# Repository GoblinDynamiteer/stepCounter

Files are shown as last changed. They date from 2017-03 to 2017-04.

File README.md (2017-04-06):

<h1>stepCounter</h1>
<h2>Pocket Pedometer</h2>  

---

**Student project for course "Programming of embedded systems"**   
*Mjukvaruutvecklare inbyggda system*  
*Mölk Utbildning, Mjärdevi - Linköping*  

Members  
[Simon Karlsson](https://www.linkedin.com/in/simon-karlsson-54509aa9/)  
[Johan Kämpe](https://www.linkedin.com/in/johankampe/)  
[Dennis Bunne](https://www.linkedin.com/in/dennis-bunne-259a9783/)  

---

**Description:**  
Simple pedometer built with an Atmel Atmega328p MCU and 3-axis accelerometer.  
Steps are displayed on a small display.

---

*Current features:*
- Pocket wearable
- Battery powered
- Displays steps on display
- Modular - Support for three I2C devices

*Future goals / extras:*
- Smaller size
- Better step detection
- Shoe-wearable
- Bluetooth / phone-app
- Reset / on-off / screen-on switches
- Modularization (I2C devices)
- Screen sleep mode
- Long battery life
- 3D printed housing

---

Current Parts:
- Atmel Atmega328p
- Crystal oscillator 16MHz
- 2x Capacitors 22pF
- 28 pin MCU socket
- MPU-9250 Gyro / Accelerometer / Compass Unit
- Grove connectors for I2C-modules
- SSD1306 Display
- 2x Resistors 4.7kOhm for I2C Line Pull up
- LiPo 18650 Battery
- 18650 Battery holder
- Mouse housing for prototype

---

**Photos:**  
MPU-9250 Accelerometer data test with Arduino Uno  
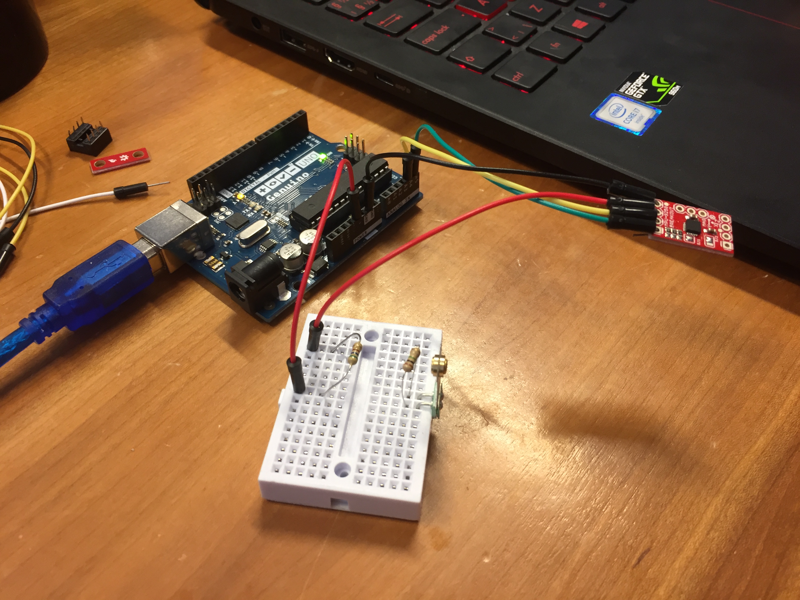
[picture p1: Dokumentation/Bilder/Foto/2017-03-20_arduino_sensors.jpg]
MPU-9250


Soldered board with connected I2C modules (Display and Accelerometer)
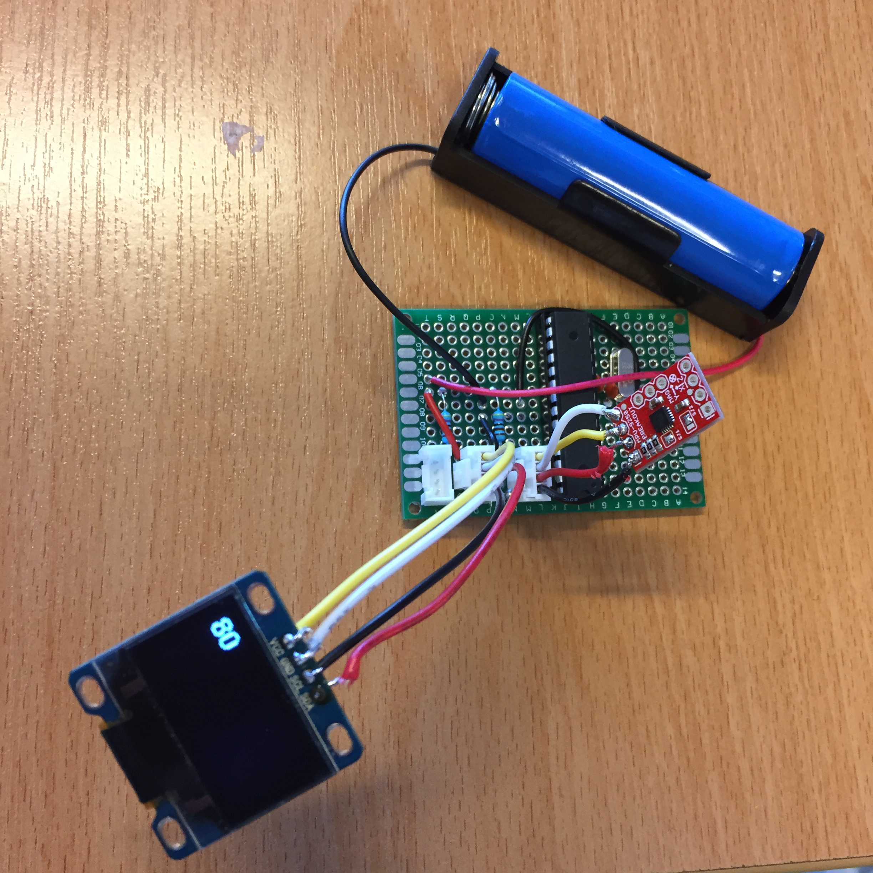
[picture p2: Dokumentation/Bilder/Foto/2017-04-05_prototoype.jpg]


Backside of board and disconnected I2C modules
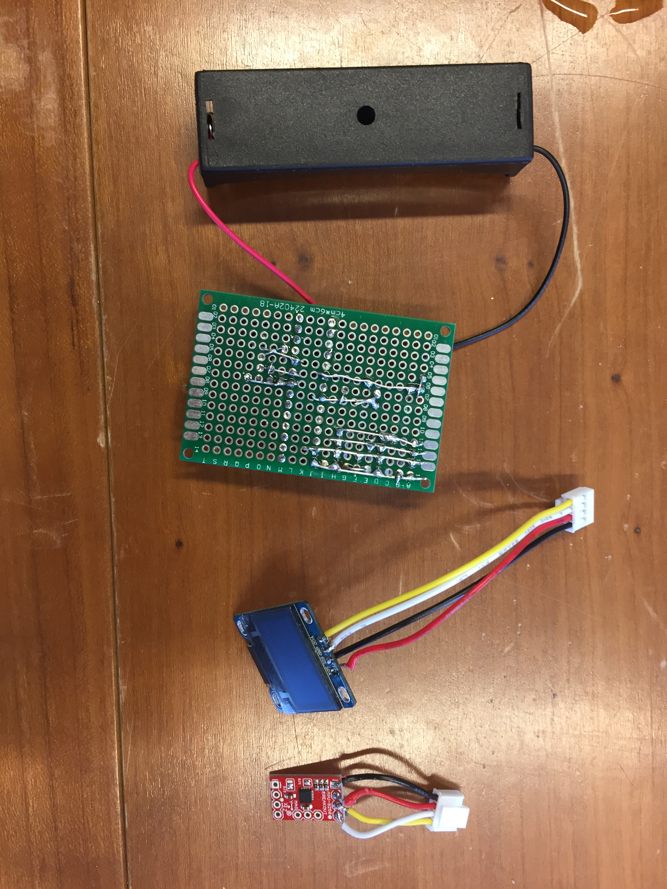
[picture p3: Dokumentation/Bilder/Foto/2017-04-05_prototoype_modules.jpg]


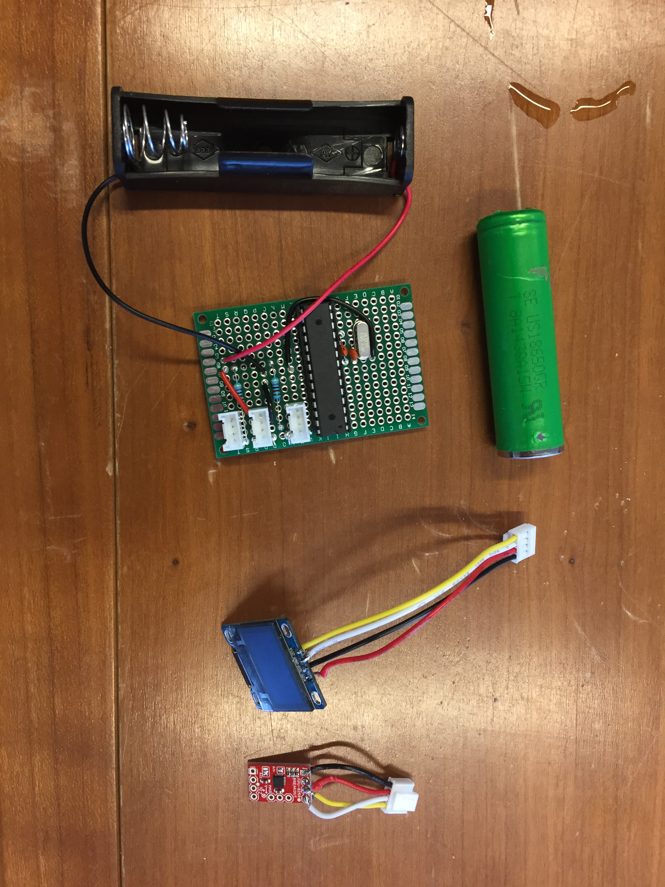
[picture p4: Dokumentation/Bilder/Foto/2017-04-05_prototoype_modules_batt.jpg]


Housing made of cannibalized mouse, tape, glue.
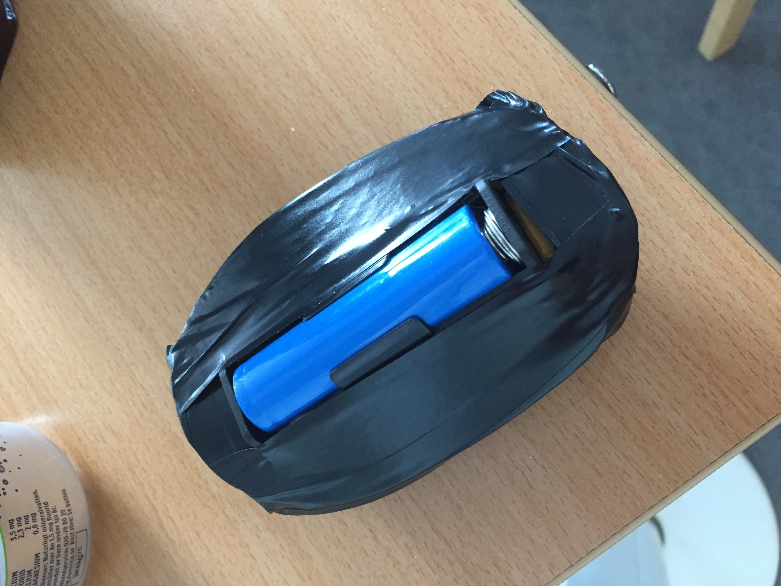
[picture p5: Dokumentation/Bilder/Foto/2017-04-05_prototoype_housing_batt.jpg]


Housing front
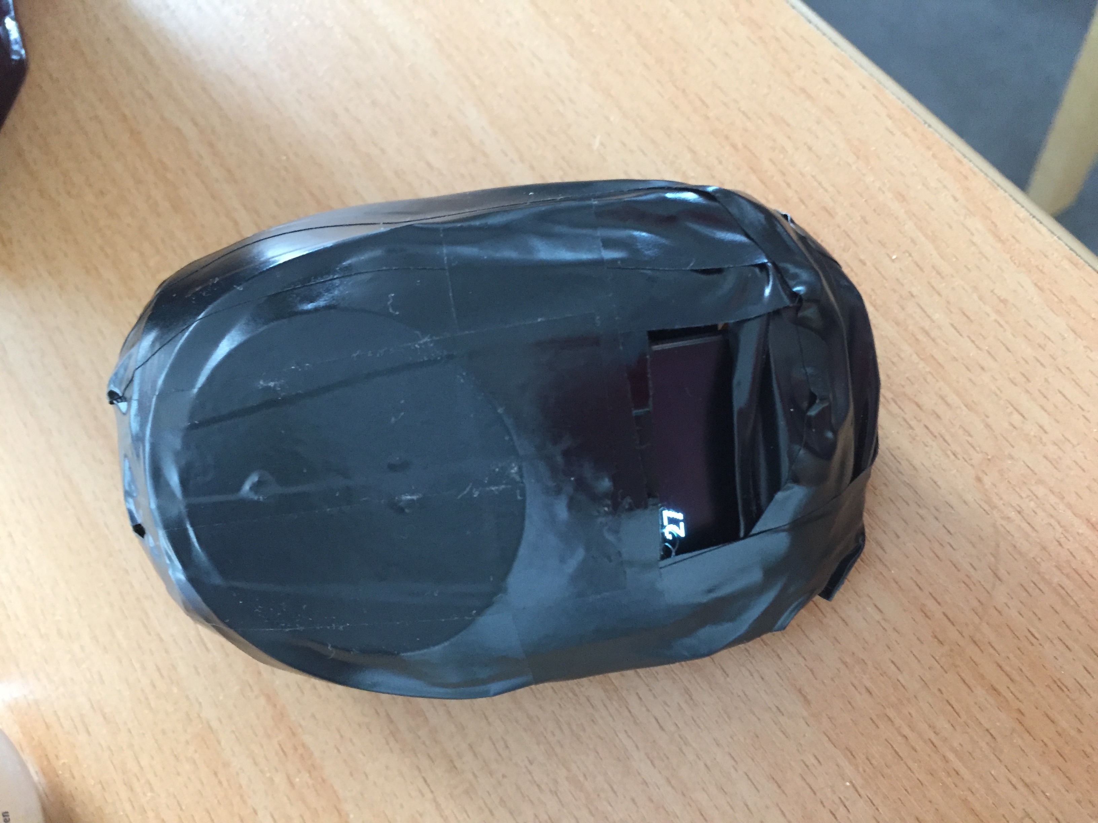
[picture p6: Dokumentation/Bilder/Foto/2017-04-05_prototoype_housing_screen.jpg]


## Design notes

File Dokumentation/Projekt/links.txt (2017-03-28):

http://www.embedds.com/programming-avr-i2c-interface/
https://github.com/g4lvanix/I2C-master-lib
http://www.nongnu.org/avr-libc/user-manual/group__twi__demo.html
http://playground.arduino.cc/Main/WireLibraryDetailedReference
https://learn.sparkfun.com/tutorials/micro-oled-breakout-hookup-guide
https://github.com/thaletterb/ssd1306_avr8

https://www.conrad.se/RC-Batteripack-%28LiPo%29-Hubsan-3.7-V-380-mAh-Flatstiftskontakt.htm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
https://www.conrad.se/RC-Batteripack-%28LiPo%29-ACME-3.7-V-600-mAh-Flatstiftskontakt.htm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
https://www.batteriexperten.com/sv/artiklar/cr2477-panasonic-1-pack.html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

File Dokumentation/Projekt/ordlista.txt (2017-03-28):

PWM: Port(ar) på Atmega328p etc. Pulse Width Modulation - Sätt att simulera analog signal med digital output
AREF: Analog Reference, port på Atmega328p etc
Pull Up-resistor: En högohmig resistor som kopplas mellan signalkabel och +V. Förhindrar störningar (etc?)
MPU-9250: Multichip Module (MCM) som har 3-axel gyro, 3-axel accelerometer, 3-axel magnetometer och DMP (Digital Motion Processor)
Accelerometer: En typ av mätgivare vilken ger ifrån sig en elektrisk signal som på något sätt är proportionell mot den hastighetsförändring (acceleration) givaren utsätts för. 
Magnetometer: Ett vetenskapligt mätinstrument som används för att mäta styrkan och/eller riktningen hos magnetfältet runt instrumentet. Kan användas för kompassfunktionalitet.
VDD: Benämning på anslutning för strömkälla på enheter (IC-kretsar etc), pluspol.

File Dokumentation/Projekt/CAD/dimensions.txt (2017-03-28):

Atmega328p: 		37.4 x 6.76 x 3.28 mm
Micro OLED:		Skärm: 18.5 x 18 mm
			Kort: 21 x 20 mm
MPU-9250:		MÄT!
ESP8266:		MÄT!
KopplingsPlatta:	TBD/CAD

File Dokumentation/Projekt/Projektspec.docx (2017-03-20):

# Stegräknare

Projektspecifikation

2017-03-20

Dennis Bunne
Johan Kämpe
Simon Karlsson

Mjukvaruutvecklare inbyggda system
Mölk Utbildning

# Projektmål

Målet är att bygga en portabel batteridriven stegräknare som kan användas vid löpning eller promenader etc. Initialt används en LCD-display för att visa antal steg. Stegen ska avläsas med hjälp av en accelerometer, eller alternativt med en vibrationssensor.

Stegräknaren kan senare utökas med hastighetsmätare, tidräkning, ESP-modul för att skicka data m.m, om funktionen med stegräkning fungerar korrekt.

# Prototyp

Ett första steg i projektet är att bygga en prototyp med hjälp av ett Arduino-kort och en accelerometer, alternativt en vibrationssensor.

Vanliga hopp kommer användas för att se att accelerometern/vibrationssensorn kan avläsa steg på ett korrekt sätt.

Data från accelerometern skrivs ut i Arduino IDEts Serial monitor.

Strömförsörjning sker via kabel.

# Moduler

Basenheten kommer bestå av en fristående MCU eller en Arduino Nano, samt strömförsörjning. Moduler kopplas in med kontakter.

En första modul är accelerometern eller vibrationssensorn.

Extra moduler: ESP, display.

# Avgränsning

Stegräknaren ska enbart behöva fungera i 20 minuter på batteriförsörjning.

# Förutsättningar

Projektet ska vara färdigställt senast 2017-05-05.

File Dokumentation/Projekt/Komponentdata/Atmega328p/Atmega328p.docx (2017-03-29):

UART är en förkortning för "Universal Asynchronous Receiver/Transmitter" och är en datorhårdvara som omvandlar parallell data till seriell data. En UART tar en byte data och överför dessa sekventiellt bit för bit till en annan UART i andra änden som sätter ihop dessa till en byte igen. Start- och stoppbitar används för att signalera när data skickas.

En synkron variant finns också, USART eller "Universal Synchronous/Asynchronous Receiver/Transmitter". Den använder inte start- och stoppbitar utan en delad klocksignal håller reda på när bitarna kommer. Synkron kommunikation är effektivare eftersom endast databitar(block) skickas mellan sändare och mottagare, men det kräver också att sändare och mottagare har tillgång till samma klocksignal.

USART har även en data/clock recovery som används för att sätta buad rate clock hastigheten(Baud rate (in bits per second, bps) och ta emot asynchronous bitar på RxDn pin. Om man får felmeddelanden på UARTen så brukar de vara pga att clock frekvensen inte är satt till rätt värde.

TWI - 2-wire Serial Interface. Features

• Simple, yet Powerful and Flexible Communication Interface, only two Bus Lines Needed

• Both Master and Slave Operation Supported

• Device can Operate as Transmitter or Receiver

• 7-bit Address Space Allows up to 128 Different Slave Addresses

• Multi-master Arbitration Support

• Up to 400kHz Data Transfer Speed

• Slew-rate Limited Output Drivers

• Noise Suppression Circuitry Rejects Spikes on Bus Lines

• Fully Programmable Slave Address with General Call Support

• Address Recognition Causes Wake-up When AVR is in Sleep Mode

• Compatible with Philips’ I2C protocol

Det ända som behövs för att koppla 128 olika enheter till TWI (SDA,SCL ) är en pull-up resistor på vardera kanal.

TWI består av 9bits samt en master och en slave. Där master utfärdar ett START/STOPP vilkor, vilket signalerar och ändrar nivån på SDA/SCL kanalerna.

Alla slavenheter som är inkopplade kommer kolla efter SDA kanalen i ACK cykeln(ACK är den 9e biten inte fatt fram så mycket info om det) om det finns datapaket att hämta.

Dessa slavar måste hämta datan från addresser och inte readbit. Använder man readbit skulle det medföra fel om olika slavar skickar data samtidigt.

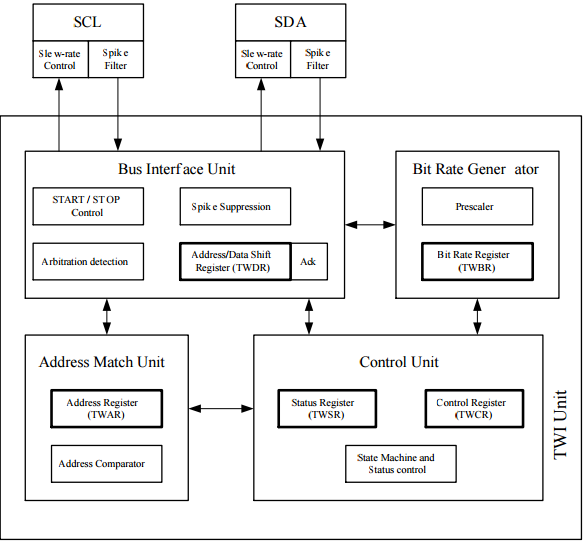
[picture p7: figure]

Bit Rate Generator Unit This unit controls the period of SCL when operating in a Master mode. The SCL period is controlled by settings in the TWI Bit Rate Register (TWBRn) and the Prescaler bits in the TWI Status Register

Bus Interface Unit This unit contains the Data and Address Shift Register (TWDRn), a START/STOP Controller

Address Match Unit The Address Match unit checks if received address bytes match the seven-bit address in the TWI Address Register (TWARn).

Control Unit The Control unit monitors the TWI bus and generates responses corresponding to settings in the TWI Control Register

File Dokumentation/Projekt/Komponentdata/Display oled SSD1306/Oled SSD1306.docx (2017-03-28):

# Oled SSD1306

- Upplösning: 128x64 dot matrix panel
- Spänning: 1.65V till 3.3V IC logic. 7V till 15V för panel driving

Oscillator finns inbyggt. (CLS-pin) Om CLS-pin = HIGH så är den interna oscillatorn vald.
Ändra frekvensen med kommandot D5h A [7:4].

SDAout = D2-pin, SDAin = D1-pin, SCL = D0-pin.

SDA och SCL måste va kopplade med varsin pullupresistor.

SSD1306 has to recognize the slave address before transmitting or receiving any information by the I 2 C-bus. The device will respond to the slave address following by the slave address bit (“SA0” bit) and the read/write select bit (“R/W#” bit) with the following byte format, b7 b6 b5 b4 b3 b2 b1 b0 0 1 1 1 1 0 SA0 R/W#

“SDAIN” and “SDAOUT” are tied together and serve as SDA. The “SDAIN” pin must be connected to act as SDA. The “SDAOUT” pin may be disconnected. When “SDAOUT” pin is disconnected, the acknowledgement signal will be ignored in the I2 C-bus.

Write mode for I2C

1) The master device initiates the data communication by a start condition. The definition of the start condition is shown in Figure 8-8. The start condition is established by pulling the SDA from HIGH to LOW while the SCL stays HIGH.
2) The slave address is following the start condition for recognition use. For the SSD1306, the slave address is either “b0111100” or “b0111101” by changing the SA0 to LOW or HIGH (D/C pin acts as SA0).

3) The write mode is established by setting the R/W# bit to logic “0”.
4) An acknowledgement signal will be generated after receiving one byte of data, including the slave address and the R/W# bit. Please refer to the Figure 8-9 for the graphical representation of the acknowledge signal. The acknowledge bit is defined as the SDA line is pulled down during the HIGH period of the acknowledgement related clock pulse.
5) After the transmission of the slave address, either the control byte or the data byte may be sent across the SDA. A control byte mainly consists of Co and D/C# bits following by six “0” ‘s.
a. If the Co bit is set as logic “0”, the transmission of the following information will

contain data bytes only.
b. The D/C# bit determines the next data byte is acted as a command or a data. If the

D/C# bit is set to logic “0”, it defines the following data byte as a command. If the

D/C# bit is set to logic “1”, it defines the following data byte as a data which will be

stored at the GDDRAM. The GDDRAM column address pointer will be increased by

one automatically after each data write.
6) Acknowledge bit will be generated after receiving each control byte or data byte.
7) The write mode will be finished when a stop condition is applied. The stop condition is also defined in Figure 8-8. The stop condition is established by pulling the “SDA in” from LOW to HIGH while the “SCL” stays HIGH.

The GDDRAM is a bit mapped static RAM holding the bit pattern to be displayed. The size of the RAM is 128 x 64 bits and the RAM is divided into eight pages, from PAGE0 to PAGE7, which are used for monochrome 128x64 dot matrix display, as shown in Figure 8-13.

Sida 25 finns en bild över displayens struktur.

# Display av och på

1. Power ON VDD
2. After VDD become stable, set RES# pin LOW (logic low) for at least 3us (t1) (4) and then HIGH (logic high).

3. After set RES# pin LOW (logic low), wait for at least 3us (t2). Then Power ON VCC. (1)

4. After VCC become stable, send command AFh for display ON. SEG/COM will be ON after 100ms (tAF).

# Kommandon

HEX: 81 A[7:0] För contrast kontroll.
HEX: AE För att sätt igång displayen.
HEX: AF För att stänga av displayen.
HEX: 40~7F Start position ersätt 40 med ett tal mellan 0-63.
HEX D3 A[5:0] Display offset

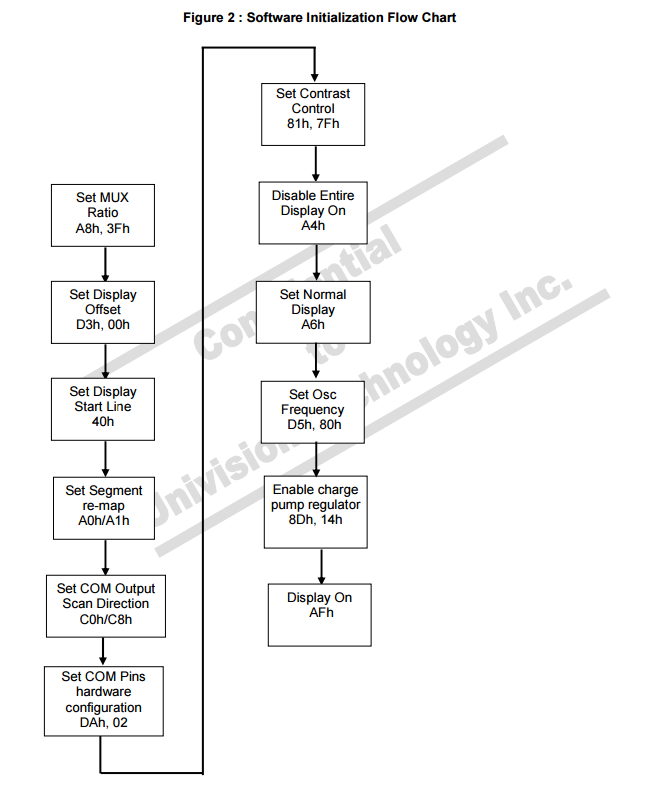
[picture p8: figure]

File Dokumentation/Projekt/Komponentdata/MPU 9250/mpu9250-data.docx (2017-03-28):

# MPU 9250

Information från datablad:
stepCounter\Dokumentation\Komponenter\MPU 9250\MPU-9250-Datasheet.pdf
stepCounter\Dokumentation\Komponenter\MPU 9250\MPU-9250-Register-Map.pdf
stepCounter\Dokumentation\Komponenter\MPU 9250\SparkFun_MPU-9250_Breakout.pdf

# Allmänt

Komponenter innehåller

- 3-axligt (X- Y och Z-riktning) gyroskop
- 3-axlig accelerometer
- 3-axlig magnetometer

# Drivning

Drivs på 2,4V – 3,6V.
OBS - max drivspänning är 4 V, för att undvika att komponenten tar skada.

Strömförbrukning:

Komponent | Normal | Sleep/Low Power
Gyroskop | 3,2 mA | 8 µA
Accelerometer | 450 µA | 8 µA
Alla funktioner påslagna | 3,5 mA

I databladet används en (keramisk X7R) kondensator på 0,1 µF på inspänningen VDD, för en typisk uppkoppling.

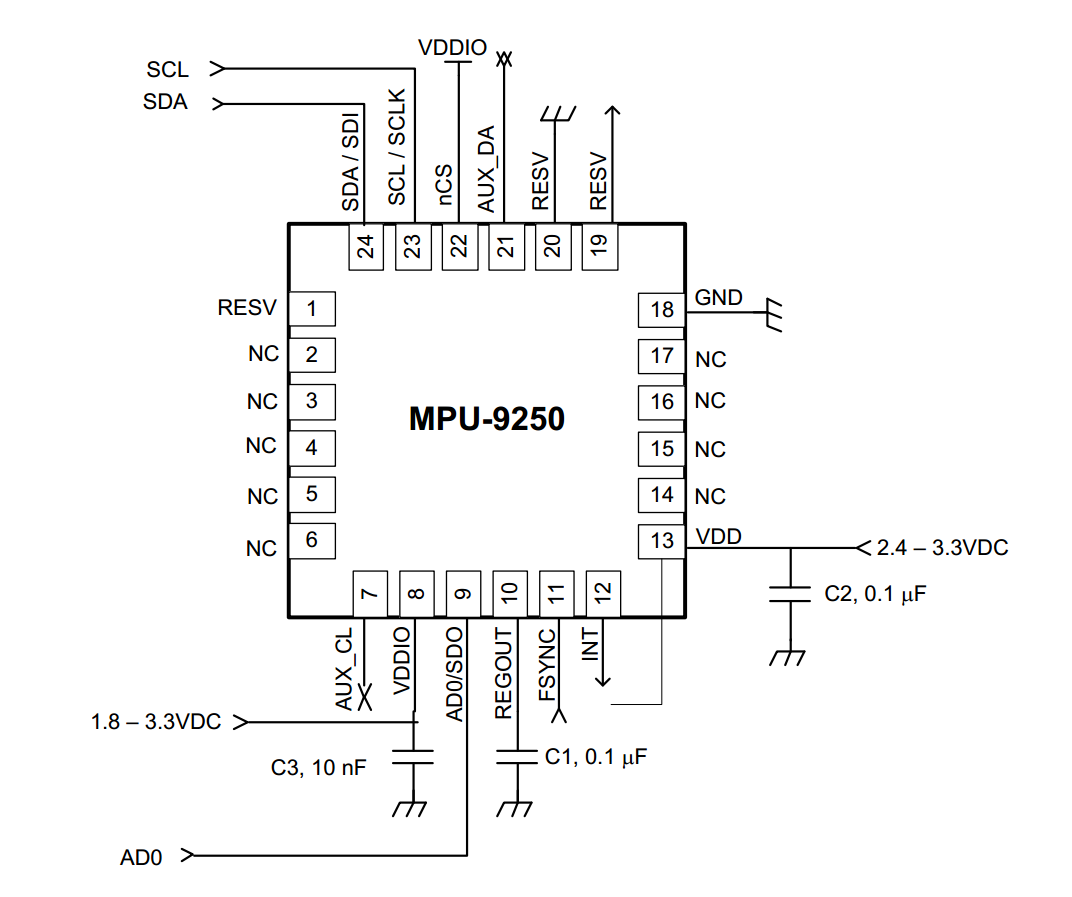
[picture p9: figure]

Bypass capacitor: https://www.solo-labs.com/bypass-capacitors-why-and-how-to-use-them/

# Kommunikation

I2C på 400 kHz (standard-mode) eller 100 kHz (standard mode)
SPI på 1 MHz.

Externa I2C-enheter kan anslutas, och drivas med spänning från VDDIO på 1,71 V till VDD V

I2C-adress: b110100X

Pin AD0 kan/ska sättas till VDD eller GND för att sätta 1/0 för LSB (X) till enhetens I2C-slavadress. Detta innebär att två MPU 9250-enheter kan användas på samma I2C-kanal.
Enl. Sparkfun är denna 0 som standard för deras breakout-board.

# Accelerometer

Startup-tid: 20 ms från sleep mode, 30 ms från påslagning av MPU 9250.

Om enheten placeras på en plan yta ges värden: X, Y: 0 g, Z: +1 g.

# Anslutningar

AUX_CL (7): Anslutning av externa I2C enheter.
AUX_DA (21): Anslutning av externa I2C enheter.
FSYNC (11): Ska kopplas till GND om ej används, enl. datablad
AD0: Sätt till VDD/GND för att styra LSB på I2C-adress. Default 0

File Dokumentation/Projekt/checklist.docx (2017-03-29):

# Projekt Pedometer

Dennis Bunne
Johan Kämpe
Simon Karlsson

# Checklista

VAD | VEM | SLUTDATUM | KLAR
Ta reda på och dokumentera data för: MPU 6050 / MPU 9250 | JOHAN | 2017-03-27 | JA
Ta reda på och dokumentera data för: MCU Atmega328p | SIMON | 2017-03-27 | JA
Ta reda på och dokumentera data för: OLED Display | DENNIS | 2017-03-27 | JA
Undersök och dokumentera koden för kodbibliotek avr_lib_mpu6050 – funktionsbibliotek för MPU 6050 | SIMON JOHAN DENNIS | 2017-03-23 | JA
Dokumentera dimensioner/storlek för samtlig hårdvara | JOHAN | 2017-03-27
Beräkna och dokumentera strömförbrukning för hårdvara | SIMON JOHAN DENNIS | 2017-03-28 | JA
Skapa CAD-modell för prototyp-hölje | JOHAN | 2017-04-03
Bygg hölje utifrån CAD-modell (3D-skrivare?) | SIMON JOHAN DENNIS
Ta reda på lämplig batterityp – Dokumentera beräkning | SIMON | 2017-03-28
Lödning av kontakter – för modularisering | SIMON JOHAN DENNIS | TBD
Montera komponenter på kretskort | SIMON JOHAN DENNIS | TBD
Kom på sätt att visa antal steg med lysdioder – för testning. Dokumentera! | JOHAN | 2017-03-28
Kodning: Bygg funktioner för att hämta data för acceleration för X/Y/Z från MPU | SIMON JOHAN DENNIS | 2017-03-29 | JA
Kodning: Färdigställ kod till leverans 1 | SIMON JOHAN DENNIS | 2017-04-03
Hitta kodbibliotek för OLED-display. | DENNIS | 2017-03-28 | JA
Skapa kretsschema för uppkopplad MPU till Atmega328p och OLED-display. | DENNIS | 2017-03-31
Städa upp i Git-repository. Sortera/namngivning | JOHAN | 2017-03-27 | JA

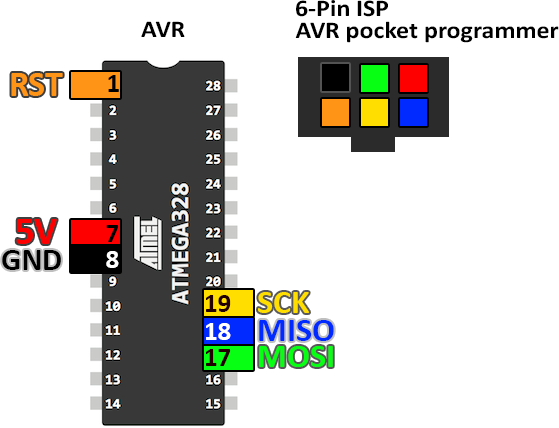
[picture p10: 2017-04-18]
Dokumentation/Projekt/Report/images/pocket_avr_programmer.png

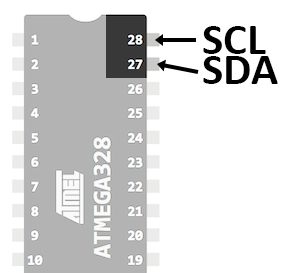
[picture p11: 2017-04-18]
Dokumentation/Projekt/Report/images/atmega_twi_pins.png

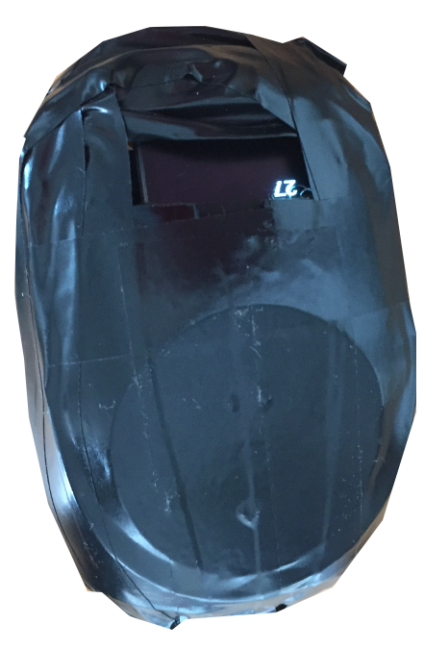
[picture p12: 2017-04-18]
Dokumentation/Projekt/Report/images/proto2_hus2.png

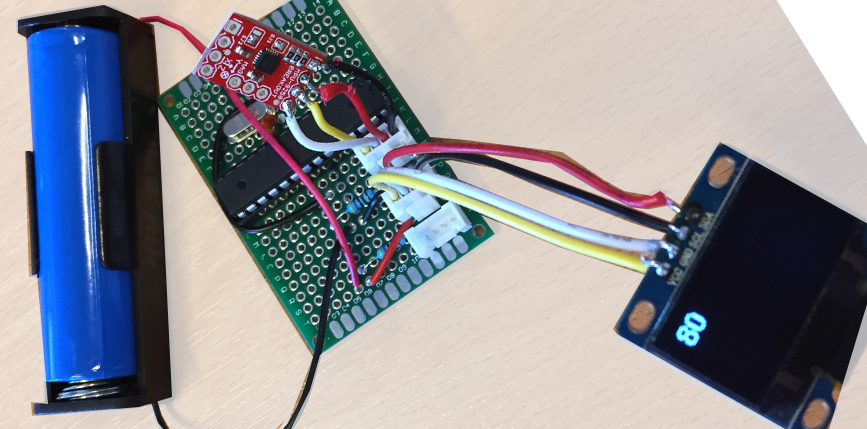
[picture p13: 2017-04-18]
Dokumentation/Projekt/Report/images/proto2_inkopplad.png

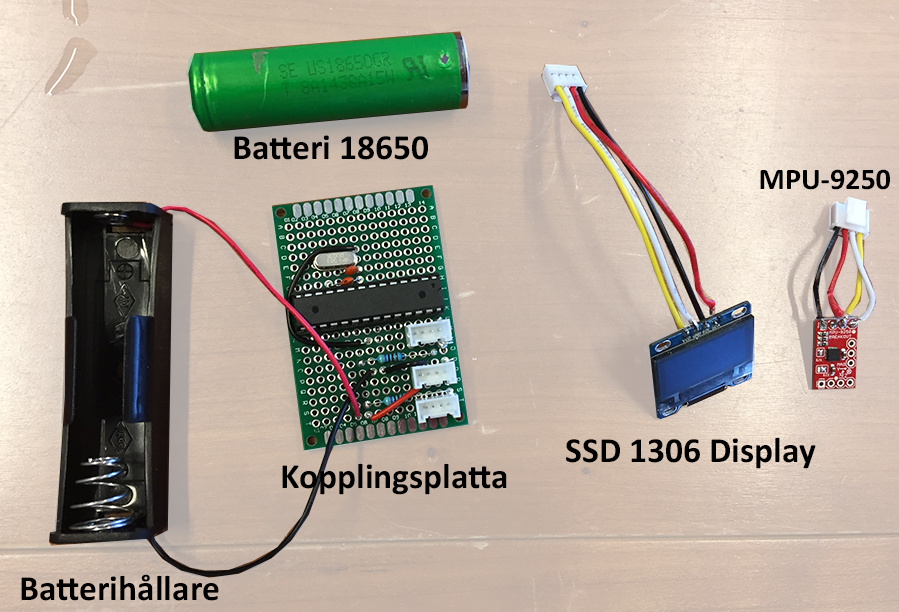
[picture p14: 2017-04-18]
Dokumentation/Projekt/Report/images/proto2_urkopplad.png

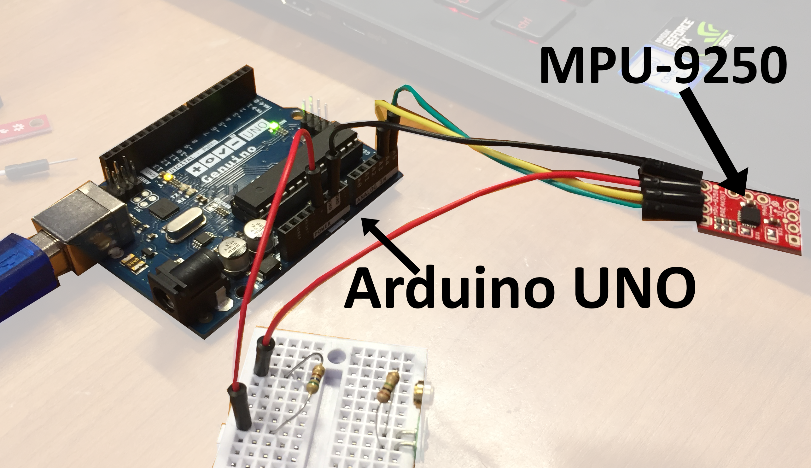
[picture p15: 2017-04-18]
Dokumentation/Projekt/Report/images/proto1.png

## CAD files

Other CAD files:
CAD/Inventor Project/assembly/atmega.iam
CAD/Inventor Project/assembly/socket.iam
CAD/Inventor Project/parts/atmega_mold.ipt
CAD/Inventor Project/parts/atmega_pin-end.ipt
CAD/Inventor Project/parts/atmega_pin-end_MIR.ipt
CAD/Inventor Project/parts/atmega_pin.ipt
CAD/Inventor Project/parts/socket.ipt
CAD/Inventor Project/parts/socket_pin.ipt
CAD/Inventor Project/stepCounterHousing.iam

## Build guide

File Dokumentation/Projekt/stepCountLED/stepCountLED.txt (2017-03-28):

Visa antal steg med LED:

Alternativ / Förslag:

***** 8 st LED *****************************
Binärt med 8 st LED: MAX 1111 1111 = 255 st.

***** 4 st RGB LED *************************
RGB-LED:
AV 00
R  01
G  10
B  11

Behövs 4st för 8 bitar för binär representation.
ingen direkt fördel över 8 st LED, dock behövs ej resistorer.

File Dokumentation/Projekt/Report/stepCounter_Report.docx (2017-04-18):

# Stegräknare

Projekt: Pedometer med AVR

Kurs
Programmering av inbyggda system

2017-04-19

SNYGG BILD?!

Dennis Bunne LinkedIn (https://www.linkedin.com/in/dennis-bunne-259a9783/) | Johan Kämpe LinkedIn (https://www.linkedin.com/in/johankampe/) | Simon Karlsson LinkedIn (https://www.linkedin.com/in/simon-karlsson-54509aa9/)

Mjukvaruutvecklare Inbyggda System
MÖLK Utbildning AB (http://dev.molk.com/)

# Sammanfattning

Skriv när klar

# 1 Inledning

## 1.1 Syfte

Syftet med projektet är att tillverka en bärbar, batteridriven stegräknare. Stegräknaren ska ha modulära enheter, det vill säga att dessa går att ta bort eller byta ut. En modulär enhet kan vara en display, blåtandsmodul eller accelerometer.

En display används för att visa antal tagna steg. Stegen ska avläsas med hjälp av en accelerometer, eller alternativt med en vibrationssensor.

## 1.2 Noteringar och information

Projektet utfördes på under perioden mars till april, 2017.

I rapporten hänvisas själva stegräknaren ofta till som projektet eller produkten.

I rapporten hänvisas MPU-9250-enheten, som används för att mäta acceleration, ofta som MPU-enheten, eller MPU-n.

## 1.3 Bakgrund

### 1.3.1 Definitioner av begrepp och förkortningar

Term | Förklaring
Acceleration | Förändring av hastighet per tidsenhet. Kan vara positiv (hastighetsökning) eller negativ (minskad hastighet).
Arduino UNO | Utvecklingskort.
Atmega328p | En mikrokontroller (MCU) med 28 anslutningar, från tillverkaren Atmel
AVR | Familj av Mikrokontrollers som tillverkas av företaget Atmel.
Bibliotek | En samling av kod-funktioner och/eller definitioner.
Breadboard | Kopplingsplatta, används för att ansluta enheter till varandra.
C | Det programmeringsspråk som används i projektet.
DIL | Dual in-line. Standard för mikrochip med två rader av ben.
Git | Ett versionshanteringssystem
GitHub | Molnlagring för Git-projekt
I²C | Ett sätt att koppla samman enheter, via två ledare: SCL och SDA.
IDE | Integrated Development Environment. Ett datorprogram eller en programsvit som vanligtvis innehåller en texteditor, kompilator och debugger. För att underlätta vid programmering.
ISP | In-system programming, programmering av redan installerade eller inbyggda system.
LED | Light Emitting Diode, lysdiod.
Lib | Se Bibliotek.
Library | Se Bibliotek.
MCU | Microcontroller Unit, se Mikrokontroller.
Mikrokontroller | En liten enchippsdator med CPU, arbetsminne och programminne.
Mikroprocessor | SKRIV
MPU | Microprocessor Unit, Se mikroprocessor
MPU-6050 | Mikroprocessor med sensor för gyro och acceleration i tre riktningar vardera.
MPU-9250 | Mikroprocessor med sensor för gyro, acceleration och kompass i tre riktningar vardera.
Pull up-reistor | Används i logiska kretsar för att se till att en ingång håller sig hög när den inte har någon anslutning.
Reistans | Värdet på ett motstånd / resistor. Anges i Ohm (Ω).
Resistor | Motstånd i elektriska kretsar.
SCL | Se I²C.
SDA | Se I²C.
Serial Monitor | Funktion i Arduinos IDE, för att kommunicera med inkopplad Arduino-enhet. Används ofta för debugging.
Standardbibliotek | Kodbibliotek som alltid är tillgängliga för ett specifikt programspråk. Exempelvis stdio.h för programspråket C.
Stegräknare | En enhet som mäter hur många steg en människa tar
TWI | Se I²C.
Utvecklingsmiljö | Se IDE.
Interrupt | SKRIV

SORTERA+FYLLPÅ

### 1.3.2 Stegräknare

En stegräknare är en vanligtvis portabel enhet. Som mäter hur många steg en människa tar. Den kan användas vid exempelvis löpning, promenad, eller för att se hur många steg en person tar under en dag.

Stegräknare kan också kallas pedometer.

### 1.3.3 I²C

I²C, Inter-Integrated Circuit, är ett sätt att koppla enheter till moderkort, inbyggda system, mobiltelefoner eller andra enheter.

Kommunikation sker via två ledare, SDA (Serial Data Line, datasignal) och SCL (Serial Clock, klocksignal). Flera I²C-enheter kan anslutas till samma SDA- och SCL-ledare.

På en mikrokontroller av typen Atmega328p, är anslutningar 27 och 28, SDA och SCL, respektive.


Figur 1 I²C-ansluting på Atmega328

I²C kallas även TWI, Two Wire Interface, eller IIC.

### 1.3.4 Pull up-resistorer

Pull up-resistorer används i logiska kretsar för att se till att en ingång håller sig hög när den inte har någon anslutning.

Utan pull up kan ingången anta vilket läge som helst, hög eller låg. I projektet används pull up-resistorer för I²C-anslutningarna.

Resistorer som används ska vara av hög resistans.

### 1.3.5 MPU-9250

Enheten som används i projektet för att mäta acceleration kallas MPU-9250 IMU Breakout och är tillverkad av Sparkfun. På enheten finns en MPU-9250.

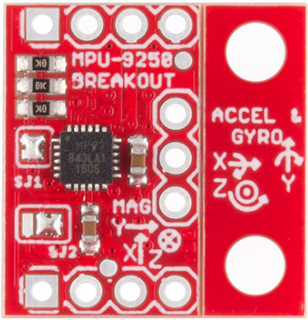
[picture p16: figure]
SparkFun IMU Breakout - MPU-9250
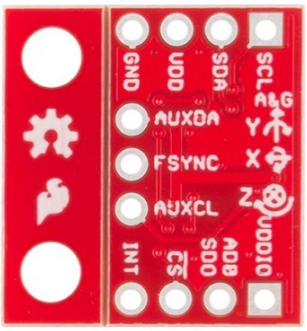
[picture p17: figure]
SparkFun IMU Breakout - MPU-9250

Figur 2 MPU-9250, framsida | Figur 3 MPU-9250, baksida med anslutningsbeteckningar

De anslutningar som används i projektet är VDD och GND för drivning, samt SDA och SCL för I²C-kommunikation.

Länk till tillverkarens produktsida finns i kapitel 1.4.4

### 1.3.6 X-Y-Z-riktning

X, Y och Z används inom projektet för att beskriva riktningar i en tredimensionell miljö. MPU-9250-enheten har sensorer för acceleration i dessa tre riktningar.

När enheten förs åt ett visst håll mäts rörelsens acceleration i denna riktning.

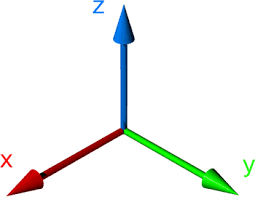
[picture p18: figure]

Figur 4 Riktningar i X- Y och Z-led

## 1.4 Länkar

### 1.4.1 GitHub

Länkar till projektets GitHub-sida

GitHub-sida för projektet
https://github.com/GoblinDynamiteer/stepCounter

GitHub-sida, huvudkod
https://github.com/GoblinDynamiteer/stepCounter/blob/master/Kod/Huvudkod/stepCounter/mpu_conntest/main.c

GitHub-sida, kod för prototyp 1
https://github.com/GoblinDynamiteer/stepCounter/blob/master/Kod/Testkod/Arduino/stepCounterPrototype/stepCounterPrototype.ino

### 1.4.2 Använda funktionsbibliotek

Länkar till bibliotek som har använts i projektets kod

MPU 6050 library
http://davidegironi.blogspot.se/2013/02/avr-atmega-mpu6050-gyroscope-and.html#.WOtTeojyhPY

U8glib
https://github.com/olikraus/u8glib

I2C master library
http://homepage.hispeed.ch/peterfleury/avr-software.html#libs

### 1.4.3 Datablad

Lista!!

### 1.4.4 Andra länkar

MPU-6050 Accelerometer + Gyro
Kodexempel
http://playground.arduino.cc/Main/MPU-6050

SparkFun IMU Breakout - MPU-9250
Produktbeskrivning
https://www.sparkfun.com/products/13762

(https://www.youtube.com/watch?v=5uytAdWNXpI)

# 1 Genomförande och resultat

## 1.1 Använd programvara

Programnamn | Beskrivning
Atmel Studio 7.0 | IDE för att skriva kod och kompilera till Atmel MCU.
Atom | Texteditor, för att skriva och analysera kod.
Git | Versionshanteringsverktyg
GitKraken | Grafiskt gränssnitt (GUI) för Git
Fritzing | Program för att skapa kretsscheman
Microsoft Word | Dokumentering och rapportskrivning
Google Docs | rapportskrivning
AVRDUDE, AVR Downloader/UploaDEr | Program för att ladda upp kompilerad kod till MCU.
AVRDUDESS | Grafiskt gränssnitt (GUI) för AVRDUDE
Autodesk Fusion 360 | CAD-program för att konstruera ett hölje till stegräknaren.

## 1.2 Använd hårdvara

Komponent | Beskrivning
Atmel ATMega328-PU DIP-28N 8-bit MCU | Mikrokontroller.
SparkFun MPU-9250 | Enhet som mäter acceleration i X, Y och Z-riktning. Innehåller även gyroskop, temperatur och kompass-funktionalitet.
Micro OLED Display SSD1306 128x64 | Display med upplösning 128x64 pixlar.
AVR pocket programmer | Enhet för att programmera Atmega-MCU via en dators USB-port.
DIL-hållare 28-pin 0.3" | Sockel för Atmega-MCU
Resistor 4,7kΩ, 2 st. | Pull up-resistorer för I²C-kanaler.
Kristalloscillator 16 MHz | Kopplas till MCU för att öka klockfrekvensen från 1 MHz till 16 MHz
Kondensator 22pF, 2 st. | Används för inkoppling av kristalloscillator.
Litiumbatteri 18650 | Strömförsörjning.
Hållare för litiumbatteri 18650
Grovekontakter med 4-stift | För modularisering av I²C-komponenter.
Kopplingsplatta 60x40 mm | För sammanlödning av komponenter.
Arduino UNO | Prototyping

## 1.3 Avgränsningar

SKRIV/EL EV. TA BORT!!!!!

## 1.4 Metod

### 1.4.1 Skrivning av källkod, kompilering och uppladdning till mikrokontroller

Programmets källkod skrevs i utvecklingsmiljön Atmel Studio, som ett GCC C Executable Project-projekt. Källkoden är skriven i programspråket C.

All egenskriven kod finns i projektets källkodsfil main.c.

Vid kompilering av koden skapas en fil med filändelsen hex i Atmel Studio-projektets Debug-underkatalog. Denna fil laddas upp till mikrokontrollern med datorprogrammet AVRDUDE och programmeringsenheten AVR pocket programmer.

Programmering utförs via ISP, följande anslutningar på mikrokontrollerns används.


Figur 5 Inkoppling av programmeraren till mikrokontrollern

Programmeringsenheten kan även användas som strömkälla.

### 1.4.2 Studie av datablad

Tidigt i projektet samlades datablad in för införskaffad hårdvara. Databladen studerades och relevant information noterades för att kunna användas vid framtagning av prototyp.

I synnerlighet studerades datablad för:

- MPU-9250
- Atmega328p
- OLED Display

### 1.4.3 Studie av funktionsbibliotek

Tidigt i projektet letades diverse färdiga kodbibliotek upp, för projektets hårdvara. Koden i dessa bibliotek studerades, eller användes för att undersöka funktionen hos olika komponenter.

Exempel på bibliotek som studerades eller användes i projektets utveckling:

Bibliotek | Beskrivning och syfte
Wire.h | I²C-bibliotek för Arduino-enheter. För att funktionstesta I²C-enheter med Arduino UNO. Användes även i koden för prototyp 1.
twitest.c | I²C-test/demo för AVR-enheter.
mpu6050.h | MPU-6050 (Accelerometer, mm.) för AVR-enheter.
i2cmaster.h | I²C-bibliotek för AVR-enheter.
ssd1306.c | Kod som använt sig av i2cmaster.h för att skriva ut text till display.

Koden studerades med bland annat texteditorn Atom och i utvecklingsmiljön Atmel Studio.

I Atmel Studio finns möjligheten att automatiskt gå till den fil där ett makro, en funktion eller en variabel är definierad. I bilden nedan utförs detta på funktionen fabs();

Figur 6 Gå till en implementation av ett makro, variabel eller funktion.

## 1.5 Prototyp 1

Projektets första prototyp, kallad prototyp 1, byggdes för att säkerställa att en stegräknare kunde konstrueras med en MPU-9250. MPU-enheten kopplades direkt till en Arduino UNO-enhet via en breadboard.

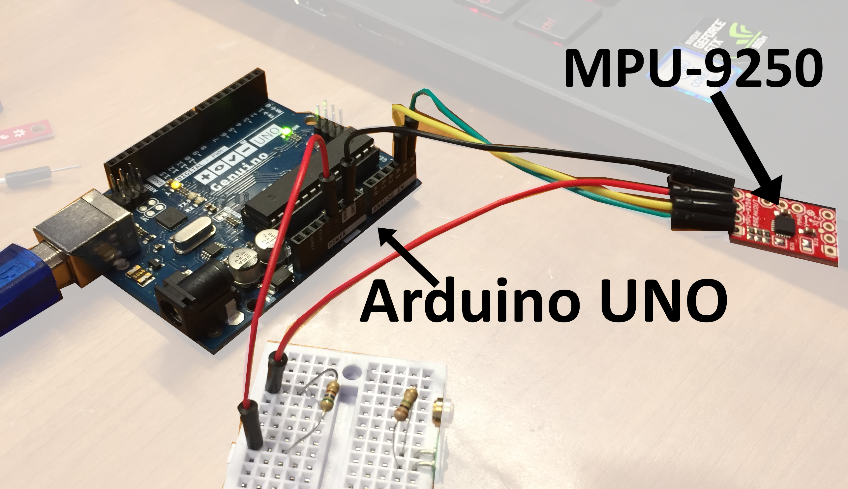
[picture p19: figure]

Figur 7 Uppkoppling av MPU-9250 till Arduino UNO

Koden för prototyp 1 baserades på kod skapad av JohnChi [^1], som skriver ut värden från MPU-6050-enheter till Arduino-utvecklingsmiljöns Serial Monitor. Koden skrevs om så att endast värden för acceleration hämtades, dessa användes för stegräkning.

Funktionsbiblioteket wire.h används för att ansluta MPU-n via I²C till Arduino-enheten. Portarna A4 och A5 används för SDA och SCL, respektive. En resistor med resistansvärdet 560 Ohm används för att ta ner spänningsmatningen till MPU-n från 5V till ca 3V. Enligt tillverkarens hemsida[^2] ska enheten drivas med 2.4 – 3.6 V.

En bärbar dator användes för strömförsörjning och för att avläsa Serial Monitor. Avläsning av steg gjordes genom att placera prototypen i en byxficka och promenera runt.

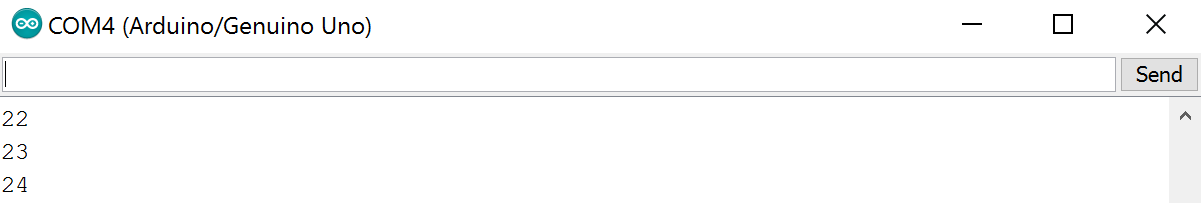
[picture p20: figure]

Figur 8 Utskrift av stegräkning till Serial Monitor

En vibrationssensor testades också för att avläsa steg. Även om den kunde användas för avläsning, valdes den att inte användas, då MPU-enheten ansågs vara mer pålitlig.

Prototyp 1 färdigställdes 2017-03-21

Kopplingsschema för prototyp 1 kan ses i rapportens bilagor.

## 1.6 Prototyp 2

Vid byggnation av prototyp 2 användes en Atmega328p MCU.

En breadboard användes för samtliga inkopplingar innan sammanlödning av enheter påbörjades.

Initialt anslöts MPU-9250-enheten till mikrokontrollerns I²C-anslutningar, med pull up-resistorer på båda kanaler. För att kunna indikera att MPU-n fungerade korrekt användes en blå LED. Lysdioden sattes att lysa när accelerationsdata från MPU-n översteg ett visst värde.

När displayen anslöts och kunde användas för att visa diverse data från MCU-n, blev lysdioden överflödig och användes inte längre.

En kristalloscillator på 16 MHz kopplades MCU-enhetens anslutningar 9 och 10. Dessa anslutningar används för inkoppling av externa kristalloscillatorer. Kristalloscillatorn användes för att öka klockfrekvensen på MCU-n. Enheten upplevdes också som stabilare.

När uppkopplingen på breadboard ansågs vara fungerande löddes MCU-n fast via en sockel på en kopplingsplatta. Tre stycken kontakter löddes till MCU-ns I²C-kanaler. Dessa kontakter går att använda för att koppla in olika enheter med I²C-stöd.

På displayen och MPU-enheten löddes kontakter fast, för anslutning till kontakterna på kopplingsplattan.

På kopplingsplattan löddes även övriga komponenter dit: kristalloscillator, resistorer och kondensatorer.


Figur 9 Lödda och urkopplade modulära komponenter

Ett en kasserad optisk mus användes som hölje för prototyp 2. Eltejp och smältlim användes för sammanfogning.

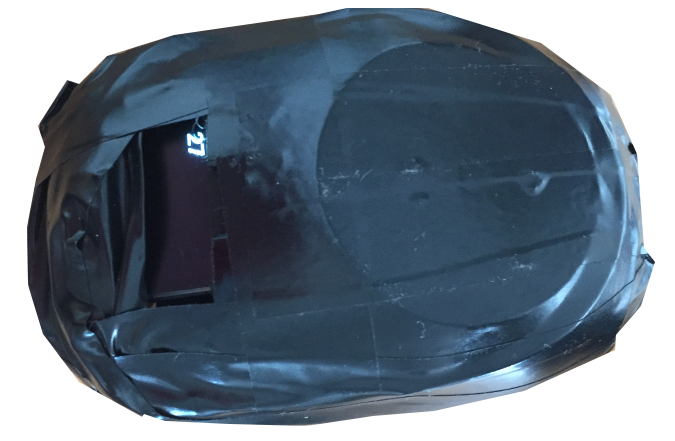
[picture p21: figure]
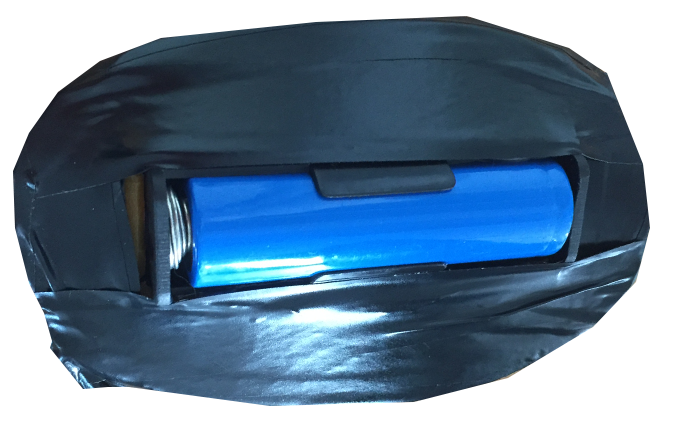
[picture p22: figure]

Figur 10 Prototyp 2 med hölje, framsida med display | Figur 11 Prototyp 2 med hölje, baksida med batteri

Efter sammanställning av prototyp 2, plockades delarna ut ur höljet, och en ytterligare anslutning löddes på kopplingsplattan, för programmering av mikroprocessorn via AVR pocket programmer.

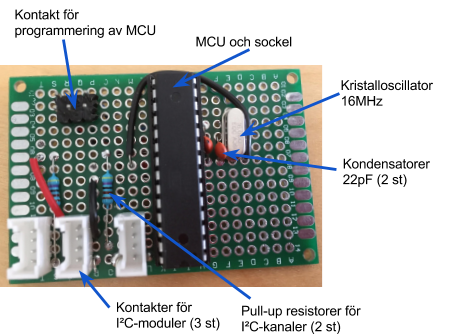
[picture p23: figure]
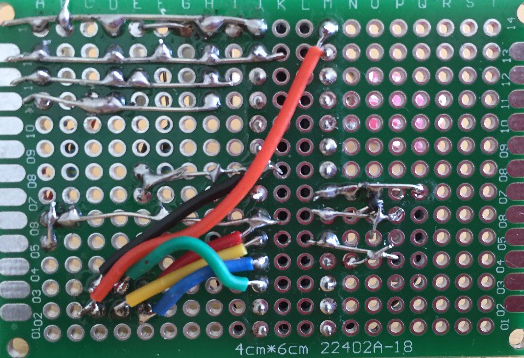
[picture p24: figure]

Figur 12 Placering av fastlödda komponenter på kopplingsplatta | Figur 13 Komponenter lödda på kopplingsplatta, baksida

Prototyp 2 används som bas för den färdigställda produkten.

Kopplingsschema för prototyp 2 kan ses i rapportens bilagor.

## 1.7 Slutgiltig produkt

Text

## 1.8 Stegräknarens funktion

Vid stegräknarens start kalibreras den genom att hämta 20 stycken värden för acceleration från MPU-9250-enheten. Stegräknaren bör ligga stilla under kalibreringen. Medelvärdet av de 20 värdena sätts till att vara stegräknarens värde för när den är passiv. Detta värde benämns som idle-värde.

Meddelandet "Calibrating.." visas på stegräknarens display under kalibreringen. När kalibreringen är färdig visas meddelandet "Idle.." på displayen, och stegräknaren kan börja användas.

Under användning hämtas accelerationsdata kontinuerligt från MPU-9250-enheten. Skillnaden mellan detta värde och idle-värdet beräknas som ett absolutvärde. Om skillnaden mellan dessa två värden överskrider ett visst satt tröskelvärde, så anses det att ett steg har tagits.

Vid varje taget steg uppdateras stegräknarens display med det totala antalet tagna steg.

Stegräknarens display sätts automatiskt i sömnläge om inget steg har tagits på ca 30 sekunder. Displayen vaknar automatiskt när ett steg tas.

## 1.9 Projektets kod

Utförligare kommentering av koden finns i källkodsfilen main.c.[^3]

### 1.9.1 Egeninkluderade standardbibliotek

Bibliotek | Beskrivning
<avr/io.h> | Diverse I/O definitioner för mikrokontrollern.
<util/delay.h> | För funktionen _delay_ms() som pauserar programmet i angiver antal millisekunder.
<avr/interrupt.h> | Används för funktionen sei(), som aktiverar interrupt på mikrokontrollern. Behövs för kommunikation med MPU-9250.
<math.h> | Diverse matematikfunktioner och macron. Används för funktionen fabs(), som ger absolutvärdet av ett tal.
<stdio.h> | För funktionen sprintf(), som skriver en formaterad textsträng till en char-array. Används för att skriva ut stegräkning till display.

### 1.9.2 Inkluderade icke-standardbibliotek

Flera av dessa bibliotek har egna inkluderingar av olika standardbibliotek.

Bibliotek | Beskrivning
"i2chw/i2cmaster.h" I2C master library using hardware TWI interface Skapat av Peter Fleury | I²C-funktionalitet för AVR-enheter. För kommunikation mellan mikrokontroller och enheter anslutna till dess I²C-portar SDA/SCL.
"mpu6050/mpu6050.h" MPU6050 lib 0x02 Skapat av Davide Gironi | För accelerometer-enheten, via I²C. Viss egen kod har skrivits genom att bryta ut kod från detta bibliotek.
"u8g/u8g.h" Universal 8bit Graphics Library Skapat av olikraus | Funktionsbibliotek till AVR för diverse displayer.

### 1.9.3 Macron definierade i main.c

Macron som är definierade i main.c

Namn | Värde | Beskrivning
X | 0x3B | Address för accelerometerdata i X-riktning i MPU-9250
Y | 0x3D | Address för accelerometerdata i Y-riktning i MPU-9250
Z | 0x3F | Address för accelerometerdata i Z-riktning i MPU-9250
STEP_ACC_TRIGGER | 2.3 | Tröskelvärde för acceleration, att bestämma om ett steg har tagits.
SET_IDLE_LOOP | 20 | Antal värden som ska hämtas från accelerometern för att bestämma “idle”-värde. Det värde som accelerometern ger när den anses ligga stilla.
DISPLAY_LINE_HEIGHT | 16 | Pixelhöjd för en rad på displayen. Används vid utskrift av text.
DISPLAY_MIDDLE | (DISPLAY_LINE_HEIGHT * 2 + 2) | Ungefärligt pixelvärde för utskrift på displayens mitt.
DISPLAY_SLEEP_DELAY | 3000 | När värdet i variabeln displaySleepTimer når detta värdet sätts displayen i sömnläge.

Macrot F_CPU behövs vara angivet för standardbiblioteket delay.h, detta sätts i kodprojektets egenskaper till F_CPU=16000000, i programmet Atmel Studio.

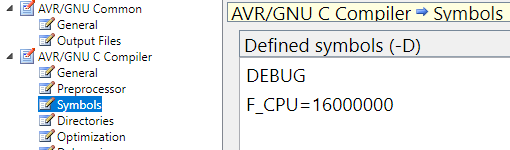
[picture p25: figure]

Figur 14 Kodprojektets egenskaper – Defined symbols

### 1.9.4 Macron från andra bibliotek

Macron som används i main.c, vilka är definierade i andra bibliotek.

Namn | Värde | Från bibliotek | Beskrivning
MPU6050_ADDR | (0x68 <<1) | mpu6050.h | I²C-address för MPU-9250
MPU6050_AGAIN | 16384.0 | mpu6050.h | Värde för att omvandla ”rå” accelerationsdata från MPU-9250 till g-krafter.
I2C_WRITE | 0 | i2cmaster.h | Datariktning för I²C - för att skriva till en enhet.
I2C_READ | 1 | i2cmaster.h | Datariktning för I²C - för att läsa från en enhet

### 1.9.5 Variabler

Variabler i källkoden, sätts i main.c

Namn | Beskrivning
uint16_t steps | Håller stegräkning.
double accIdle | Värde som sätts vid programmets uppstart, håller det värde som accelerometern ger när den ligger helt stilla.
double accCombined | Sammansatt accelerationsvärde från X- Y- och Z-riktning.
double accX, accY, accZ | Värden för acceleration i X- Y- och Z-riktning.
int displaySleeping | Håller displayens sömnläge, sätts till 1 om displayen är i sömnläge, annars 0.
int displaySleepTimer | Används som timer för displayens sömnläge. Ökar med 1 för varje varv i programmets huvudloop.
u8g_t u8g | Struct för biblioteket Universal 8bit Graphics Library, för display.

### 1.9.6 Funktioner

Egenskrivna funktioner i källkoden

Namn | Beskrivning
double getAcc(int addr); | Hämtar accelerationsdata från MPU och ger värdet i retur. Som argument tar funktionen adressen till det register som ska läsas. Dessa adresser är definierade som macron X, Y och Z.
void drawSteps(uint16_t steps); | Skriver ut aktuellt antal steg till displayens mitt, som "Steps: x"
void drawString(char * string, int line); | Skriver ut en text till displayen. Texten ges som argument till funktionen, i form av en pekare till en char-sträng. Line är den rad på displayen där texten ska visas.
void setAccIdle(); | Sätter ett värde till den globala variabeln accIdle. Funktionen körs endast en gång vid varje uppstart av programmet.
double getAccXYZ(void); | Använder sig av funktionen getAcc() för att hämta accelerationsdata från X-, Y- och Z-riktningen. Det adderade värdet ges i retur.
void toggleDisplaySleep(void); | Sätter displayen i sömnläge, eller väcker displayen.
u8g_t u8g | Struct för biblioteket Universal 8bit Graphics Library, för display.

### 1.9.7 Main-funktionen

I detta kapitel beskrivs grundläggande vad som händer i programmets kod

Interrupt-funktionen aktiveras för MCU-enheten, detta behövs för att MPU-enheten ska fungera korrekt. Sedan initieras MPU-9250-enheten, med funktion från mpu6050.h

Displayen initieras och teckensnitt bestäms, funktioner från u8g.h

Texten ”STEPCOUNTER” visas på displayens mitt i en sekund.

Idle-värde för accelerometern sätts.

Programmets huvud-loop startar.

Ett kombinerat accelerationsvärde för X- Y- och Z-riktningar hämtas

Om skillnaden mellan det hämtade värdet och idle-värdet överskrider tröskelvärdet för att trigga ett steg, skriv ut antalet steg till displayen. Om displayen är i sömnläge, väck den.

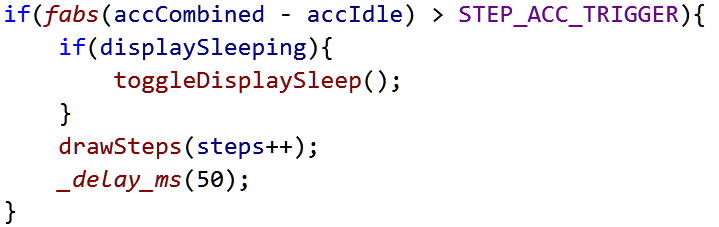
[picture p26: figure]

Sätt display i sömnläge om timer har nått värde

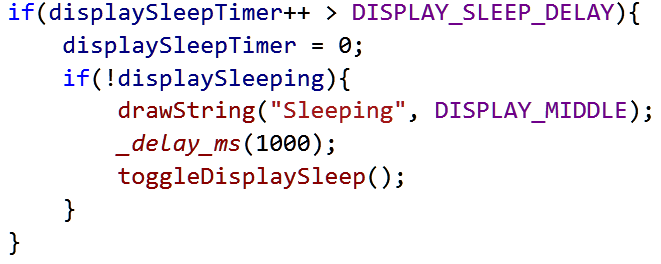
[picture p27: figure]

Slut på huvud-loop.

# 2 Diskussion och slutsats

I denna del utförs diskussioner och tankegångar angående projektets genomförande och resultat

CAD / 3D-utskrift av hölje
Initialt planerades att konstruera ett eget hölje med hjälp av en 3D-skrivare. Vilket hade gett en anpassad form för stegräknaren. På grund av tidsbrist valdes en redan befintlig produkt att användas som hölje.

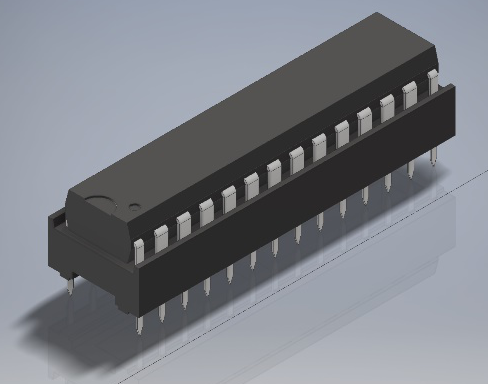
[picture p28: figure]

Figur 15 Rendering av CAD-modell för MCU och sockel

Byte av batterityp
Batteriet av typ 18650 tar upp en mycket stor del av stegräknarens volym. Ett eventuellt byte till ett volymmässigt mindre batteri, exempelvis av typen CR2032, skulle reducera båda volym och vikt. Det är dock oklart om detta batteri kan användas för drivning av produkten.

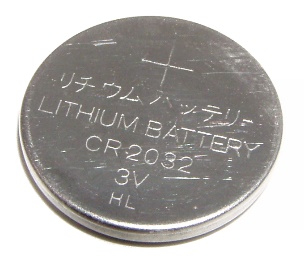
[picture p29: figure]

Figur 16 Batteri av typen CR2032

Fler I²C-moduler
Stegräknaren har stöd för inkoppling av en tredje enhet. I projektets gång gjordes tester med WiFi-moduler av typen ESP8266, för att kunna kommunicera med stegräknaren trådlöst. Dock lyckades testerna och WiFi-stöd valdes att läggas ned.

En annan möjlig enhet skulle kunna vara en blåtand-modul.

Användning av färdigskrivna kodbibliotek
Flertalet redan färdiga bibliotek användes för att kommunicera med enheter som är kopplade till MCU-n. En framtida övning skulle kunna vara att försöka skriva egna funktioner för I²C-kommunikation.

Bättre detektion av steg
Stegräknaren anses i nuläget ej vara speciellt ackurat. Vid promenad detekteras oftast enbart steg på det ben där stegräknaren är placerad i byxfickan. Vid löpning, då större kraft utsöndras vid fotnedslag, detekteras båda benens steg.

Koden skulle kunna förbättras för att göra stegräknaren bättre.

Hastighet- och distans-mätning
Om stegräknaren hade tillgång till steglängden på den person som använder enheten, skull sträcka kunna mätas.

Även hastighet skulle kunna mätas, om stegräknaren hade tillgång till tid, t.ex. med en RTC-modul.

# 3 Bilagor

## 3.1 Kopplingsschema för prototyp 1

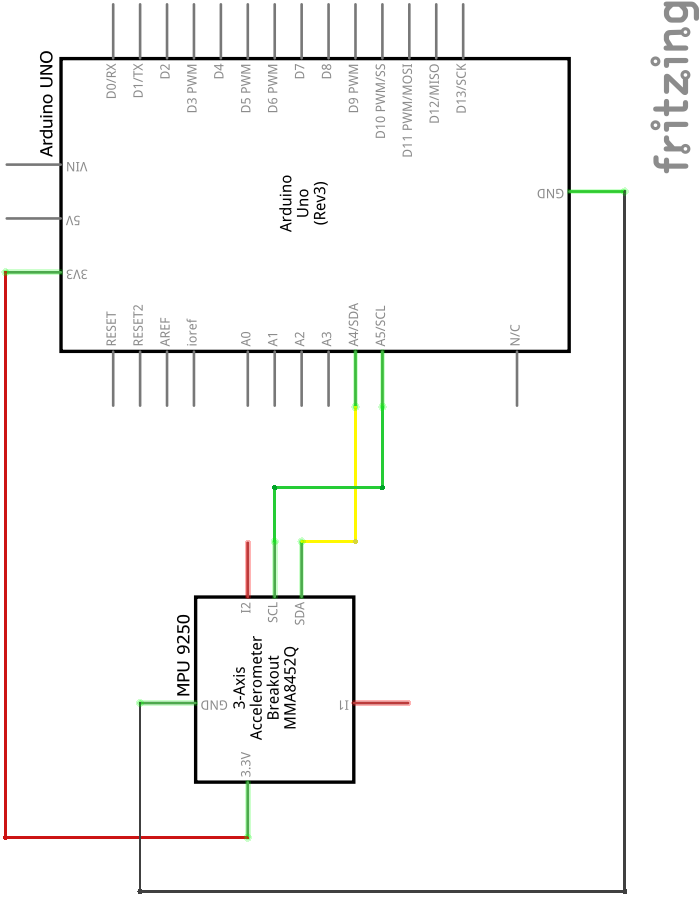
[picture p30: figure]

## 3.2 Kopplingsschema för prototyp 2

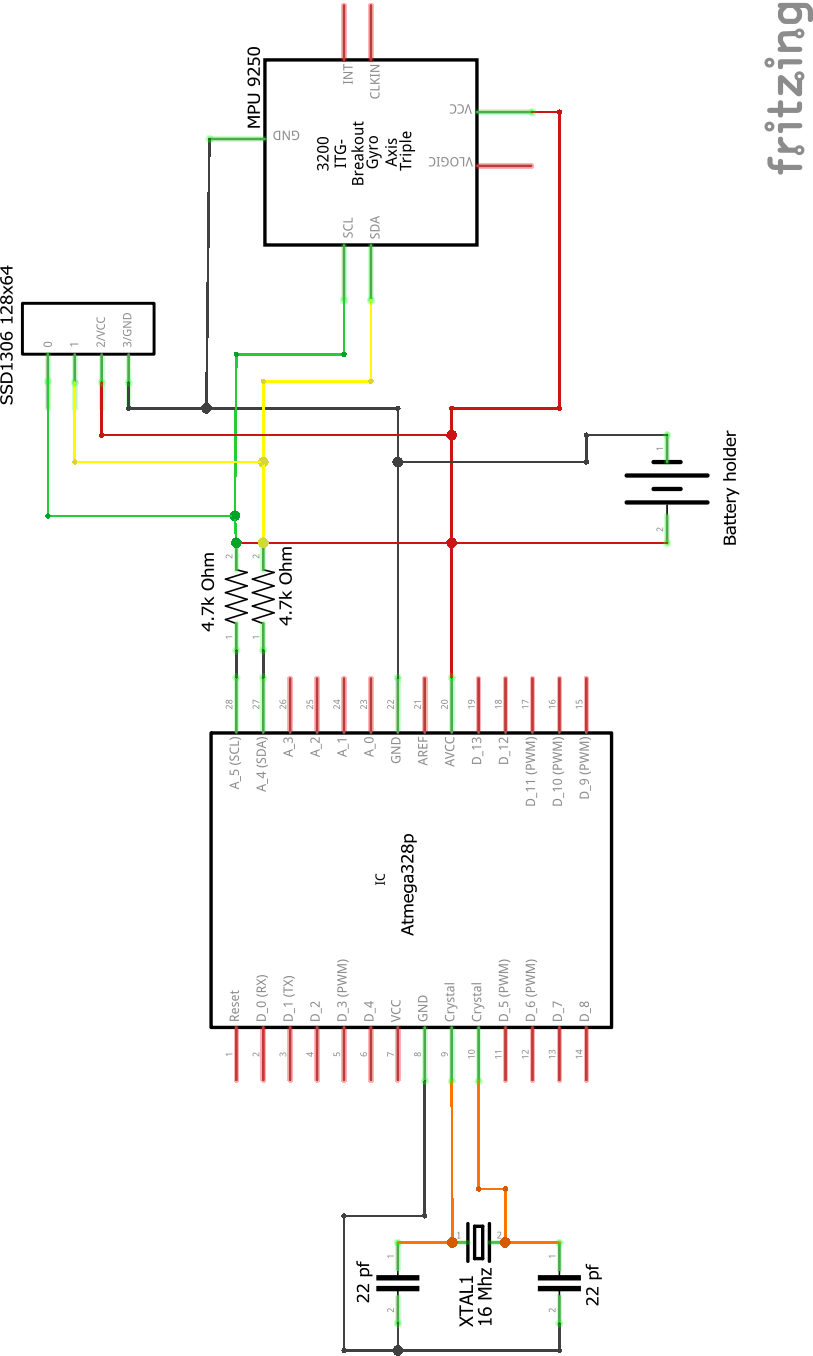
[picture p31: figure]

[^1] Se länk i kapitel 1.4.4
[^2] Se länk i kapitel 1.4.4
[^3] För länk, se kapitel 1.4.1

StegräknareProgrammering av inbyggda system 2017-04-19

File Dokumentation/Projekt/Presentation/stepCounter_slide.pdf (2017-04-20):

# Stegräknare

## Dennis - Simon - Johan

## Komponentlista

Atmel ATMega328p

SparkFun MPU-9250 (accelerometer)

OLED Display SSD1306 128x64

AVR pocket programmer

DIL-hållare 28-pin

Resistor 4,7kΩ, 2 st

Kristalloscillator 16 MHz

Kondensator 22pF, 2 st

Litiumbatteri 18650

Batterihållare för litiumbatteri 18650

Grovekontakter 4-stift

## Prototyp #1 - Arduino & MPU-9250

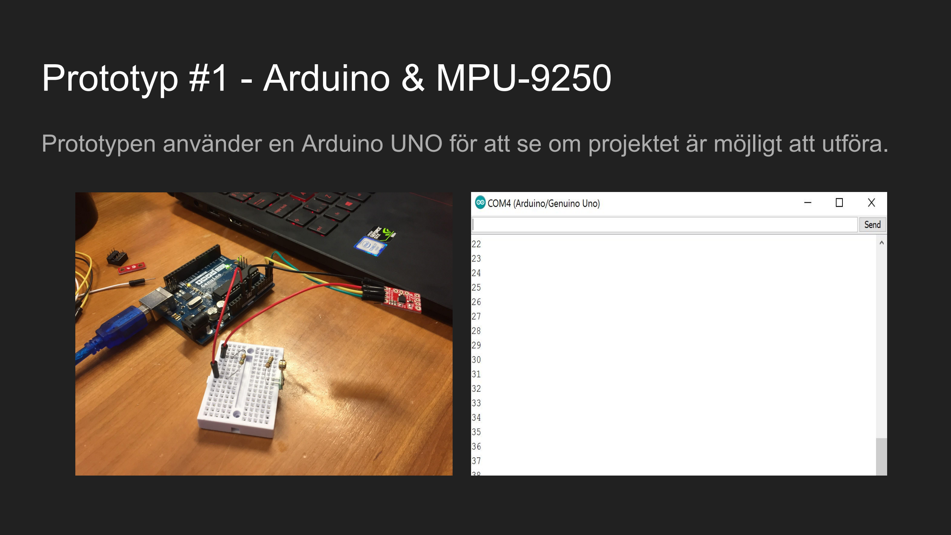
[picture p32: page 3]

Prototypen använder en Arduino UNO för att se om projektet är möjligt att utföra.

## Prototyp #2 - AVR / Display / MPU-9250

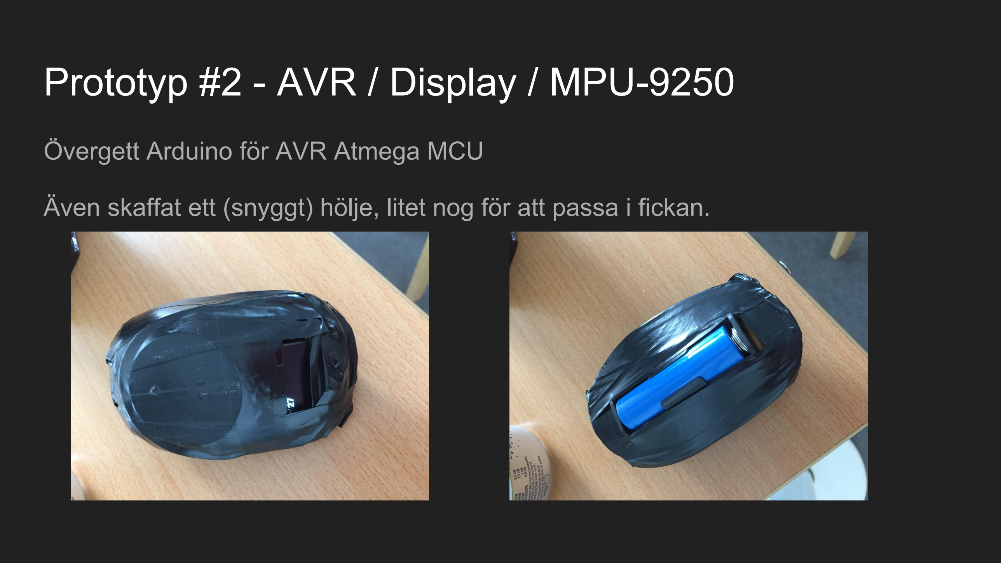
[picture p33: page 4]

Övergett Arduino för AVR Atmega MCU

Även skaffat ett (snyggt) hölje, litet nog för att passa i fickan.

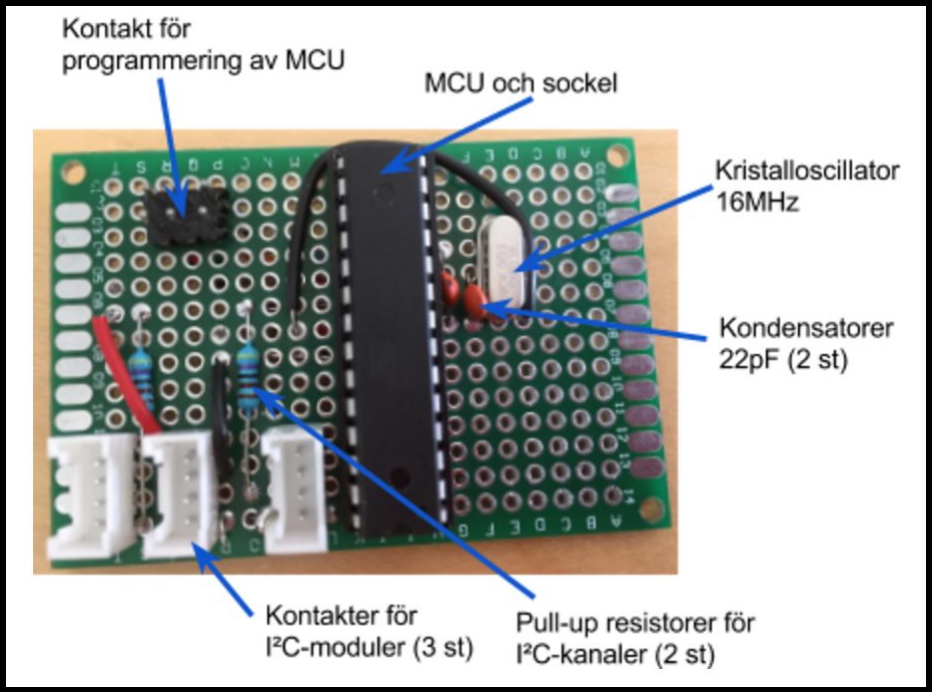
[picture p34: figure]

## Bygge Prototyp 2

## Moduler - 3x I²C

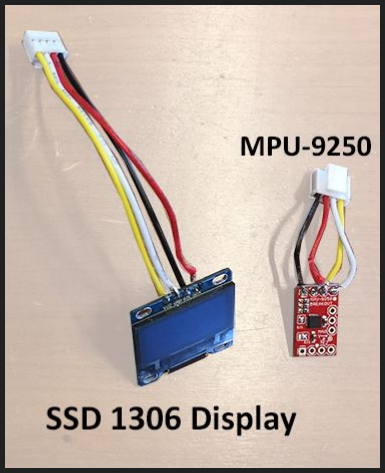
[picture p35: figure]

1: SparkFun MPU-9250, Accelerometer, viktigaste modulen.

2: OLED Display 128x64, Indikator och visning av antal tagna steg

3: Ledig

I²C: Sätt att koppla enheter till varandra via två ledare.

## Slutprodukt

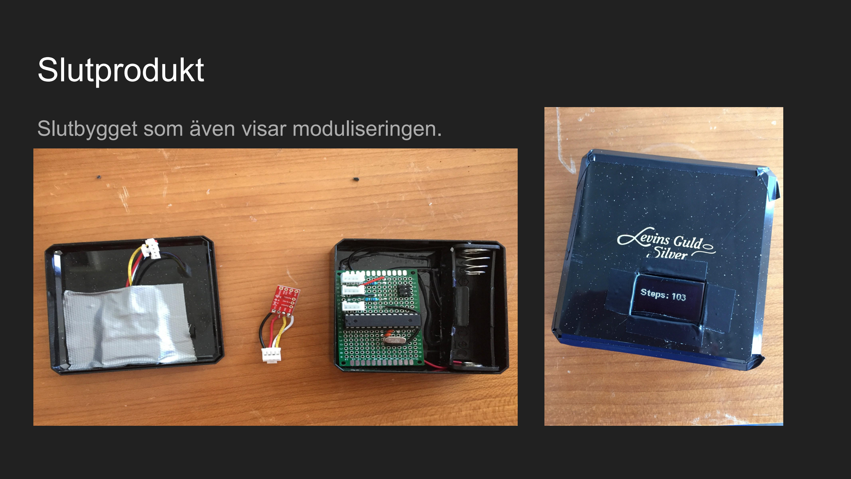
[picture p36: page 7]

Slutbygget som även visar moduliseringen.

## Kodsnuttar

Hämta accel-data från MPU-9250. | Main-loopen för stegräknaren.

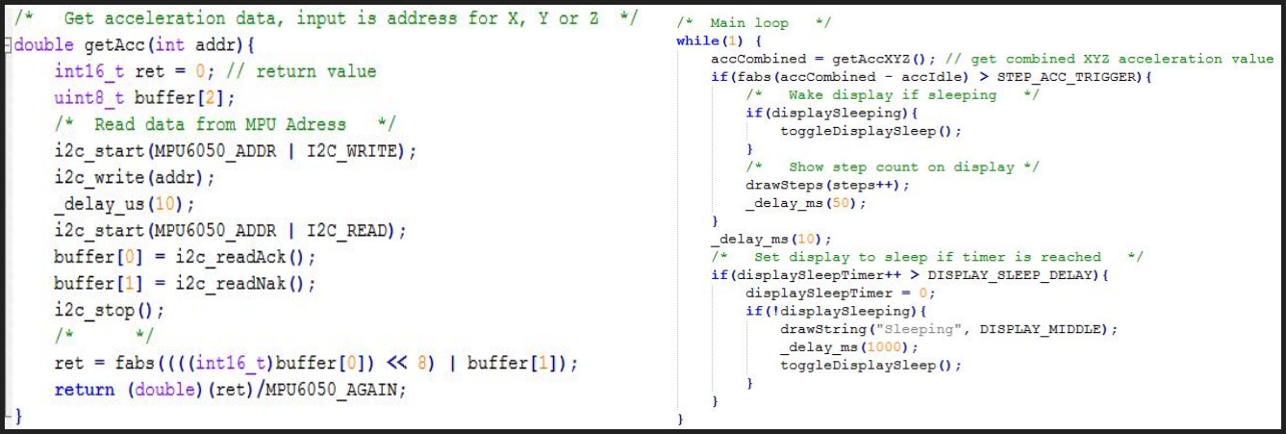
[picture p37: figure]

## Vad har vi lärt oss?

- Fått en större inblick i hur AVR-programmering fungerar.
- Koppling av externa enheter till AVR.
- Git/Github/GitKraken.
- Jobba under tidspress, samt planering och utförande av projekt.

## Problem och svårigheter

- Steget från Arduino till AVR
- Debugging utan display / serial monitor
- Få fungerande display
- Hitta fungerande kodbibliotek
- ESP (WiFi) - skrotades
- I

2C
- Byggnation av hölje för produkten
- Minimering av storlek

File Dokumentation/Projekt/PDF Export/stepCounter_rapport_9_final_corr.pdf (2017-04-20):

# Stegräknare

## Projekt: Pedometer med AVR

Kurs

## Programmering av inbyggda system

2017-04-19

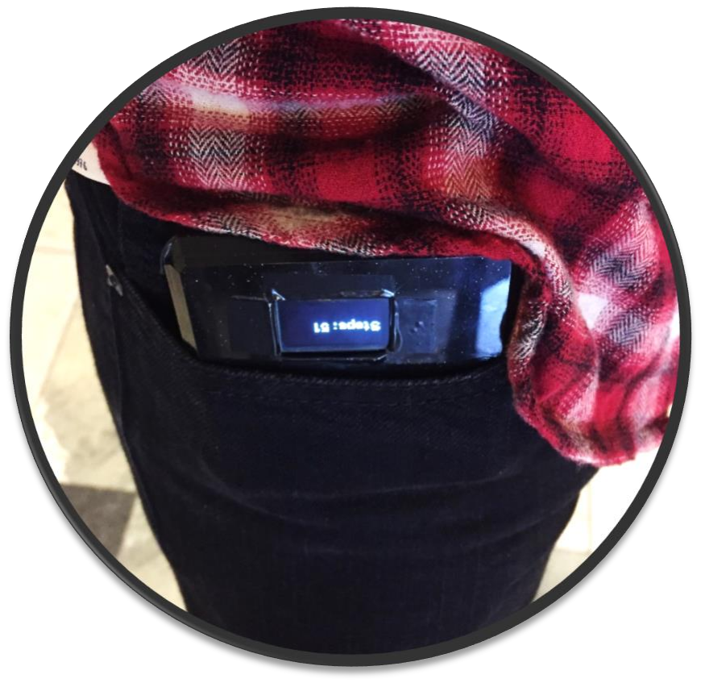
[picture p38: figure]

# Dennis Bunne

## LinkedIn (https://www.linkedin.com/in/dennis-bunne-259a9783/)

# Johan Kämpe

## LinkedIn (https://www.linkedin.com/in/johankampe/)

# Simon Karlsson

## LinkedIn (https://www.linkedin.com/in/simon-karlsson-54509aa9/)

## Mjukvaruutvecklare Inbyggda System

MÖLK Utbildning AB (http://dev.molk.com/)

Stegräknare | Programmering av inbyggda system | 2017-04-19

## Innehållsförteckning

## Figurförteckning

## 1 Inledning

### 1.1 Syfte

Syftet med projektet är att tillverka en bärbar, batteridriven stegräknare. Stegräknaren ska ha modulära enheter, det vill säga att de går att ta bort eller byta ut. En modulär enhet kan vara en display, blåtandsmodul eller accelerometer.

En display används för att visa antal tagna steg. Stegen ska avläsas med hjälp av en accelerometer, eller alternativt med en vibrationssensor.

### 1.2 Noteringar och information

Projektet utfördes på under perioden mars till april, 2017.

I rapporten hänvisas själva stegräknaren ofta till som projektet eller produkten.

I rapporten hänvisas MPU-9250-enheten, som används för att mäta acceleration, ofta som MPU-enheten, eller MPU-n.

### 1.3 Bakgrund

1.3.1 Definitioner av begrepp och förkortningar
Term | Förklaring
Acceleration | Förändring av hastighet per tidsenhet. Kan vara positiv (hastighetsökning) eller negativ (minskad hastighet).
Arduino UNO | Utvecklingskort.
Atmega328p | En mikrokontroller (MCU) med 28 anslutningar, från tillverkaren Atmel
AVR | Familj av mikrokontrollers som tillverkas av företaget Atmel.
Bibliotek | En samling av kod-funktioner och/eller definitioner.
Breadboard | Kopplingsplatta, används för att ansluta enheter till varandra.
C Det programmeringsspråk som används i projektet.
DIL | Dual in-line. Standard för mikrochip med två rader av ben.
Git | Ett versionshanteringssystem.
GitHub | Molnlagring för Git-projekt.
I²C | Ett sätt att koppla samman enheter, via två ledare: SCL och SDA.
IDE | Integrated Development Environment. Ett datorprogram eller en programsvit som vanligtvis innehåller en texteditor, kompilator och debugger. För att underlätta vid programmering.
Interrupt | En del i en mikroprocessors funktionalitet. Ett sätt att få processorn att avbryta sitt nuvarande arbeta och övergå till en annan uppgift.
ISP | In-system programming, programmering av redan installerade eller inbyggda system.
LED | Light Emitting Diode, lysdiod.
Lib | Se Bibliotek.
Library | Se Bibliotek.
Macro | En definierad konstant i programkod.
MCU | Microcontroller Unit, se Mikrokontroller.
Mikrokontroller | En liten enchippsdator med CPU, arbetsminne och programminne.
Mikroprocessor | Processor i ett chip
MPU | Microprocessor Unit, Se mikroprocessor
MPU-6050 | Mikroprocessor med sensor för gyro och acceleration i tre riktningar vardera.
MPU-9250 | Mikroprocessor med sensor för gyro, acceleration och kompass i tre riktningar vardera.
Pull up-resistor | Används i logiska kretsar för att se till att en ingång håller sig hög när den inte har någon anslutning.
Resistans | Värdet på ett motstånd / resistor. Anges i Ohm (Ω).
Resistor | Motstånd i elektriska kretsar.
SCL | Serial Clock Line, se I²C.
SDA | Serial Data Line, se I²C.
Serial Monitor | Funktion i Arduinos IDE, för att kommunicera med inkopplad Arduino-enhet. Används ofta för debugging.
Standardbibliotek | Kodbibliotek som alltid är tillgängliga för ett specifikt programspråk. Exempelvis stdio.h för programspråket C.
Stegräknare | En enhet som mäter hur många steg en människa tar
TWI | Two Wire Interface, se I²C.
Utvecklingsmiljö | Se IDE.

1.3.2 Stegräknare
En stegräknare är en vanligtvis portabel enhet. Som mäter hur många steg en människa tar. Den kan användas vid exempelvis löpning, promenad, eller för att se hur många steg en person tar under en dag.

En stegräknare kan också kallas pedometer.

1.3.3 I²C
I²C, Inter-Integrated Circuit, är ett sätt att koppla enheter till moderkort, inbyggda system, mobiltelefoner eller andra enheter.

Kommunikation sker via två ledare, SDA (Serial Data Line, datasignal) och SCL (Serial Clock, klocksignal). Flera I²C-enheter kan anslutas till samma SDA- och SCL-ledare.

På en mikrokontroller av typen Atmega328p, är anslutningar 27 och 28, SDA och SCL, respektive.

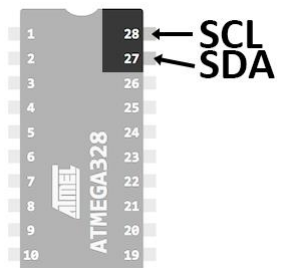
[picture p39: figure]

Figur 1 I

2C-ansluting på Atmega328

I²C kallas även TWI, Two Wire Interface, eller IIC.

1.3.4 Pull up-resistorer
Pull up-resistorer används i logiska kretsar för att se till att en ingång håller sig hög när den inte har någon anslutning.

Utan pull up kan ingången anta vilket läge som helst, hög eller låg. I projektet används pull up-resistorer för I²C-anslutningarna.

Resistorer som används ska vara av hög resistans.

1.3.5 MPU-9250
Enheten som används i projektet för att mäta acceleration kallas MPU-9250 IMU Breakout och är tillverkad av Sparkfun. På enheten finns en MPU-9250.

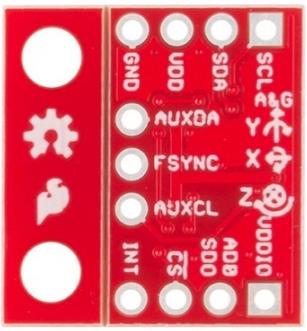
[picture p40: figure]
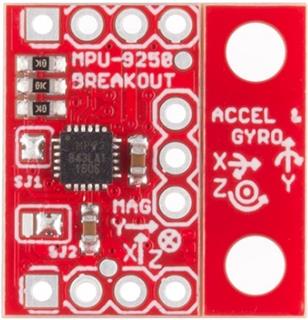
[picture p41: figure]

Figur 2 MPU-9250, framsida | Figur 3 MPU-9250, baksida med anslutningsbeteckningar

De anslutningar som används i projektet är VDD och GND för drivning, samt SDA och SCL för I²Ckommunikation.

Länk till tillverkarens produktsida finns i kapitel 1.4.4

1.3.6 X-Y-Z-riktning
X, Y och Z används inom projektet för att beskriva riktningar i en tredimensionell miljö. MPU-9250-enheten har sensorer för acceleration i dessa tre riktningar.

När enheten förs åt ett visst håll mäts rörelsens acceleration i denna riktning.

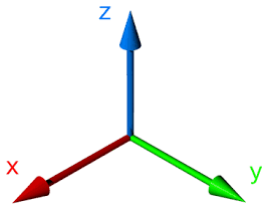
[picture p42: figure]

Figur 4 Riktningar i X- Y och Z-led

### 1.4 Länkar

1.4.1 GitHub
Länkar till projektets GitHub-sida

GitHub-sida för projektet
https://github.com/GoblinDynamiteer/stepCounter

GitHub-sida, huvudkod
https://github.com/GoblinDynamiteer/stepCounter/blob/master/Kod/Huvudkod/stepCounter/mpu_conntest/main.c (https://github.com/GoblinDynamiteer/stepCounter/blob/master/Kod/Huvudkod/stepCounter/mpu_conntest/main.c)

GitHub-sida, kod för prototyp 1 https://github.com/GoblinDynamiteer/stepCounter/blob/master/Kod/Testkod/Arduino/stepCounterPrototype/stepCounterPrototype.ino (https://github.com/GoblinDynamiteer/stepCounter/blob/master/Kod/Testkod/Arduino/stepCounterPrototype/stepCounterPrototype.ino)

1.4.2 Använda funktionsbibliotek
Länkar till bibliotek som har använts i projektets kod

MPU 6050 library
http://davidegironi.blogspot.se/2013/02/avr-atmega-mpu6050-gyroscope-and.html#.WOtTeojyhPY

U8glib
https://github.com/olikraus/u8glib

I2C master library
http://homepage.hispeed.ch/peterfleury/avr-software.html#libs

1.4.3 Datablad
Atmega328p
https://github.com/GoblinDynamiteer/stepCounter/blob/master/Dokumentation/Komponenter/Atmega%20328p/ATmega328P_datasheet_Complete.pdf (https://github.com/GoblinDynamiteer/stepCounter/blob/master/Dokumentation/Komponenter/Atmega%20328p/ATmega328P_datasheet_Complete.pdf)

MPU-9250
https://github.com/GoblinDynamiteer/stepCounter/blob/master/Dokumentation/Komponenter/MPU%209250/MPU-9250-Datasheet.pdf (https://github.com/GoblinDynamiteer/stepCounter/blob/master/Dokumentation/Komponenter/MPU%209250/MPU-9250-Datasheet.pdf)

SSD1306 Display
https://github.com/GoblinDynamiteer/stepCounter/blob/master/Dokumentation/Komponenter/Micro%20OLED%20Breakout%20Display%20SSD1306/SSD1306_datasheet.pdf (https://github.com/GoblinDynamiteer/stepCounter/blob/master/Dokumentation/Komponenter/Micro%20OLED%20Breakout%20Display%20SSD1306/SSD1306_datasheet.pdf)

1.4.4 Andra länkar
MPU-6050 Accelerometer + Gyro Kodexempel
http://playground.arduino.cc/Main/MPU-6050

SparkFun IMU Breakout - MPU-9250 Produktbeskrivning
https://www.sparkfun.com/products/13762

## 2 Genomförande och resultat

### 2.1 Använd programvara

Programnamn | Beskrivning
Atmel Studio 7.0 | IDE för att skriva kod och kompilera till Atmel MCU.
Atom | Texteditor, för att skriva och analysera kod.
Git | Versionshanteringsverktyg.
GitKraken | Grafiskt gränssnitt (GUI) för Git.
Fritzing | Program för att skapa kretsscheman.
Microsoft Word | Dokumentering och rapportskrivning.
Google Docs | Rapportskrivning.
AVRDUDE, AVR Downloader/UploaDEr | Program för att ladda upp kompilerad kod till MCU.
AVRDUDESS | Grafiskt gränssnitt (GUI) för AVRDUDE.
Autodesk Fusion 360 | CAD-program för att konstruera ett hölje till stegräknaren.

### 2.2 Använd hårdvara

Komponent | Beskrivning
Atmel ATMega328-PU DIP-28N 8-bit MCU | Mikrokontroller.
SparkFun MPU-9250 | Enhet som mäter acceleration i X, Y och Z-riktning. Innehåller även gyroskop, temperatur och kompass-funktionalitet.
Micro OLED Display SSD1306 128x64 | Display med upplösning 128x64 pixlar.
AVR pocket programmer | Enhet för att programmera Atmega-MCU-n via en dators USB-port.
DIL-hållare 28-pin 0.3" | Sockel för Atmega-MCU.
Resistor 4,7kΩ, 2 st. | Pull up-resistorer för I²C-kanaler.
Kristalloscillator 16 MHz | Kopplas till MCU för att öka klockfrekvensen från 1 MHz till 16 MHz.
Kondensator 22pF, 2 st. | Används för inkoppling av kristalloscillator.
Litiumbatteri 18650 | Strömförsörjning.
Hållare för litiumbatteri 18650
Grovekontakter med 4-stift | För modularisering av I²C-komponenter.
Kopplingsplatta 60x40 mm | För sammanlödning av komponenter.
Arduino UNO | För prototyping.

### 2.3 Metod

2.3.1 Skrivning av källkod, kompilering och uppladdning till mikrokontroller
Programmets källkod skrevs i utvecklingsmiljön Atmel Studio, som ett GCC C Executable Projectprojekt. Källkoden är skriven i programspråket C.

All egenskriven kod finns i projektets källkodsfil main.c.

Vid kompilering av koden skapas en fil med filändelsen hex i Atmel Studio-projektets Debugunderkatalog. Denna fil laddas upp till mikrokontrollern med datorprogrammet AVRDUDE och programmeringsenheten AVR pocket programmer.

Programmering utförs via ISP, följande anslutningar på mikrokontrollerns används.

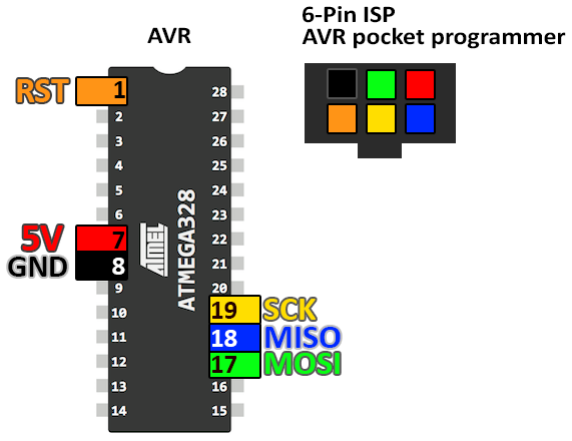
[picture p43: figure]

Figur 5 Inkoppling av programmeraren till mikrokontrollern

Programmeringsenheten kan även användas som strömkälla.

2.3.2 Studie av datablad
Tidigt i projektet samlades datablad in för införskaffad hårdvara. Databladen studerades och relevant information noterades för att kunna användas vid framtagning av prototyp.

I synnerlighet studerades datablad för:

- MPU-9250
- Atmega328p
- OLED Display

2.3.3 Studie av funktionsbibliotek
Tidigt i projektet hämtades färdiga kodbibliotek från Internet, för projektets hårdvara. Koden i dessa bibliotek studerades, eller användes för att undersöka funktionen hos olika komponenter.

Exempel på bibliotek som studerades eller användes i projektets utveckling:

Bibliotek | Beskrivning och syfte
Wire.h | I 2C-bibliotek för Arduino-enheter. För att funktionstesta I²C-enheter med Arduino UNO. Användes även i koden för prototyp 1.
twitest.c | I 2C-test/demo för AVR-enheter.
mpu6050.h | MPU-6050 (Accelerometer, mm.) för AVR-enheter.
i2cmaster.h | I 2C-bibliotek för AVR-enheter.
ssd1306.c | Kod som använt sig av i2cmaster.h för att skriva ut text till display.

Koden studerades med bland annat texteditorn Atom och i utvecklingsmiljön Atmel Studio.

I Atmel Studio finns möjligheten att automatiskt gå till den fil där ett makro, en funktion eller en variabel är definierad. I bilden nedan utförs detta på funktionen fabs();

Figur 6 Gå till en implementation av ett makro, variabel eller funktion.

### 2.4 Prototyp 1

Projektets första prototyp, kallad prototyp 1, byggdes för att säkerställa att en stegräknare kunde konstrueras med en MPU-9250 som accelerometer. MPU-enheten kopplades direkt till en Arduino UNO-enhet via en breadboard.

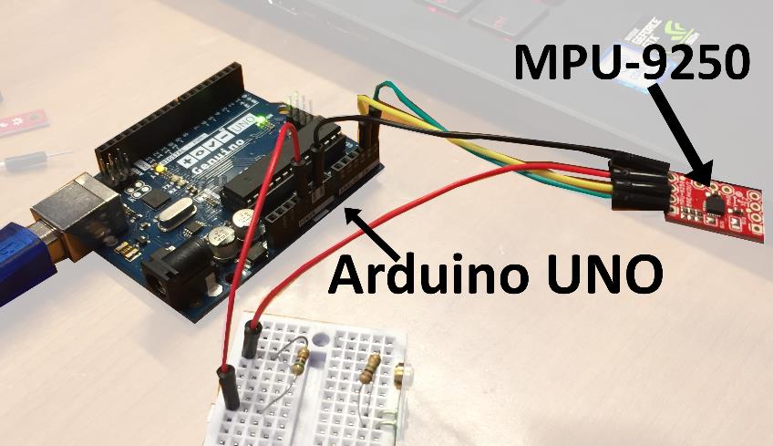
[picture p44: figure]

Figur 7 Uppkoppling av MPU-9250 till Arduino UNO

Koden för prototyp 1 baserades på kod skapad av JohnChi ¹
, som skriver ut värden från MPU-6050-enheter till Arduino-utvecklingsmiljöns Serial Monitor. Koden skrevs om så att endast värden för acceleration hämtades, dessa användes för stegräkning.

Funktionsbiblioteket wire.h används för att ansluta MPU-n via I²C till Arduino-enheten. Portarna A4 och A5 används för SDA och SCL, respektive. En resistor med värdet 560 Ohm användes för att ta ner spänningsmatningen till MPU-n från 5V till ca 3V.
Enligt tillverkarens hemsida²
ska enheten drivas med 2.4V – 3.6V.

En bärbar dator användes för strömförsörjning och för att avläsa Serial Monitor. Avläsning av steg gjordes genom att placera prototypen i en byxficka och promenera runt.


Figur 8 Utskrift av stegräkning till Serial Monitor

En vibrationssensor testades också för att avläsa steg. Även om den kunde användas för avläsning, valdes den att inte användas, då MPU-enheten ansågs vara mer pålitlig.

Prototyp 1 färdigställdes 2017-03-21

Kopplingsschema för prototyp 1 kan ses i rapportens bilagor.

1
Se länk i kapitel 1.4.4
2
Se länk i kapitel 1.4.4

### 2.5 Prototyp 2

Vid byggnation av prototyp 2 användes en Atmega328p MCU.

En breadboard användes för samtliga inkopplingar innan sammanlödning av enheter påbörjades.

Initialt anslöts MPU-9250-enheten till mikrokontrollerns I

2C-anslutningar, med pull up-resistorer på båda kanaler. För att kunna indikera att MPU-n fungerade korrekt användes en blå LED. Lysdioden sattes att lysa när accelerationsdata från MPU-n översteg ett visst värde.

När displayen anslöts och kunde användas för att visa diverse data från MCU-n, blev lysdioden överflödig och användes inte längre.

En kristalloscillator på 16 MHz kopplades MCU-enhetens anslutningar 9 och 10. Dessa anslutningar används för inkoppling av externa kristalloscillatorer. Kristalloscillatorn användes för att öka klockfrekvensen på MCU-n. Enheten upplevdes också som stabilare.

När uppkopplingen på breadboard ansågs vara fungerande, löddes MCU-n fast via en sockel på en kopplingsplatta. Tre stycken kontakter löddes till MCU-ns I²C-kanaler. Dessa kontakter går att använda för att koppla in olika enheter med I²C-stöd.

På displayen och MPU-enheten löddes kontakter fast, för anslutning till kontakterna på kopplingsplattan.

På kopplingsplattan löddes även övriga komponenter fast: kristalloscillator, resistorer och kondensatorer.

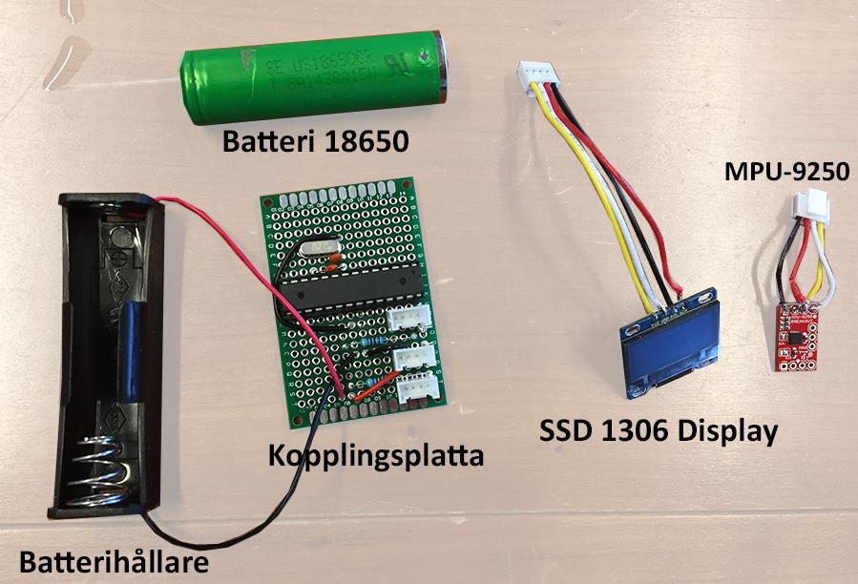
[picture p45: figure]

Figur 9 Lödda och urkopplade modulära komponenter

En kasserad optisk mus användes som hölje för prototyp 2. Eltejp och smältlim användes för sammanfogning.

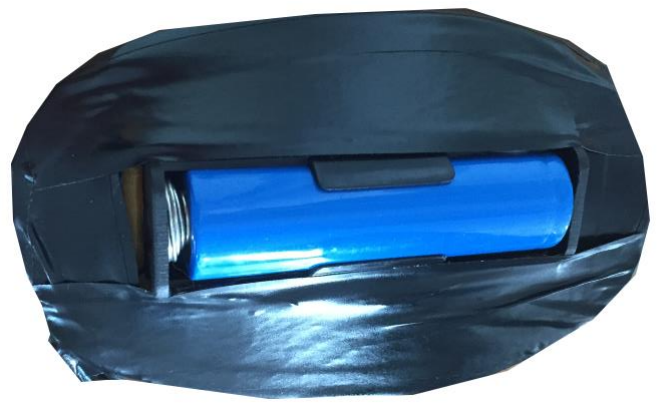
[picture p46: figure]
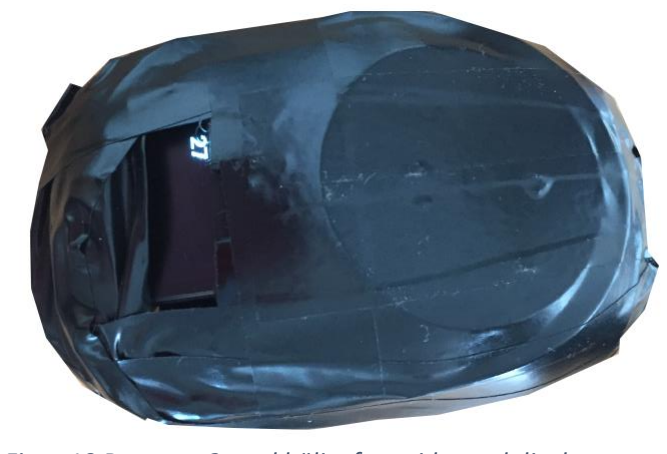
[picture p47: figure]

Figur 10 Prototyp 2 med hölje, framsida med display | Figur 11 Prototyp 2 med hölje, baksida med batteri

Efter sammanställning av prototyp 2, plockades delarna ut ur höljet, och en ytterligare anslutning löddes på kopplingsplattan, för programmering av mikroprocessorn via AVR pocket programmer.

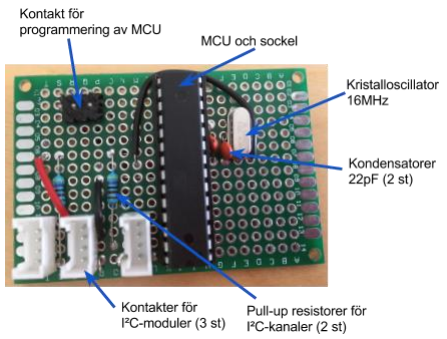
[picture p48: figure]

Figur 12 Placering av fastlödda komponenter på kopplingsplatta

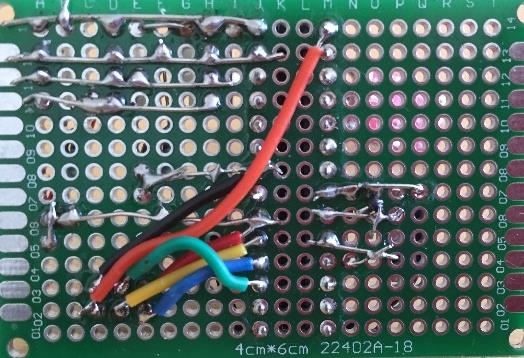
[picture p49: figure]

Figur 13 Komponenter lödda på kopplingsplatta, baksida

Prototyp 2 används som bas för den färdigställda produkten.

Kopplingsschema för prototyp 2 kan ses i rapportens bilagor.

### 2.6 Slutgiltig produkt

Elektronikmässigt är den färdiga produkten lik prototyp 2.

Skillnader är att koden har uppdaterats och utvecklats, och att dess hölje har bytts ut.

Höljet till den slutgiltiga produkten är byggt av en förvaringsbox för smycken. Ett uttag har gjorts i boxens lock, för inplacering av displayen. Displayen är fäst med tejp i locket, och övriga komponenter är fastsatta med smältlim i boxen.

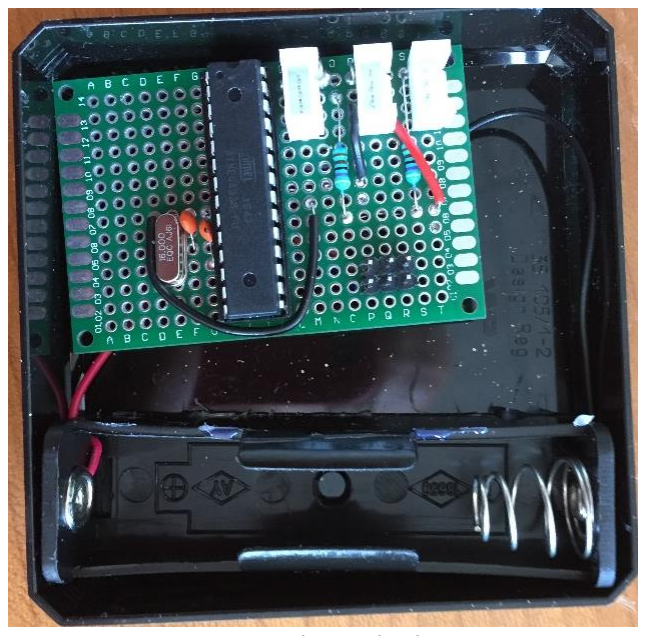
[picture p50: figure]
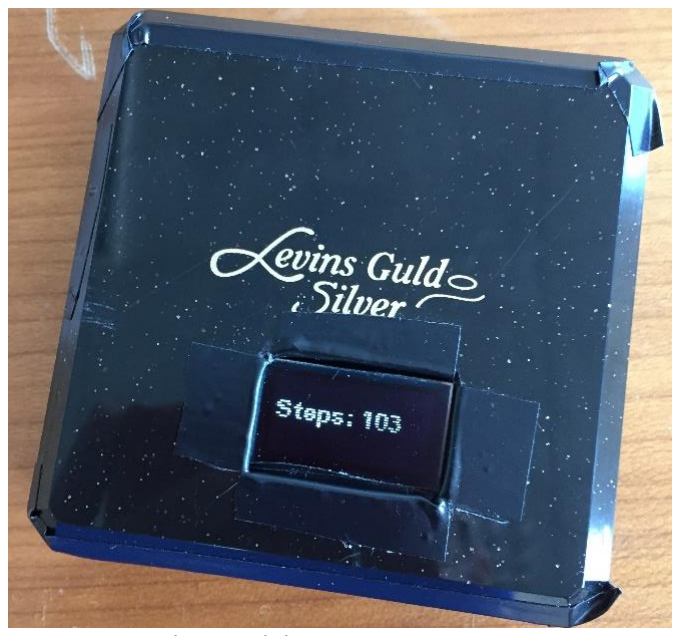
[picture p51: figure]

Figur 14 Komponenter inplacerade i box | Figur 15 Komplett produkt

Produkten färdigställdes 2017-04-19

### 2.7 Stegräknarens funktion

Vid stegräknarens start kalibreras den genom att hämta 20 stycken värden för acceleration från MPU-9250-enheten. Stegräknaren bör ligga stilla under kalibreringen. Medelvärdet av de 20 värdena sätts till att vara stegräknarens värde för när den är passiv. Detta värde benämns som idle-värde.

Meddelandet "Calibrating.." visas på stegräknarens display under kalibreringen. När kalibreringen är färdig visas meddelandet "Idle.." på displayen, och stegräknaren kan börja användas.

Under användning hämtas accelerationsdata kontinuerligt från MPU-9250-enheten. Skillnaden mellan detta värde och idle-värdet beräknas som ett absolutvärde. Om skillnaden mellan dessa två värden överskrider ett visst satt tröskelvärde, så anses det att ett steg har tagits.

Vid varje taget steg uppdateras stegräknarens display med det totala antalet tagna steg.

Stegräknarens display sätts automatiskt i sömnläge om inget steg har tagits på ca 30 sekunder. Displayen vaknar automatiskt när ett steg tas.

### 2.8 Projektets kod

Utförligare kommentering av koden finns i källkodsfilen main.c.

3

2.8.1 Egeninkluderade standardbibliotek
Bibliotek | Beskrivning
<avr/io.h> | Diverse I/O definitioner för mikrokontrollern.
<util/delay.h> | För funktionen _delay_ms() som pauserar programmet i angivet antal millisekunder.
<avr/interrupt.h> | Används för funktionen sei(), som aktiverar interrupt på mikrokontrollern. Behövs för kommunikation med MPU-9250.
<math.h> | Diverse matematikfunktioner och macron. Används för funktionen fabs(), som ger absolutvärdet av ett tal.
<stdio.h> | För funktionen sprintf(), som skriver en formaterad textsträng till en char-array. Används för att skriva ut stegräkning till display.

2.8.2 Inkluderade icke-standardbibliotek
Flera av dessa bibliotek har egna inkluderingar av olika standardbibliotek.
Bibliotek | Beskrivning
"i2chw/i2cmaster.h" I2C master library using hardware TWI interface Skapat av Peter Fleury | I 2C-funktionalitet för AVR-enheter. För kommunikation mellan mikrokontroller och enheter anslutna till dess I 2C-portar SDA/SCL.
"mpu6050/mpu6050.h" MPU6050 lib 0x02 Skapat av Davide Gironi | 2C. Viss egen För accelerometer-enheten, via I kod har skrivits genom att bryta ut kod från detta bibliotek.
"u8g/u8g.h" Universal 8bit Graphics Library Skapat av olikraus | Funktionsbibliotek till AVR för diverse displayer.

3
För länk, se kapitel 1.4.1

2.8.3 Macron definierade i main.c
Macron som är definierade i main.c
Namn | Värde | Beskrivning
X | 0x3B | Address för accelerometerdata i X-riktning i MPU-9250
Y | 0x3D | Address för accelerometerdata i Y-riktning i MPU-9250
Z | 0x3F | Address för accelerometerdata i Z-riktning i MPU-9250
STEP_ACC_TRIGGER | 2.3 | Tröskelvärde för acceleration, att bestämma om ett steg har tagits.
SET_IDLE_LOOP | 20 | Antal värden som ska hämtas från accelerometern för att bestämma “idle”-värde. Det värde som accelerometern ger när den anses ligga stilla.
DISPLAY_LINE_HEIGHT | 16 | Pixelhöjd för en rad på displayen. Används vid utskrift av text.
DISPLAY_MIDDLE | (DISPLAY_LINE_HEIGHT * 2 + 2) | Ungefärligt pixelvärde för utskrift på displayens mitt.
DISPLAY_SLEEP_DELAY | 3000 | När värdet i variabeln displaySleepTimer når detta värde sätts displayen i sömnläge.

Macrot F_CPU behövs vara angivet för standardbiblioteket delay.h, detta sätts i kodprojektets egenskaper till F_CPU=16000000, i programmet Atmel Studio.

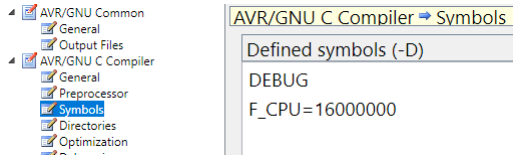
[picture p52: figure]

Figur 16 Kodprojektets egenskaper – Defined symbols

2.8.4 Macron från andra bibliotek
Macron som används i main.c, vilka är definierade i andra bibliotek.
Namn | Värde | Från bibliotek | Beskrivning
MPU6050_ADDR | (0x68 <<1) | mpu6050.h | I²C-address för MPU-9250
MPU6050_AGAIN | 16384.0 | mpu6050.h | Värde för att omvandla ”rå” accelerationsdata från MPU-9250 till g-krafter.
I2C_WRITE | 0 | i2cmaster.h | Datariktning för I²C - för att skriva till en enhet.
I2C_READ | 1 | i2cmaster.h | Datariktning för I²C - för att läsa från en enhet

2.8.5 Variabler
Variabler i källkoden, sätts i main.c
Namn | Beskrivning
uint16_t steps | Håller stegräkning.
double accIdle | Värde som sätts vid programmets uppstart, håller det värde som accelerometern ger när den ligger stilla.
double accCombined | Sammansatt accelerationsvärde från X- Y- och Z-riktning.
double accX, accY, accZ | Värden för acceleration i X- Y- och Z-riktning.
int displaySleeping | Håller displayens sömnläge, sätts till 1 om displayen är i sömnläge, annars 0.
int displaySleepTimer | Används som timer för displayens sömnläge. Ökar med 1 för varje varv i programmets huvudloop.
u8g_t u8g | Struct för biblioteket Universal 8bit Graphics Library, för display.

2.8.6 Funktioner
Egenskrivna funktioner i källkoden
Namn | Beskrivning
double getAcc(int addr); | Hämtar accelerationsdata från MPU och ger värdet i retur. Som argument tar funktionen adressen till det register som ska läsas. Dessa adresser är definierade som macron X, Y och Z.
void drawSteps(uint16_t steps); | Skriver ut aktuellt antal steg till displayens mitt, som "Steps: x"
void drawString(char * string, int line); | Skriver ut en text till displayen. Texten ges som argument till funktionen, i form av en pekare till en char-sträng. Line är den rad på displayen där texten ska visas.
void setAccIdle(); | Sätter ett värde till den globala variabeln accIdle. Funktionen körs endast en gång vid varje uppstart av programmet.
double getAccXYZ(void); | Använder sig av funktionen getAcc() för att hämta accelerationsdata från X-, Y- och Z-riktningen. Det adderade värdet ges i retur.
void toggleDisplaySleep(void); | Sätter displayen i sömnläge, eller väcker displayen.
u8g_t u8g | Struct för biblioteket Universal 8bit Graphics Library, för display.

2.8.7 Main-funktionen
I detta kapitel beskrivs grundläggande vad som händer i programmets kod

Interrupt-funktionen aktiveras för MCU-enheten, detta behövs för att MPU-enheten ska fungera korrekt. Sedan initieras MPU-9250-enheten, med funktion från mpu6050.h

Displayen initieras och teckensnitt bestäms, funktioner från u8g.h

Texten ”STEPCOUNTER” visas på displayens mitt i en sekund.

Idle-värde för accelerometern sätts.

Programmets huvud-loop startar.

Ett kombinerat accelerationsvärde för X- Y- och Z-riktningar hämtas

Om skillnaden mellan det hämtade värdet och idle-värdet överskrider tröskelvärdet för att trigga ett steg, skriv ut antalet steg till displayen. Om displayen är i sömnläge, väck den.

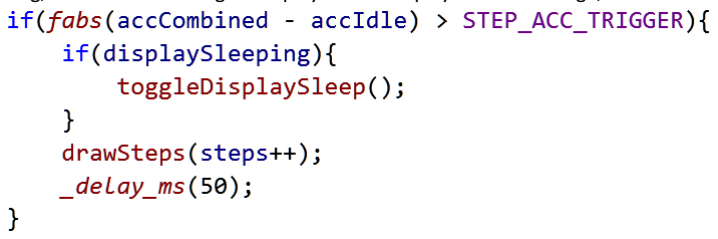
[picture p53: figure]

Sätt display i sömnläge om timer har nått värde

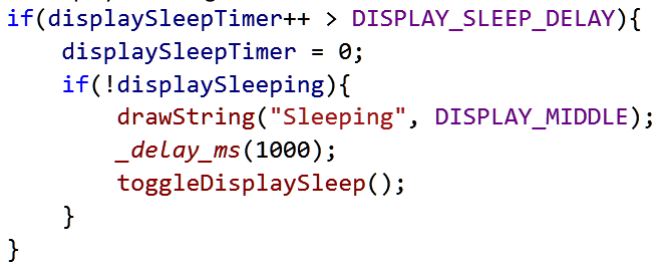
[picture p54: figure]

Slut på huvud-loop.

## 3 Diskussion och slutsats

I denna del utförs diskussioner och tankegångar angående projektets genomförande och resultat

CAD / 3D-utskrift av hölje
Initialt planerades att konstruera ett eget hölje med hjälp av en 3D-skrivare. Vilket hade gett en anpassad form för stegräknaren. På grund av tidsbrist valdes en redan befintlig produkt att användas som hölje.

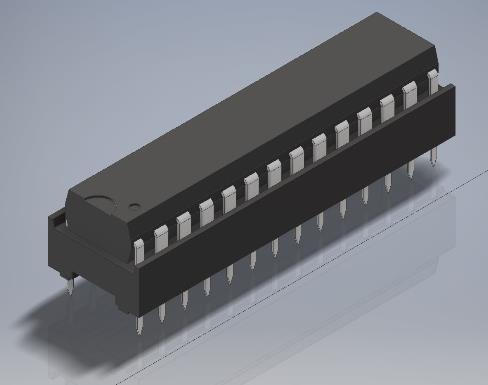
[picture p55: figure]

Figur 17 Rendering av CAD-modell för MCU och sockel

Byte av batterityp
Batteriet av typ 18650 tar upp en mycket stor del av stegräknarens volym. Ett eventuellt byte till ett volymmässigt mindre batteri, exempelvis av typen CR2032, skulle reducera båda volym och vikt. Det är dock oklart om detta batteri kan användas för drivning av produkten.


Figur 18 Batteri av typen CR2032

Fler I²C-moduler
Stegräknaren har stöd för inkoppling av en tredje enhet. I projektets gång gjordes tester med WiFimoduler av typen ESP8266, för att kunna kommunicera med stegräknaren trådlöst. Dock lyckades inte testerna och WiFi-stöd valdes att läggas ned.

En annan möjlig enhet skulle kunna vara en Blåtand-modul.

Användning av färdigskrivna kodbibliotek
Flertalet redan färdiga bibliotek användes för att kommunicera med enheter som är kopplade till MCU-n. En framtida övning skulle kunna vara att försöka skriva egna funktioner för I²Ckommunikation.

Bättre detektion av steg
Stegräknaren anses i nuläget ej vara speciellt ackurat. Vid promenad detekteras oftast enbart steg på det ben där stegräknaren är placerad i byxfickan. Vid löpning, då större kraft utsöndras vid fotnedslag, detekteras båda benens steg.

Koden skulle kunna förbättras för att göra stegräknaren bättre.

Hastighet- och distans-mätning
Om stegräknaren hade tillgång till steglängden hos den person som använder enheten, skull sträcka kunna mätas.

Även hastighet skulle kunna mätas, om stegräknaren hade tillgång till tid, t.ex. med en RTC-modul.

Avstängning
Stegräknaren är inte utrustad med någon strömbrytare, detta innebär att det enda sättet att stänga av eller nollställa enheten är att ta ur batteriet. Detta är ingen bra lösning.

På grund av tidsbrist och risk för att förstöra höljets lock vid uttag för strömbrytare valdes detta att inte implementeras.

## 4 Bilagor

### 4.1 Kopplingsschema för prototyp 1


### 4.2 Kopplingsschema för prototyp 2


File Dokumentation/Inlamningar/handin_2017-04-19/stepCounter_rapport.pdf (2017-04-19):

# Stegräknare

## Projekt: Pedometer med AVR

Kurs

## Programmering av inbyggda system

2017-04-19


# Dennis Bunne

## LinkedIn (https://www.linkedin.com/in/dennis-bunne-259a9783/)

# Johan Kämpe

## LinkedIn (https://www.linkedin.com/in/johankampe/)

# Simon Karlsson

## LinkedIn (https://www.linkedin.com/in/simon-karlsson-54509aa9/)

## Mjukvaruutvecklare Inbyggda System

MÖLK Utbildning AB (http://dev.molk.com/)

Stegräknare | Programmering av inbyggda system | 2017-04-19

## Innehållsförteckning

## Figurförteckning

## 1 Inledning

### 1.1 Syfte

Syftet med projektet är att tillverka en bärbar, batteridriven stegräknare. Stegräknaren ska ha modulära enheter, det vill säga att de går att ta bort eller byta ut. En modulär enhet kan vara en display, blåtandsmodul eller accelerometer.

En display används för att visa antal tagna steg. Stegen ska avläsas med hjälp av en accelerometer, eller alternativt med en vibrationssensor.

### 1.2 Noteringar och information

Projektet utfördes på under perioden mars till april, 2017.

I rapporten hänvisas själva stegräknaren ofta till som projektet eller produkten.

I rapporten hänvisas MPU-9250-enheten, som används för att mäta acceleration, ofta som MPU-enheten, eller MPU-n.

### 1.3 Bakgrund

1.3.1 Definitioner av begrepp och förkortningar
Term | Förklaring
Acceleration | Förändring av hastighet per tidsenhet. Kan vara positiv (hastighetsökning) eller negativ (minskad hastighet).
Arduino UNO | Utvecklingskort.
Atmega328p | En mikrokontroller (MCU) med 28 anslutningar, från tillverkaren Atmel
AVR | Familj av Mikrokontrollers som tillverkas av företaget Atmel.
Bibliotek | En samling av kod-funktioner och/eller definitioner.
Breadboard | Kopplingsplatta, används för att ansluta enheter till varandra.
C Det programmeringsspråk som används i projektet.
DIL | Dual in-line. Standard för mikrochip med två rader av ben.
Git | Ett versionshanteringssystem
GitHub | Molnlagring för Git-projekt
I²C | Ett sätt att koppla samman enheter, via två ledare: SCL och SDA.
IDE | Integrated Development Environment. Ett datorprogram eller en programsvit som vanligtvis innehåller en texteditor, kompilator och debugger. För att underlätta vid programmering.
Interrupt | En del i en mikroprocessors funktionalitet. Ett sätt att få processorn att avbryta sitt nuvarande arbeta och övergå till en annan uppgift.
ISP | In-system programming, programmering av redan installerade eller inbyggda system.
LED | Light Emitting Diode, lysdiod.
Lib | Se Bibliotek.
Library | Se Bibliotek.
Macro | En definierad konstant i programkod.
MCU | Microcontroller Unit, se Mikrokontroller.
Mikrokontroller | En liten enchippsdator med CPU, arbetsminne och programminne.
Mikroprocessor | Processor i ett chip
MPU | Microprocessor Unit, Se mikroprocessor
MPU-6050 | Mikroprocessor med sensor för gyro och acceleration i tre riktningar vardera.
MPU-9250 | Mikroprocessor med sensor för gyro, acceleration och kompass i tre riktningar vardera.
Pull up-reistor | Används i logiska kretsar för att se till att en ingång håller sig hög när den inte har någon anslutning.
Reistans | Värdet på ett motstånd / resistor. Anges i Ohm (Ω).
Resistor | Motstånd i elektriska kretsar.
SCL | Serial Clock Line, se I²C.
SDA | Serial Data Line, se I²C.
Serial Monitor | Funktion i Arduinos IDE, för att kommunicera med inkopplad Arduino-enhet. Används ofta för debugging.
Standardbibliotek | Kodbibliotek som alltid är tillgängliga för ett specifikt programspråk. Exempelvis stdio.h för programspråket C.
Stegräknare | En enhet som mäter hur många steg en människa tar
TWI | Two Wire Interface, se I²C.
Utvecklingsmiljö | Se IDE.

1.3.2 Stegräknare
En stegräknare är en vanligtvis portabel enhet. Som mäter hur många steg en människa tar. Den kan användas vid exempelvis löpning, promenad, eller för att se hur många steg en person tar under en dag.

En stegräknare kan också kallas pedometer.

1.3.3 I²C
I²C, Inter-Integrated Circuit, är ett sätt att koppla enheter till moderkort, inbyggda system, mobiltelefoner eller andra enheter.

Kommunikation sker via två ledare, SDA (Serial Data Line, datasignal) och SCL (Serial Clock, klocksignal). Flera I²C-enheter kan anslutas till samma SDA- och SCL-ledare.

På en mikrokontroller av typen Atmega328p, är anslutningar 27 och 28, SDA och SCL, respektive.


Figur 1 I

2C-ansluting på Atmega328

I²C kallas även TWI, Two Wire Interface, eller IIC.

1.3.4 Pull up-resistorer
Pull up-resistorer används i logiska kretsar för att se till att en ingång håller sig hög när den inte har någon anslutning.

Utan pull up kan ingången anta vilket läge som helst, hög eller låg. I projektet används pull up-resistorer för I²C-anslutningarna.

Resistorer som används ska vara av hög resistans.

1.3.5 MPU-9250
Enheten som används i projektet för att mäta acceleration kallas MPU-9250 IMU Breakout och är tillverkad av Sparkfun. På enheten finns en MPU-9250.


Figur 2 MPU-9250, framsida | Figur 3 MPU-9250, baksida med anslutningsbeteckningar

De anslutningar som används i projektet är VDD och GND för drivning, samt SDA och SCL för I²Ckommunikation.

Länk till tillverkarens produktsida finns i kapitel 1.4.4

1.3.6 X-Y-Z-riktning
X, Y och Z används inom projektet för att beskriva riktningar i en tredimensionell miljö. MPU-9250-enheten har sensorer för acceleration i dessa tre riktningar.

När enheten förs åt ett visst håll mäts rörelsens acceleration i denna riktning.


Figur 4 Riktningar i X- Y och Z-led

### 1.4 Länkar

1.4.1 GitHub
Länkar till projektets GitHub-sida

GitHub-sida för projektet
https://github.com/GoblinDynamiteer/stepCounter

GitHub-sida, huvudkod
https://github.com/GoblinDynamiteer/stepCounter/blob/master/Kod/Huvudkod/stepCounter/mpu_conntest/main.c (https://github.com/GoblinDynamiteer/stepCounter/blob/master/Kod/Huvudkod/stepCounter/mpu_conntest/main.c)

GitHub-sida, kod för prototyp 1 https://github.com/GoblinDynamiteer/stepCounter/blob/master/Kod/Testkod/Arduino/stepCounterPrototype/stepCounterPrototype.ino (https://github.com/GoblinDynamiteer/stepCounter/blob/master/Kod/Testkod/Arduino/stepCounterPrototype/stepCounterPrototype.ino)

1.4.2 Använda funktionsbibliotek
Länkar till bibliotek som har använts i projektets kod

MPU 6050 library
http://davidegironi.blogspot.se/2013/02/avr-atmega-mpu6050-gyroscope-and.html#.WOtTeojyhPY

U8glib
https://github.com/olikraus/u8glib

I2C master library
http://homepage.hispeed.ch/peterfleury/avr-software.html#libs

1.4.3 Datablad
Atmega328p
https://github.com/GoblinDynamiteer/stepCounter/blob/master/Dokumentation/Komponenter/Atmega%20328p/ATmega328P_datasheet_Complete.pdf (https://github.com/GoblinDynamiteer/stepCounter/blob/master/Dokumentation/Komponenter/Atmega%20328p/ATmega328P_datasheet_Complete.pdf)

MPU-9250
https://github.com/GoblinDynamiteer/stepCounter/blob/master/Dokumentation/Komponenter/MPU%209250/MPU-9250-Datasheet.pdf (https://github.com/GoblinDynamiteer/stepCounter/blob/master/Dokumentation/Komponenter/MPU%209250/MPU-9250-Datasheet.pdf)

SSD1306 Display
https://github.com/GoblinDynamiteer/stepCounter/blob/master/Dokumentation/Komponenter/Micro%20OLED%20Breakout%20Display%20SSD1306/SSD1306_datasheet.pdf (https://github.com/GoblinDynamiteer/stepCounter/blob/master/Dokumentation/Komponenter/Micro%20OLED%20Breakout%20Display%20SSD1306/SSD1306_datasheet.pdf)

1.4.4 Andra länkar
MPU-6050 Accelerometer + Gyro Kodexempel
http://playground.arduino.cc/Main/MPU-6050

SparkFun IMU Breakout - MPU-9250 Produktbeskrivning
https://www.sparkfun.com/products/13762

## 2 Genomförande och resultat

### 2.1 Använd programvara

Programnamn | Beskrivning
Atmel Studio 7.0 | IDE för att skriva kod och kompilera till Atmel MCU.
Atom | Texteditor, för att skriva och analysera kod.
Git | Versionshanteringsverktyg.
GitKraken | Grafiskt gränssnitt (GUI) för Git.
Fritzing | Program för att skapa kretsscheman.
Microsoft Word | Dokumentering och rapportskrivning.
Google Docs | Rapportskrivning.
AVRDUDE, AVR Downloader/UploaDEr | Program för att ladda upp kompilerad kod till MCU.
AVRDUDESS | Grafiskt gränssnitt (GUI) för AVRDUDE.
Autodesk Fusion 360 | CAD-program för att konstruera ett hölje till stegräknaren.

### 2.2 Använd hårdvara

Komponent | Beskrivning
Atmel ATMega328-PU DIP-28N 8-bit MCU | Mikrokontroller.
SparkFun MPU-9250 | Enhet som mäter acceleration i X, Y och Z-riktning. Innehåller även gyroskop, temperatur och kompass-funktionalitet.
Micro OLED Display SSD1306 128x64 | Display med upplösning 128x64 pixlar.
AVR pocket programmer | Enhet för att programmera Atmega-MCU via en dators USB-port.
DIL-hållare 28-pin 0.3" | Sockel för Atmega-MCU.
Resistor 4,7kΩ, 2 st. | Pull up-resistorer för I²C-kanaler.
Kristalloscillator 16 MHz | Kopplas till MCU för att öka klockfrekvensen från 1 MHz till 16 MHz.
Kondensator 22pF, 2 st. | Används för inkoppling av kristalloscillator.
Litiumbatteri 18650 | Strömförsörjning.
Hållare för litiumbatteri 18650
Grovekontakter med 4-stift | För modularisering av I²C-komponenter.
Kopplingsplatta 60x40 mm | För sammanlödning av komponenter.
Arduino UNO | För prototyping.

### 2.3 Metod

2.3.1 Skrivning av källkod, kompilering och uppladdning till mikrokontroller
Programmets källkod skrevs i utvecklingsmiljön Atmel Studio, som ett GCC C Executable Projectprojekt. Källkoden är skriven i programspråket C.

All egenskriven kod finns i projektets källkodsfil main.c.

Vid kompilering av koden skapas en fil med filändelsen hex i Atmel Studio-projektets Debugunderkatalog. Denna fil laddas upp till mikrokontrollern med datorprogrammet AVRDUDE och programmeringsenheten AVR pocket programmer.

Programmering utförs via ISP, följande anslutningar på mikrokontrollerns används.


Figur 5 Inkoppling av programmeraren till mikrokontrollern

Programmeringsenheten kan även användas som strömkälla.

2.3.2 Studie av datablad
Tidigt i projektet samlades datablad in för införskaffad hårdvara. Databladen studerades och relevant information noterades för att kunna användas vid framtagning av prototyp.

I synnerlighet studerades datablad för:

- MPU-9250
- Atmega328p
- OLED Display

2.3.3 Studie av funktionsbibliotek
Tidigt i projektet hämtades färdiga kodbibliotek från Internet, för projektets hårdvara. Koden i dessa bibliotek studerades, eller användes för att undersöka funktionen hos olika komponenter.

Exempel på bibliotek som studerades eller användes i projektets utveckling:

Bibliotek | Beskrivning och syfte
Wire.h | I 2C-bibliotek för Arduino-enheter. För att funktionstesta I²C-enheter med Arduino UNO. Användes även i koden för prototyp 1.
twitest.c | I 2C-test/demo för AVR-enheter.
mpu6050.h | MPU-6050 (Accelerometer, mm.) för AVR-enheter.
i2cmaster.h | I 2C-bibliotek för AVR-enheter.
ssd1306.c | Kod som använt sig av i2cmaster.h för att skriva ut text till display.

Koden studerades med bland annat texteditorn Atom och i utvecklingsmiljön Atmel Studio.

I Atmel Studio finns möjligheten att automatiskt gå till den fil där ett makro, en funktion eller en variabel är definierad. I bilden nedan utförs detta på funktionen fabs();

Figur 6 Gå till en implementation av ett makro, variabel eller funktion.

### 2.4 Prototyp 1

Projektets första prototyp, kallad prototyp 1, byggdes för att säkerställa att en stegräknare kunde konstrueras med en MPU-9250 som accelerometer. MPU-enheten kopplades direkt till en Arduino UNO-enhet via en breadboard.


Figur 7 Uppkoppling av MPU-9250 till Arduino UNO

Koden för prototyp 1 baserades på kod skapad av JohnChi ¹
, som skriver ut värden från MPU-6050-enheter till Arduino-utvecklingsmiljöns Serial Monitor. Koden skrevs om så att endast värden för acceleration hämtades, dessa användes för stegräkning.

Funktionsbiblioteket wire.h används för att ansluta MPU-n via I²C till Arduino-enheten. Portarna A4 och A5 används för SDA och SCL, respektive. En resistor med svärdet 560 Ohm används för att ta ner spänningsmatningen till MPU-n från 5V till ca 3V.
Enligt tillverkarens hemsida²
ska enheten drivas med 2.4V – 3.6V.

En bärbar dator användes för strömförsörjning och för att avläsa Serial Monitor. Avläsning av steg gjordes genom att placera prototypen i en byxficka och promenera runt.


Figur 8 Utskrift av stegräkning till Serial Monitor

En vibrationssensor testades också för att avläsa steg. Även om den kunde användas för avläsning, valdes den att inte användas, då MPU-enheten ansågs vara mer pålitlig.

Prototyp 1 färdigställdes 2017-03-21

Kopplingsschema för prototyp 1 kan ses i rapportens bilagor.

1
Se länk i kapitel 1.4.4
2
Se länk i kapitel 1.4.4

### 2.5 Prototyp 2

Vid byggnation av prototyp 2 användes en Atmega328p MCU.

En breadboard användes för samtliga inkopplingar innan sammanlödning av enheter påbörjades.

Initialt anslöts MPU-9250-enheten till mikrokontrollerns I

2C-anslutningar, med pull up-resistorer på båda kanaler. För att kunna indikera att MPU-n fungerade korrekt användes en blå LED. Lysdioden sattes att lysa när accelerationsdata från MPU-n översteg ett visst värde.

När displayen anslöts och kunde användas för att visa diverse data från MCU-n, blev lysdioden överflödig och användes inte längre.

En kristalloscillator på 16 MHz kopplades MCU-enhetens anslutningar 9 och 10. Dessa anslutningar används för inkoppling av externa kristalloscillatorer. Kristalloscillatorn användes för att öka klockfrekvensen på MCU-n. Enheten upplevdes också som stabilare.

När uppkopplingen på breadboard ansågs vara fungerande löddes MCU-n fast via en sockel på en kopplingsplatta. Tre stycken kontakter löddes till MCU-ns I²C-kanaler. Dessa kontakter går att använda för att koppla in olika enheter med I²C-stöd.

På displayen och MPU-enheten löddes kontakter fast, för anslutning till kontakterna på kopplingsplattan.

På kopplingsplattan löddes även övriga komponenter fast: kristalloscillator, resistorer och kondensatorer.


Figur 9 Lödda och urkopplade modulära komponenter

Ett en kasserad optisk mus användes som hölje för prototyp 2. Eltejp och smältlim användes för sammanfogning.


Figur 10 Prototyp 2 med hölje, framsida med display | Figur 11 Prototyp 2 med hölje, baksida med batteri

Efter sammanställning av prototyp 2, plockades delarna ut ur höljet, och en ytterligare anslutning löddes på kopplingsplattan, för programmering av mikroprocessorn via AVR pocket programmer.


Figur 12 Placering av fastlödda komponenter på kopplingsplatta


Figur 13 Komponenter lödda på kopplingsplatta, baksida

Prototyp 2 används som bas för den färdigställda produkten.

Kopplingsschema för prototyp 2 kan ses i rapportens bilagor.

### 2.6 Slutgiltig produkt

Elektronikmässigt är den färdiga produkten lik prototyp 2.

Skillnader är att koden har uppdaterats och utvecklats, och att dess hölje har bytts ut.

Höljet till den slutgiltiga produkten är byggt av en förvaringsbox för smycken. Ett uttag har gjorts i boxens lock, för inplacering av displayen. Displayen är fäst med tejp i locket, och övriga komponenter är fastsatta med smältlim i boxen.


Figur 14 Komponenter inplacerade i box | Figur 15 Komplett produkt

Produkten färdigställdes 2017-04-19

### 2.7 Stegräknarens funktion

Vid stegräknarens start kalibreras den genom att hämta 20 stycken värden för acceleration från MPU-9250-enheten. Stegräknaren bör ligga stilla under kalibreringen. Medelvärdet av de 20 värdena sätts till att vara stegräknarens värde för när den är passiv. Detta värde benämns som idle-värde.

Meddelandet "Calibrating.." visas på stegräknarens display under kalibreringen. När kalibreringen är färdig visas meddelandet "Idle.." på displayen, och stegräknaren kan börja användas.

Under användning hämtas accelerationsdata kontinuerligt från MPU-9250-enheten. Skillnaden mellan detta värde och idle-värdet beräknas som ett absolutvärde. Om skillnaden mellan dessa två värden överskrider ett visst satt tröskelvärde, så anses det att ett steg har tagits.

Vid varje taget steg uppdateras stegräknarens display med det totala antalet tagna steg.

Stegräknarens display sätts automatiskt i sömnläge om inget steg har tagits på ca 30 sekunder. Displayen vaknar automatiskt när ett steg tas.

### 2.8 Projektets kod

Utförligare kommentering av koden finns i källkodsfilen main.c.

3

2.8.1 Egeninkluderade standardbibliotek
Bibliotek | Beskrivning
<avr/io.h> | Diverse I/O definitioner för mikrokontrollern.
<util/delay.h> | För funktionen _delay_ms() som pauserar programmet i angiver antal millisekunder.
<avr/interrupt.h> | Används för funktionen sei(), som aktiverar interrupt på mikrokontrollern. Behövs för kommunikation med MPU-9250.
<math.h> | Diverse matematikfunktioner och macron. Används för funktionen fabs(), som ger absolutvärdet av ett tal.
<stdio.h> | För funktionen sprintf(), som skriver en formaterad textsträng till en char-array. Används för att skriva ut stegräkning till display.

2.8.2 Inkluderade icke-standardbibliotek
Flera av dessa bibliotek har egna inkluderingar av olika standardbibliotek.
Bibliotek | Beskrivning
"i2chw/i2cmaster.h" I2C master library using hardware TWI interface Skapat av Peter Fleury | I 2C-funktionalitet för AVR-enheter. För kommunikation mellan mikrokontroller och enheter anslutna till dess I 2C-portar SDA/SCL.
"mpu6050/mpu6050.h" MPU6050 lib 0x02 Skapat av Davide Gironi | 2C. Viss egen För accelerometer-enheten, via I kod har skrivits genom att bryta ut kod från detta bibliotek.
"u8g/u8g.h" Universal 8bit Graphics Library Skapat av olikraus | Funktionsbibliotek till AVR för diverse displayer.

3
För länk, se kapitel 1.4.1

2.8.3 Macron definierade i main.c
Macron som är definierade i main.c
Namn | Värde | Beskrivning
X | 0x3B | Address för accelerometerdata i X-riktning i MPU-9250
Y | 0x3D | Address för accelerometerdata i Y-riktning i MPU-9250
Z | 0x3F | Address för accelerometerdata i Z-riktning i MPU-9250
STEP_ACC_TRIGGER | 2.3 | Tröskelvärde för acceleration, att bestämma om ett steg har tagits.
SET_IDLE_LOOP | 20 | Antal värden som ska hämtas från accelerometern för att bestämma “idle”-värde. Det värde som accelerometern ger när den anses ligga stilla.
DISPLAY_LINE_HEIGHT | 16 | Pixelhöjd för en rad på displayen. Används vid utskrift av text.
DISPLAY_MIDDLE | (DISPLAY_LINE_HEIGHT * 2 + 2) | Ungefärligt pixelvärde för utskrift på displayens mitt.
DISPLAY_SLEEP_DELAY | 3000 | När värdet i variabeln displaySleepTimer når detta värdet sätts displayen i sömnläge.

Macrot F_CPU behövs vara angivet för standardbiblioteket delay.h, detta sätts i kodprojektets egenskaper till F_CPU=16000000, i programmet Atmel Studio.


Figur 16 Kodprojektets egenskaper – Defined symbols

2.8.4 Macron från andra bibliotek
Macron som används i main.c, vilka är definierade i andra bibliotek.
Namn | Värde | Från bibliotek | Beskrivning
MPU6050_ADDR | (0x68 <<1) | mpu6050.h | I²C-address för MPU-9250
MPU6050_AGAIN | 16384.0 | mpu6050.h | Värde för att omvandla ”rå” accelerationsdata från MPU-9250 till g-krafter.
I2C_WRITE | 0 | i2cmaster.h | Datariktning för I²C - för att skriva till en enhet.
I2C_READ | 1 | i2cmaster.h | Datariktning för I²C - för att läsa från en enhet

2.8.5 Variabler
Variabler i källkoden, sätts i main.c
Namn | Beskrivning
uint16_t steps | Håller stegräkning.
double accIdle | Värde som sätts vid programmets uppstart, håller det värde som accelerometern ger när den ligger helt stilla.
double accCombined | Sammansatt accelerationsvärde från X- Y- och Z-riktning.
double accX, accY, accZ | Värden för acceleration i X- Y- och Z-riktning.
int displaySleeping | Håller displayens sömnläge, sätts till 1 om displayen är i sömnläge, annars 0.
int displaySleepTimer | Används som timer för displayens sömnläge. Ökar med 1 för varje varv i programmets huvudloop.
u8g_t u8g | Struct för biblioteket Universal 8bit Graphics Library, för display.

2.8.6 Funktioner
Egenskrivna funktioner i källkoden
Namn | Beskrivning
double getAcc(int addr); | Hämtar accelerationsdata från MPU och ger värdet i retur. Som argument tar funktionen adressen till det register som ska läsas. Dessa adresser är definierade som macron X, Y och Z.
void drawSteps(uint16_t steps); | Skriver ut aktuellt antal steg till displayens mitt, som "Steps: x"
void drawString(char * string, int line); | Skriver ut en text till displayen. Texten ges som argument till funktionen, i form av en pekare till en char-sträng. Line är den rad på displayen där texten ska visas.
void setAccIdle(); | Sätter ett värde till den globala variabeln accIdle. Funktionen körs endast en gång vid varje uppstart av programmet.
double getAccXYZ(void); | Använder sig av funktionen getAcc() för att hämta accelerationsdata från X-, Y- och Z-riktningen. Det adderade värdet ges i retur.
void toggleDisplaySleep(void); | Sätter displayen i sömnläge, eller väcker displayen.
u8g_t u8g | Struct för biblioteket Universal 8bit Graphics Library, för display.

2.8.7 Main-funktionen
I detta kapitel beskrivs grundläggande vad som händer i programmets kod

Interrupt-funktionen aktiveras för MCU-enheten, detta behövs för att MPU-enheten ska fungera korrekt. Sedan initieras MPU-9250-enheten, med funktion från mpu6050.h

Displayen initieras och teckensnitt bestäms, funktioner från u8g.h

Texten ”STEPCOUNTER” visas på displayens mitt i en sekund.

Idle-värde för accelerometern sätts.

Programmets huvud-loop startar.

Ett kombinerat accelerationsvärde för X- Y- och Z-riktningar hämtas

Om skillnaden mellan det hämtade värdet och idle-värdet överskrider tröskelvärdet för att trigga ett steg, skriv ut antalet steg till displayen. Om displayen är i sömnläge, väck den.


Sätt display i sömnläge om timer har nått värde


Slut på huvud-loop.

## 3 Diskussion och slutsats

I denna del utförs diskussioner och tankegångar angående projektets genomförande och resultat

CAD / 3D-utskrift av hölje
Initialt planerades att konstruera ett eget hölje med hjälp av en 3D-skrivare. Vilket hade gett en anpassad form för stegräknaren. På grund av tidsbrist valdes en redan befintlig produkt att användas som hölje.


Figur 17 Rendering av CAD-modell för MCU och sockel

Byte av batterityp
Batteriet av typ 18650 tar upp en mycket stor del av stegräknarens volym. Ett eventuellt byte till ett volymmässigt mindre batteri, exempelvis av typen CR2032, skulle reducera båda volym och vikt. Det är dock oklart om detta batteri kan användas för drivning av produkten.


Figur 18 Batteri av typen CR2032

Fler I²C-moduler
Stegräknaren har stöd för inkoppling av en tredje enhet. I projektets gång gjordes tester med WiFimoduler av typen ESP8266, för att kunna kommunicera med stegräknaren trådlöst. Dock lyckades testerna och WiFi-stöd valdes att läggas ned.

En annan möjlig enhet skulle kunna vara en blåtand-modul.

Användning av färdigskrivna kodbibliotek
Flertalet redan färdiga bibliotek användes för att kommunicera med enheter som är kopplade till MCU-n. En framtida övning skulle kunna vara att försöka skriva egna funktioner för I²Ckommunikation.

Bättre detektion av steg
Stegräknaren anses i nuläget ej vara speciellt ackurat. Vid promenad detekteras oftast enbart steg på det ben där stegräknaren är placerad i byxfickan. Vid löpning, då större kraft utsöndras vid fotnedslag, detekteras båda benens steg.

Koden skulle kunna förbättras för att göra stegräknaren bättre.

Hastighet- och distans-mätning
Om stegräknaren hade tillgång till steglängden på den person som använder enheten, skull sträcka kunna mätas.

Även hastighet skulle kunna mätas, om stegräknaren hade tillgång till tid, t.ex. med en RTC-modul.

Avstängning
Stegräknaren är inte utrustad med någon strömbrytare, detta innebär att det enda sättet att stänga av eller nollställa enheten är att ta ur batteriet. Detta är ingen bra lösning.

På grund av tidsbrist och risk för att förstöra höljets lock vid uttag för strömbrytare valdes detta att inte implementeras.

## 4 Bilagor

### 4.1 Kopplingsschema för prototyp 1


### 4.2 Kopplingsschema för prototyp 2


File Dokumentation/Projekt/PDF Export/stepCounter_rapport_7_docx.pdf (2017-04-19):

# Stegräknare

## Projekt: Pedometer med AVR

Kurs

## Programmering av inbyggda system

2017-04-19


# Dennis Bunne

## LinkedIn (https://www.linkedin.com/in/dennis-bunne-259a9783/)

# Johan Kämpe

## LinkedIn (https://www.linkedin.com/in/johankampe/)

# Simon Karlsson

## LinkedIn (https://www.linkedin.com/in/simon-karlsson-54509aa9/)

## Mjukvaruutvecklare Inbyggda System

MÖLK Utbildning AB (http://dev.molk.com/)

Stegräknare | Programmering av inbyggda system | 2017-04-19

## Innehållsförteckning

## Figurförteckning

## 1 Inledning

### 1.1 Syfte

Syftet med projektet är att tillverka en bärbar, batteridriven stegräknare. Stegräknaren ska ha modulära enheter, det vill säga att dessa går att ta bort eller byta ut. En modulär enhet kan vara en display, blåtandsmodul eller accelerometer.

En display används för att visa antal tagna steg. Stegen ska avläsas med hjälp av en accelerometer, eller alternativt med en vibrationssensor.

### 1.2 Noteringar och information

Projektet utfördes på under perioden mars till april, 2017.

I rapporten hänvisas själva stegräknaren ofta till som projektet eller produkten.

I rapporten hänvisas MPU-9250-enheten, som används för att mäta acceleration, ofta som MPU-enheten, eller MPU-n.

### 1.3 Bakgrund

1.3.1 Definitioner av begrepp och förkortningar
Term | Förklaring
Acceleration | Förändring av hastighet per tidsenhet. Kan vara positiv (hastighetsökning) eller negativ (minskad hastighet).
Arduino UNO | Utvecklingskort.
Atmega328p | En mikrokontroller (MCU) med 28 anslutningar, från tillverkaren Atmel
AVR | Familj av Mikrokontrollers som tillverkas av företaget Atmel.
Bibliotek | En samling av kod-funktioner och/eller definitioner.
Breadboard | Kopplingsplatta, används för att ansluta enheter till varandra.
C Det programmeringsspråk som används i projektet.
DIL | Dual in-line. Standard för mikrochip med två rader av ben.
Git | Ett versionshanteringssystem
GitHub | Molnlagring för Git-projekt
I²C | Ett sätt att koppla samman enheter, via två ledare: SCL och SDA.
IDE | Integrated Development Environment. Ett datorprogram eller en programsvit som vanligtvis innehåller en texteditor, kompilator och debugger. För att underlätta vid programmering.
Interrupt | En del i en mikroprocessors funktionalitet. Ett sätt att få processorn att avbryta sitt nuvarande arbeta och övergå till en annan uppgift.
ISP | In-system programming, programmering av redan installerade eller inbyggda system.
LED | Light Emitting Diode, lysdiod.
Lib | Se Bibliotek.
Library | Se Bibliotek.
MCU | Microcontroller Unit, se Mikrokontroller.
Mikrokontroller | En liten enchippsdator med CPU, arbetsminne och programminne.
Mikroprocessor | Processor i ett chip
MPU | Microprocessor Unit, Se mikroprocessor
MPU-6050 | Mikroprocessor med sensor för gyro och acceleration i tre riktningar vardera.
MPU-9250 | Mikroprocessor med sensor för gyro, acceleration och kompass i tre riktningar vardera.
Pull up-reistor | Används i logiska kretsar för att se till att en ingång håller sig hög när den inte har någon anslutning.
Reistans | Värdet på ett motstånd / resistor. Anges i Ohm (Ω).
Resistor | Motstånd i elektriska kretsar.
SCL | Se I²C.
SDA | Se I²C.
Serial Monitor | Funktion i Arduinos IDE, för att kommunicera med inkopplad Arduino-enhet. Används ofta för debugging.
Standardbibliotek | Kodbibliotek som alltid är tillgängliga för ett specifikt programspråk. Exempelvis stdio.h för programspråket C.
Stegräknare | En enhet som mäter hur många steg en människa tar
TWI | Se I²C.
Utvecklingsmiljö | Se IDE.

1.3.2 Stegräknare
En stegräknare är en vanligtvis portabel enhet. Som mäter hur många steg en människa tar. Den kan användas vid exempelvis löpning, promenad, eller för att se hur många steg en person tar under en dag.

Stegräknare kan också kallas pedometer.

1.3.3 I²C
I²C, Inter-Integrated Circuit, är ett sätt att koppla enheter till moderkort, inbyggda system, mobiltelefoner eller andra enheter.

Kommunikation sker via två ledare, SDA (Serial Data Line, datasignal) och SCL (Serial Clock, klocksignal). Flera I²C-enheter kan anslutas till samma SDA- och SCL-ledare.

På en mikrokontroller av typen Atmega328p, är anslutningar 27 och 28, SDA och SCL, respektive.


Figur 1 I

2C-ansluting på Atmega328

I²C kallas även TWI, Two Wire Interface, eller IIC.

1.3.4 Pull up-resistorer
Pull up-resistorer används i logiska kretsar för att se till att en ingång håller sig hög när den inte har någon anslutning.

Utan pull up kan ingången anta vilket läge som helst, hög eller låg. I projektet används pull up-resistorer för I²C-anslutningarna.

Resistorer som används ska vara av hög resistans.

1.3.5 MPU-9250
Enheten som används i projektet för att mäta acceleration kallas MPU-9250 IMU Breakout och är tillverkad av Sparkfun. På enheten finns en MPU-9250.


Figur 2 MPU-9250, framsida | Figur 3 MPU-9250, baksida med anslutningsbeteckningar

De anslutningar som används i projektet är VDD och GND för drivning, samt SDA och SCL för I²Ckommunikation.

Länk till tillverkarens produktsida finns i kapitel 0

1.3.6 X-Y-Z-riktning
X, Y och Z används inom projektet för att beskriva riktningar i en tredimensionell miljö. MPU-9250-enheten har sensorer för acceleration i dessa tre riktningar.

När enheten förs åt ett visst håll mäts rörelsens acceleration i denna riktning.


Figur 4 Riktningar i X- Y och Z-led

### 1.4 Länkar

1.4.1 GitHub
Länkar till projektets GitHub-sida

GitHub-sida för projektet
https://github.com/GoblinDynamiteer/stepCounter

GitHub-sida, huvudkod
https://github.com/GoblinDynamiteer/stepCounter/blob/master/Kod/Huvudkod/stepCounter/mpu_conntest/main.c (https://github.com/GoblinDynamiteer/stepCounter/blob/master/Kod/Huvudkod/stepCounter/mpu_conntest/main.c)

GitHub-sida, kod för prototyp 1 https://github.com/GoblinDynamiteer/stepCounter/blob/master/Kod/Testkod/Arduino/stepCounterPrototype/stepCounterPrototype.ino (https://github.com/GoblinDynamiteer/stepCounter/blob/master/Kod/Testkod/Arduino/stepCounterPrototype/stepCounterPrototype.ino)

1.4.2 Använda funktionsbibliotek
Länkar till bibliotek som har använts i projektets kod

MPU 6050 library
http://davidegironi.blogspot.se/2013/02/avr-atmega-mpu6050-gyroscope-and.html#.WOtTeojyhPY

U8glib
https://github.com/olikraus/u8glib

I2C master library
http://homepage.hispeed.ch/peterfleury/avr-software.html#libs

1.4.3 Datablad
Atmega328p
https://github.com/GoblinDynamiteer/stepCounter/blob/master/Dokumentation/Komponenter/Atmega%20328p/ATmega328P_datasheet_Complete.pdf (https://github.com/GoblinDynamiteer/stepCounter/blob/master/Dokumentation/Komponenter/Atmega%20328p/ATmega328P_datasheet_Complete.pdf)

MPU-9250
https://github.com/GoblinDynamiteer/stepCounter/blob/master/Dokumentation/Komponenter/MPU%209250/MPU-9250-Datasheet.pdf (https://github.com/GoblinDynamiteer/stepCounter/blob/master/Dokumentation/Komponenter/MPU%209250/MPU-9250-Datasheet.pdf)

SSD1306 Display
https://github.com/GoblinDynamiteer/stepCounter/blob/master/Dokumentation/Komponenter/Micro%20OLED%20Breakout%20Display%20SSD1306/SSD1306_datasheet.pdf (https://github.com/GoblinDynamiteer/stepCounter/blob/master/Dokumentation/Komponenter/Micro%20OLED%20Breakout%20Display%20SSD1306/SSD1306_datasheet.pdf)

1.4.4 Andra länkar
MPU-6050 Accelerometer + Gyro Kodexempel
http://playground.arduino.cc/Main/MPU-6050

SparkFun IMU Breakout - MPU-9250 Produktbeskrivning
https://www.sparkfun.com/products/13762

## 2 Genomförande och resultat

### 2.1 Använd programvara

Programnamn | Beskrivning
Atmel Studio 7.0 | IDE för att skriva kod och kompilera till Atmel MCU.
Atom | Texteditor, för att skriva och analysera kod.
Git | Versionshanteringsverktyg
GitKraken | Grafiskt gränssnitt (GUI) för Git
Fritzing | Program för att skapa kretsscheman
Microsoft Word | Dokumentering och rapportskrivning
Google Docs | rapportskrivning
AVRDUDE, AVR Downloader/UploaDEr | Program för att ladda upp kompilerad kod till MCU.
AVRDUDESS | Grafiskt gränssnitt (GUI) för AVRDUDE
Autodesk Fusion 360 | CAD-program för att konstruera ett hölje till stegräknaren.

### 2.2 Använd hårdvara

Komponent | Beskrivning
Atmel ATMega328-PU DIP-28N 8-bit MCU | Mikrokontroller.
SparkFun MPU-9250 | Enhet som mäter acceleration i X, Y och Z-riktning. Innehåller även gyroskop, temperatur och kompass-funktionalitet.
Micro OLED Display SSD1306 128x64 | Display med upplösning 128x64 pixlar.
AVR pocket programmer | Enhet för att programmera Atmega-MCU via en dators USB-port.
DIL-hållare 28-pin 0.3" | Sockel för Atmega-MCU
Resistor 4,7kΩ, 2 st. | Pull up-resistorer för I²C-kanaler.
Kristalloscillator 16 MHz | Kopplas till MCU för att öka klockfrekvensen från 1 MHz till 16 MHz
Kondensator 22pF, 2 st. | Används för inkoppling av kristalloscillator.
Litiumbatteri 18650 | Strömförsörjning.
Hållare för litiumbatteri 18650
Grovekontakter med 4-stift | För modularisering av I²C-komponenter.
Kopplingsplatta 60x40 mm | För sammanlödning av komponenter.
Arduino UNO | Prototyping

### 2.3 Metod

2.3.1 Skrivning av källkod, kompilering och uppladdning till mikrokontroller
Programmets källkod skrevs i utvecklingsmiljön Atmel Studio, som ett GCC C Executable Projectprojekt. Källkoden är skriven i programspråket C.

All egenskriven kod finns i projektets källkodsfil main.c.

Vid kompilering av koden skapas en fil med filändelsen hex i Atmel Studio-projektets Debugunderkatalog. Denna fil laddas upp till mikrokontrollern med datorprogrammet AVRDUDE och programmeringsenheten AVR pocket programmer.

Programmering utförs via ISP, följande anslutningar på mikrokontrollerns används.


Figur 5 Inkoppling av programmeraren till mikrokontrollern

Programmeringsenheten kan även användas som strömkälla.

2.3.2 Studie av datablad
Tidigt i projektet samlades datablad in för införskaffad hårdvara. Databladen studerades och relevant information noterades för att kunna användas vid framtagning av prototyp.

I synnerlighet studerades datablad för:

- MPU-9250
- Atmega328p
- OLED Display

2.3.3 Studie av funktionsbibliotek
Tidigt i projektet letades diverse färdiga kodbibliotek upp, för projektets hårdvara. Koden i dessa bibliotek studerades, eller användes för att undersöka funktionen hos olika komponenter.

Exempel på bibliotek som studerades eller användes i projektets utveckling:

Bibliotek | Beskrivning och syfte
Wire.h | I 2C-bibliotek för Arduino-enheter. För att funktionstesta I²C-enheter med Arduino UNO. Användes även i koden för prototyp 1.
twitest.c | I 2C-test/demo för AVR-enheter.
mpu6050.h | MPU-6050 (Accelerometer, mm.) för AVR-enheter.
i2cmaster.h | I 2C-bibliotek för AVR-enheter.
ssd1306.c | Kod som använt sig av i2cmaster.h för att skriva ut text till display.

Koden studerades med bland annat texteditorn Atom och i utvecklingsmiljön Atmel Studio.

I Atmel Studio finns möjligheten att automatiskt gå till den fil där ett makro, en funktion eller en variabel är definierad. I bilden nedan utförs detta på funktionen fabs();

Figur 6 Gå till en implementation av ett makro, variabel eller funktion.

### 2.4 Prototyp 1

Projektets första prototyp, kallad prototyp 1, byggdes för att säkerställa att en stegräknare kunde konstrueras med en MPU-9250. MPU-enheten kopplades direkt till en Arduino UNO-enhet via en breadboard.


Figur 7 Uppkoppling av MPU-9250 till Arduino UNO

Koden för prototyp 1 baserades på kod skapad av JohnChi ¹
, som skriver ut värden från MPU-6050-enheter till Arduino-utvecklingsmiljöns Serial Monitor. Koden skrevs om så att endast värden för acceleration hämtades, dessa användes för stegräkning.

Funktionsbiblioteket wire.h används för att ansluta MPU-n via I²C till Arduino-enheten. Portarna A4 och A5 används för SDA och SCL, respektive. En resistor med resistansvärdet 560 Ohm används för att ta ner spänningsmatningen till MPU-n från 5V till ca 3V. Enligt tillverkarens hemsida²
ska enheten
drivas med 2.4 – 3.6 V.

En bärbar dator användes för strömförsörjning och för att avläsa Serial Monitor. Avläsning av steg gjordes genom att placera prototypen i en byxficka och promenera runt.


Figur 8 Utskrift av stegräkning till Serial Monitor

En vibrationssensor testades också för att avläsa steg. Även om den kunde användas för avläsning, valdes den att inte användas, då MPU-enheten ansågs vara mer pålitlig.

Prototyp 1 färdigställdes 2017-03-21

Kopplingsschema för prototyp 1 kan ses i rapportens bilagor.

1
Se länk i kapitel 0
2
Se länk i kapitel 0

### 2.5 Prototyp 2

Vid byggnation av prototyp 2 användes en Atmega328p MCU.

En breadboard användes för samtliga inkopplingar innan sammanlödning av enheter påbörjades.

Initialt anslöts MPU-9250-enheten till mikrokontrollerns I

2C-anslutningar, med pull up-resistorer på båda kanaler. För att kunna indikera att MPU-n fungerade korrekt användes en blå LED. Lysdioden sattes att lysa när accelerationsdata från MPU-n översteg ett visst värde.

När displayen anslöts och kunde användas för att visa diverse data från MCU-n, blev lysdioden överflödig och användes inte längre.

En kristalloscillator på 16 MHz kopplades MCU-enhetens anslutningar 9 och 10. Dessa anslutningar används för inkoppling av externa kristalloscillatorer. Kristalloscillatorn användes för att öka klockfrekvensen på MCU-n. Enheten upplevdes också som stabilare.

När uppkopplingen på breadboard ansågs vara fungerande löddes MCU-n fast via en sockel på en kopplingsplatta. Tre stycken kontakter löddes till MCU-ns I²C-kanaler. Dessa kontakter går att använda för att koppla in olika enheter med I²C-stöd.

På displayen och MPU-enheten löddes kontakter fast, för anslutning till kontakterna på kopplingsplattan.

På kopplingsplattan löddes även övriga komponenter dit: kristalloscillator, resistorer och kondensatorer.


Figur 9 Lödda och urkopplade modulära komponenter

Ett en kasserad optisk mus användes som hölje för prototyp 2. Eltejp och smältlim användes för sammanfogning.


Figur 10 Prototyp 2 med hölje, framsida med display | Figur 11 Prototyp 2 med hölje, baksida med batteri

Efter sammanställning av prototyp 2, plockades delarna ut ur höljet, och en ytterligare anslutning löddes på kopplingsplattan, för programmering av mikroprocessorn via AVR pocket programmer.


Figur 12 Placering av fastlödda komponenter på kopplingsplatta


Figur 13 Komponenter lödda på kopplingsplatta, baksida

Prototyp 2 används som bas för den färdigställda produkten.

Kopplingsschema för prototyp 2 kan ses i rapportens bilagor.

### 2.6 Slutgiltig produkt

Elektronikmässigt är den färdiga produkten lik prototyp 2.

Skillnader är att koden har uppdaterats och utvecklats, och att dess hölje har bytts ut.

Höljet till den slutgiltiga produkten är byggt av en förvaringsbox för smycken. Ett uttag har gjorts i boxens lock, för inplacering av displayen. Displayen är fäst med tejp i locket, och övriga komponenter är fastsatta med smältlim i boxen.


Figur 14 Komponenter inplacerade i box | Figur 15 Komplett produkt

Produkten färdigställdes 2017-04-19

### 2.7 Stegräknarens funktion

Vid stegräknarens start kalibreras den genom att hämta 20 stycken värden för acceleration från MPU-9250-enheten. Stegräknaren bör ligga stilla under kalibreringen. Medelvärdet av de 20 värdena sätts till att vara stegräknarens värde för när den är passiv. Detta värde benämns som idle-värde.

Meddelandet "Calibrating.." visas på stegräknarens display under kalibreringen. När kalibreringen är färdig visas meddelandet "Idle.." på displayen, och stegräknaren kan börja användas.

Under användning hämtas accelerationsdata kontinuerligt från MPU-9250-enheten. Skillnaden mellan detta värde och idle-värdet beräknas som ett absolutvärde. Om skillnaden mellan dessa två värden överskrider ett visst satt tröskelvärde, så anses det att ett steg har tagits.

Vid varje taget steg uppdateras stegräknarens display med det totala antalet tagna steg.

Stegräknarens display sätts automatiskt i sömnläge om inget steg har tagits på ca 30 sekunder. Displayen vaknar automatiskt när ett steg tas.

### 2.8 Projektets kod

Utförligare kommentering av koden finns i källkodsfilen main.c.

3

2.8.1 Egeninkluderade standardbibliotek
Bibliotek | Beskrivning
<avr/io.h> | Diverse I/O definitioner för mikrokontrollern.
<util/delay.h> | För funktionen _delay_ms() som pauserar programmet i angiver antal millisekunder.
<avr/interrupt.h> | Används för funktionen sei(), som aktiverar interrupt på mikrokontrollern. Behövs för kommunikation med MPU-9250.
<math.h> | Diverse matematikfunktioner och macron. Används för funktionen fabs(), som ger absolutvärdet av ett tal.
<stdio.h> | För funktionen sprintf(), som skriver en formaterad textsträng till en char-array. Används för att skriva ut stegräkning till display.

2.8.2 Inkluderade icke-standardbibliotek
Flera av dessa bibliotek har egna inkluderingar av olika standardbibliotek.
Bibliotek | Beskrivning
"i2chw/i2cmaster.h" I2C master library using hardware TWI interface Skapat av Peter Fleury | I 2C-funktionalitet för AVR-enheter. För kommunikation mellan mikrokontroller och enheter anslutna till dess I 2C-portar SDA/SCL.
"mpu6050/mpu6050.h" MPU6050 lib 0x02 Skapat av Davide Gironi | 2C. Viss egen För accelerometer-enheten, via I kod har skrivits genom att bryta ut kod från detta bibliotek.
"u8g/u8g.h" Universal 8bit Graphics Library Skapat av olikraus | Funktionsbibliotek till AVR för diverse displayer.

3
För länk, se kapitel 1.4.1

2.8.3 Macron definierade i main.c
Macron som är definierade i main.c
Namn | Värde | Beskrivning
X | 0x3B | Address för accelerometerdata i X-riktning i MPU-9250
Y | 0x3D | Address för accelerometerdata i Y-riktning i MPU-9250
Z | 0x3F | Address för accelerometerdata i Z-riktning i MPU-9250
STEP_ACC_TRIGGER | 2.3 | Tröskelvärde för acceleration, att bestämma om ett steg har tagits.
SET_IDLE_LOOP | 20 | Antal värden som ska hämtas från accelerometern för att bestämma “idle”-värde. Det värde som accelerometern ger när den anses ligga stilla.
DISPLAY_LINE_HEIGHT | 16 | Pixelhöjd för en rad på displayen. Används vid utskrift av text.
DISPLAY_MIDDLE | (DISPLAY_LINE_HEIGHT * 2 + 2) | Ungefärligt pixelvärde för utskrift på displayens mitt.
DISPLAY_SLEEP_DELAY | 3000 | När värdet i variabeln displaySleepTimer når detta värdet sätts displayen i sömnläge.

Macrot F_CPU behövs vara angivet för standardbiblioteket delay.h, detta sätts i kodprojektets egenskaper till F_CPU=16000000, i programmet Atmel Studio.


Figur 16 Kodprojektets egenskaper – Defined symbols

2.8.4 Macron från andra bibliotek
Macron som används i main.c, vilka är definierade i andra bibliotek.
Namn | Värde | Från bibliotek | Beskrivning
MPU6050_ADDR | (0x68 <<1) | mpu6050.h | I²C-address för MPU-9250
MPU6050_AGAIN | 16384.0 | mpu6050.h | Värde för att omvandla ”rå” accelerationsdata från MPU-9250 till g-krafter.
I2C_WRITE | 0 | i2cmaster.h | Datariktning för I²C - för att skriva till en enhet.
I2C_READ | 1 | i2cmaster.h | Datariktning för I²C - för att läsa från en enhet

2.8.5 Variabler
Variabler i källkoden, sätts i main.c
Namn | Beskrivning
uint16_t steps | Håller stegräkning.
double accIdle | Värde som sätts vid programmets uppstart, håller det värde som accelerometern ger när den ligger helt stilla.
double accCombined | Sammansatt accelerationsvärde från X- Y- och Z-riktning.
double accX, accY, accZ | Värden för acceleration i X- Y- och Z-riktning.
int displaySleeping | Håller displayens sömnläge, sätts till 1 om displayen är i sömnläge, annars 0.
int displaySleepTimer | Används som timer för displayens sömnläge. Ökar med 1 för varje varv i programmets huvudloop.
u8g_t u8g | Struct för biblioteket Universal 8bit Graphics Library, för display.

2.8.6 Funktioner
Egenskrivna funktioner i källkoden
Namn | Beskrivning
double getAcc(int addr); | Hämtar accelerationsdata från MPU och ger värdet i retur. Som argument tar funktionen adressen till det register som ska läsas. Dessa adresser är definierade som macron X, Y och Z.
void drawSteps(uint16_t steps); | Skriver ut aktuellt antal steg till displayens mitt, som "Steps: x"
void drawString(char * string, int line); | Skriver ut en text till displayen. Texten ges som argument till funktionen, i form av en pekare till en char-sträng. Line är den rad på displayen där texten ska visas.
void setAccIdle(); | Sätter ett värde till den globala variabeln accIdle. Funktionen körs endast en gång vid varje uppstart av programmet.
double getAccXYZ(void); | Använder sig av funktionen getAcc() för att hämta accelerationsdata från X-, Y- och Z-riktningen. Det adderade värdet ges i retur.
void toggleDisplaySleep(void); | Sätter displayen i sömnläge, eller väcker displayen.
u8g_t u8g | Struct för biblioteket Universal 8bit Graphics Library, för display.

2.8.7 Main-funktionen
I detta kapitel beskrivs grundläggande vad som händer i programmets kod

Interrupt-funktionen aktiveras för MCU-enheten, detta behövs för att MPU-enheten ska fungera korrekt. Sedan initieras MPU-9250-enheten, med funktion från mpu6050.h

Displayen initieras och teckensnitt bestäms, funktioner från u8g.h

Texten ”STEPCOUNTER” visas på displayens mitt i en sekund.

Idle-värde för accelerometern sätts.

Programmets huvud-loop startar.

Ett kombinerat accelerationsvärde för X- Y- och Z-riktningar hämtas

Om skillnaden mellan det hämtade värdet och idle-värdet överskrider tröskelvärdet för att trigga ett steg, skriv ut antalet steg till displayen. Om displayen är i sömnläge, väck den.


Sätt display i sömnläge om timer har nått värde


Slut på huvud-loop.

## 3 Diskussion och slutsats

I denna del utförs diskussioner och tankegångar angående projektets genomförande och resultat

CAD / 3D-utskrift av hölje
Initialt planerades att konstruera ett eget hölje med hjälp av en 3D-skrivare. Vilket hade gett en anpassad form för stegräknaren. På grund av tidsbrist valdes en redan befintlig produkt att användas som hölje.


Figur 17 Rendering av CAD-modell för MCU och sockel

Byte av batterityp
Batteriet av typ 18650 tar upp en mycket stor del av stegräknarens volym. Ett eventuellt byte till ett volymmässigt mindre batteri, exempelvis av typen CR2032, skulle reducera båda volym och vikt. Det är dock oklart om detta batteri kan användas för drivning av produkten.


Figur 18 Batteri av typen CR2032

Fler I²C-moduler
Stegräknaren har stöd för inkoppling av en tredje enhet. I projektets gång gjordes tester med WiFimoduler av typen ESP8266, för att kunna kommunicera med stegräknaren trådlöst. Dock lyckades testerna och WiFi-stöd valdes att läggas ned.

En annan möjlig enhet skulle kunna vara en blåtand-modul.

Användning av färdigskrivna kodbibliotek
Flertalet redan färdiga bibliotek användes för att kommunicera med enheter som är kopplade till MCU-n. En framtida övning skulle kunna vara att försöka skriva egna funktioner för I²Ckommunikation.

Bättre detektion av steg
Stegräknaren anses i nuläget ej vara speciellt ackurat. Vid promenad detekteras oftast enbart steg på det ben där stegräknaren är placerad i byxfickan. Vid löpning, då större kraft utsöndras vid fotnedslag, detekteras båda benens steg.

Koden skulle kunna förbättras för att göra stegräknaren bättre.

Hastighet- och distans-mätning
Om stegräknaren hade tillgång till steglängden på den person som använder enheten, skull sträcka kunna mätas.

Även hastighet skulle kunna mätas, om stegräknaren hade tillgång till tid, t.ex. med en RTC-modul.

Avstängning
Stegräknaren är inte utrustad med någon strömbrytare, detta innebär att det enda sättet att stänga av eller nollställa enheten är att ta ur batteriet. Detta är ingen bra lösning.

På grund av tidsbrist och risk för att förstöra höljets lock vid uttag för strömbrytare valdes detta att inte implementeras.

## 4 Bilagor

### 4.1 Kopplingsschema för prototyp 1


### 4.2 Kopplingsschema för prototyp 2


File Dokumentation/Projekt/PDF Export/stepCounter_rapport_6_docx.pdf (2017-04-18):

# Stegräknare

## Projekt: Pedometer med AVR

Kurs

## Programmering av inbyggda system

2017-04-19

SNYGG BILD?!

# Dennis Bunne

## LinkedIn (https://www.linkedin.com/in/dennis-bunne-259a9783/)

# Johan Kämpe

## LinkedIn (https://www.linkedin.com/in/johankampe/)

# Simon Karlsson

## LinkedIn (https://www.linkedin.com/in/simon-karlsson-54509aa9/)

## Mjukvaruutvecklare Inbyggda System

MÖLK Utbildning AB (http://dev.molk.com/)

Stegräknare | Programmering av inbyggda system | 2017-04-19

## Sammanfattning

Skriv när klar

## Innehållsförteckning

## Figurförteckning

## 1 Inledning

### 1.1 Syfte

Syftet med projektet är att tillverka en bärbar, batteridriven stegräknare. Stegräknaren ska ha modulära enheter, det vill säga att dessa går att ta bort eller byta ut. En modulär enhet kan vara en display, blåtandsmodul eller accelerometer.

En display används för att visa antal tagna steg. Stegen ska avläsas med hjälp av en accelerometer, eller alternativt med en vibrationssensor.

### 1.2 Noteringar och information

Projektet utfördes på under perioden mars till april, 2017.

I rapporten hänvisas själva stegräknaren ofta till som projektet eller produkten.

I rapporten hänvisas MPU-9250-enheten, som används för att mäta acceleration, ofta som MPU-enheten, eller MPU-n.

### 1.3 Bakgrund

1.3.1 Definitioner av begrepp och förkortningar
Term | Förklaring
Acceleration | Förändring av hastighet per tidsenhet. Kan vara positiv (hastighetsökning) eller negativ (minskad hastighet).
Arduino UNO | Utvecklingskort.
Atmega328p | En mikrokontroller (MCU) med 28 anslutningar, från tillverkaren Atmel
AVR | Familj av Mikrokontrollers som tillverkas av företaget Atmel.
Bibliotek | En samling av kod-funktioner och/eller definitioner.
Breadboard | Kopplingsplatta, används för att ansluta enheter till varandra.
C Det programmeringsspråk som används i projektet.
DIL | Dual in-line. Standard för mikrochip med två rader av ben.
Git | Ett versionshanteringssystem
GitHub | Molnlagring för Git-projekt
I²C | Ett sätt att koppla samman enheter, via två ledare: SCL och SDA.
IDE | Integrated Development Environment. Ett datorprogram eller en programsvit som vanligtvis innehåller en texteditor, kompilator och debugger. För att underlätta vid programmering.
ISP | In-system programming, programmering av redan installerade eller inbyggda system.
LED | Light Emitting Diode, lysdiod.
Lib | Se Bibliotek.
Library | Se Bibliotek.
MCU | Microcontroller Unit, se Mikrokontroller.
Mikrokontroller | En liten enchippsdator med CPU, arbetsminne och programminne.
Mikroprocessor | SKRIV
MPU | Microprocessor Unit, Se mikroprocessor
MPU-6050 | Mikroprocessor med sensor för gyro och acceleration i tre riktningar vardera.
MPU-9250 | Mikroprocessor med sensor för gyro, acceleration och kompass i tre riktningar vardera.
Pull up-reistor | Används i logiska kretsar för att se till att en ingång håller sig hög när den inte har någon anslutning.
Reistans | Värdet på ett motstånd / resistor. Anges i Ohm (Ω).
Resistor | Motstånd i elektriska kretsar.
SCL | Se I²C.
SDA | Se I²C.
Serial Monitor | Funktion i Arduinos IDE, för att kommunicera med inkopplad Arduino-enhet. Används ofta för debugging.
Standardbibliotek | Kodbibliotek som alltid är tillgängliga för ett specifikt programspråk. Exempelvis stdio.h för programspråket C.
Stegräknare | En enhet som mäter hur många steg en människa tar
TWI | Se I²C.
Utvecklingsmiljö | Se IDE.
Interrupt | SKRIV

SORTERA+FYLLPÅ

1.3.2 Stegräknare
En stegräknare är en vanligtvis portabel enhet. Som mäter hur många steg en människa tar. Den kan användas vid exempelvis löpning, promenad, eller för att se hur många steg en person tar under en dag.

Stegräknare kan också kallas pedometer.

1.3.3 I²C
I²C, Inter-Integrated Circuit, är ett sätt att koppla enheter till moderkort, inbyggda system, mobiltelefoner eller andra enheter.

Kommunikation sker via två ledare, SDA (Serial Data Line, datasignal) och SCL (Serial Clock, klocksignal). Flera I²C-enheter kan anslutas till samma SDA- och SCL-ledare.

På en mikrokontroller av typen Atmega328p, är anslutningar 27 och 28, SDA och SCL, respektive.


Figur 1 I

2C-ansluting på Atmega328

I²C kallas även TWI, Two Wire Interface, eller IIC.

1.3.4 Pull up-resistorer
Pull up-resistorer används i logiska kretsar för att se till att en ingång håller sig hög när den inte har någon anslutning.

Utan pull up kan ingången anta vilket läge som helst, hög eller låg. I projektet används pull up-resistorer för I²C-anslutningarna.

Resistorer som används ska vara av hög resistans.

1.3.5 MPU-9250
Enheten som används i projektet för att mäta acceleration kallas MPU-9250 IMU Breakout och är tillverkad av Sparkfun. På enheten finns en MPU-9250.


Figur 2 MPU-9250, framsida | Figur 3 MPU-9250, baksida med anslutningsbeteckningar

De anslutningar som används i projektet är VDD och GND för drivning, samt SDA och SCL för I²Ckommunikation.

Länk till tillverkarens produktsida finns i kapitel 1.4.4

1.3.6 X-Y-Z-riktning
X, Y och Z används inom projektet för att beskriva riktningar i en tredimensionell miljö. MPU-9250-enheten har sensorer för acceleration i dessa tre riktningar.

När enheten förs åt ett visst håll mäts rörelsens acceleration i denna riktning.


Figur 4 Riktningar i X- Y och Z-led

### 1.4 Länkar

1.4.1 GitHub
Länkar till projektets GitHub-sida

GitHub-sida för projektet
https://github.com/GoblinDynamiteer/stepCounter

GitHub-sida, huvudkod
https://github.com/GoblinDynamiteer/stepCounter/blob/master/Kod/Huvudkod/stepCounter/mpu_conntest/main.c (https://github.com/GoblinDynamiteer/stepCounter/blob/master/Kod/Huvudkod/stepCounter/mpu_conntest/main.c)

GitHub-sida, kod för prototyp 1 https://github.com/GoblinDynamiteer/stepCounter/blob/master/Kod/Testkod/Arduino/stepCounterPrototype/stepCounterPrototype.ino (https://github.com/GoblinDynamiteer/stepCounter/blob/master/Kod/Testkod/Arduino/stepCounterPrototype/stepCounterPrototype.ino)

1.4.2 Använda funktionsbibliotek
Länkar till bibliotek som har använts i projektets kod

MPU 6050 library
http://davidegironi.blogspot.se/2013/02/avr-atmega-mpu6050-gyroscope-and.html#.WOtTeojyhPY

U8glib
https://github.com/olikraus/u8glib

I2C master library
http://homepage.hispeed.ch/peterfleury/avr-software.html#libs

1.4.3 Datablad
Lista!!

1.4.4 Andra länkar
MPU-6050 Accelerometer + Gyro Kodexempel
http://playground.arduino.cc/Main/MPU-6050

SparkFun IMU Breakout - MPU-9250 Produktbeskrivning
https://www.sparkfun.com/products/13762

## 2 Genomförande och resultat

### 2.1 Använd programvara

Programnamn | Beskrivning
Atmel Studio 7.0 | IDE för att skriva kod och kompilera till Atmel MCU.
Atom | Texteditor, för att skriva och analysera kod.
Git | Versionshanteringsverktyg
GitKraken | Grafiskt gränssnitt (GUI) för Git
Fritzing | Program för att skapa kretsscheman
Microsoft Word | Dokumentering och rapportskrivning
Google Docs | rapportskrivning
AVRDUDE, AVR Downloader/UploaDEr | Program för att ladda upp kompilerad kod till MCU.
AVRDUDESS | Grafiskt gränssnitt (GUI) för AVRDUDE
Autodesk Fusion 360 | CAD-program för att konstruera ett hölje till stegräknaren.

### 2.2 Använd hårdvara

Komponent | Beskrivning
Atmel ATMega328-PU DIP-28N 8-bit MCU | Mikrokontroller.
SparkFun MPU-9250 | Enhet som mäter acceleration i X, Y och Z-riktning. Innehåller även gyroskop, temperatur och kompass-funktionalitet.
Micro OLED Display SSD1306 128x64 | Display med upplösning 128x64 pixlar.
AVR pocket programmer | Enhet för att programmera Atmega-MCU via en dators USB-port.
DIL-hållare 28-pin 0.3" | Sockel för Atmega-MCU
Resistor 4,7kΩ, 2 st. | Pull up-resistorer för I²C-kanaler.
Kristalloscillator 16 MHz | Kopplas till MCU för att öka klockfrekvensen från 1 MHz till 16 MHz
Kondensator 22pF, 2 st. | Används för inkoppling av kristalloscillator.
Litiumbatteri 18650 | Strömförsörjning.
Hållare för litiumbatteri 18650
Grovekontakter med 4-stift | För modularisering av I²C-komponenter.
Kopplingsplatta 60x40 mm | För sammanlödning av komponenter.
Arduino UNO | Prototyping

### 2.3 Avgränsningar

SKRIV/EL EV. TA BORT!!!!!

### 2.4 Metod

2.4.1 Skrivning av källkod, kompilering och uppladdning till mikrokontroller
Programmets källkod skrevs i utvecklingsmiljön Atmel Studio, som ett GCC C Executable Projectprojekt. Källkoden är skriven i programspråket C.

All egenskriven kod finns i projektets källkodsfil main.c.

Vid kompilering av koden skapas en fil med filändelsen hex i Atmel Studio-projektets Debugunderkatalog. Denna fil laddas upp till mikrokontrollern med datorprogrammet AVRDUDE och programmeringsenheten AVR pocket programmer.

Programmering utförs via ISP, följande anslutningar på mikrokontrollerns används.


Figur 5 Inkoppling av programmeraren till mikrokontrollern

Programmeringsenheten kan även användas som strömkälla.

2.4.2 Studie av datablad
Tidigt i projektet samlades datablad in för införskaffad hårdvara. Databladen studerades och relevant information noterades för att kunna användas vid framtagning av prototyp.

I synnerlighet studerades datablad för:

- MPU-9250
- Atmega328p
- OLED Display

2.4.3 Studie av funktionsbibliotek
Tidigt i projektet letades diverse färdiga kodbibliotek upp, för projektets hårdvara. Koden i dessa bibliotek studerades, eller användes för att undersöka funktionen hos olika komponenter.

Exempel på bibliotek som studerades eller användes i projektets utveckling:

Bibliotek | Beskrivning och syfte
Wire.h | I 2C-bibliotek för Arduino-enheter. För att funktionstesta I²C-enheter med Arduino UNO. Användes även i koden för prototyp 1.
twitest.c | I 2C-test/demo för AVR-enheter.
mpu6050.h | MPU-6050 (Accelerometer, mm.) för AVR-enheter.
i2cmaster.h | I 2C-bibliotek för AVR-enheter.
ssd1306.c | Kod som använt sig av i2cmaster.h för att skriva ut text till display.

Koden studerades med bland annat texteditorn Atom och i utvecklingsmiljön Atmel Studio.

I Atmel Studio finns möjligheten att automatiskt gå till den fil där ett makro, en funktion eller en variabel är definierad. I bilden nedan utförs detta på funktionen fabs();

Figur 6 Gå till en implementation av ett makro, variabel eller funktion.

### 2.5 Prototyp 1

Projektets första prototyp, kallad prototyp 1, byggdes för att säkerställa att en stegräknare kunde konstrueras med en MPU-9250. MPU-enheten kopplades direkt till en Arduino UNO-enhet via en breadboard.


Figur 7 Uppkoppling av MPU-9250 till Arduino UNO

Koden för prototyp 1 baserades på kod skapad av JohnChi ¹
, som skriver ut värden från MPU-6050-enheter till Arduino-utvecklingsmiljöns Serial Monitor. Koden skrevs om så att endast värden för acceleration hämtades, dessa användes för stegräkning.

Funktionsbiblioteket wire.h används för att ansluta MPU-n via I²C till Arduino-enheten. Portarna A4 och A5 används för SDA och SCL, respektive. En resistor med resistansvärdet 560 Ohm används för att ta ner spänningsmatningen till MPU-n från 5V till ca 3V. Enligt tillverkarens hemsida²
ska enheten
drivas med 2.4 – 3.6 V.

En bärbar dator användes för strömförsörjning och för att avläsa Serial Monitor. Avläsning av steg gjordes genom att placera prototypen i en byxficka och promenera runt.


Figur 8 Utskrift av stegräkning till Serial Monitor

En vibrationssensor testades också för att avläsa steg. Även om den kunde användas för avläsning, valdes den att inte användas, då MPU-enheten ansågs vara mer pålitlig.

Prototyp 1 färdigställdes 2017-03-21

Kopplingsschema för prototyp 1 kan ses i rapportens bilagor.

1
Se länk i kapitel 1.4.4
2
Se länk i kapitel 1.4.4

### 2.6 Prototyp 2

Vid byggnation av prototyp 2 användes en Atmega328p MCU.

En breadboard användes för samtliga inkopplingar innan sammanlödning av enheter påbörjades.

Initialt anslöts MPU-9250-enheten till mikrokontrollerns I

2C-anslutningar, med pull up-resistorer på båda kanaler. För att kunna indikera att MPU-n fungerade korrekt användes en blå LED. Lysdioden sattes att lysa när accelerationsdata från MPU-n översteg ett visst värde.

När displayen anslöts och kunde användas för att visa diverse data från MCU-n, blev lysdioden överflödig och användes inte längre.

En kristalloscillator på 16 MHz kopplades MCU-enhetens anslutningar 9 och 10. Dessa anslutningar används för inkoppling av externa kristalloscillatorer. Kristalloscillatorn användes för att öka klockfrekvensen på MCU-n. Enheten upplevdes också som stabilare.

När uppkopplingen på breadboard ansågs vara fungerande löddes MCU-n fast via en sockel på en kopplingsplatta. Tre stycken kontakter löddes till MCU-ns I²C-kanaler. Dessa kontakter går att använda för att koppla in olika enheter med I²C-stöd.

På displayen och MPU-enheten löddes kontakter fast, för anslutning till kontakterna på kopplingsplattan.

På kopplingsplattan löddes även övriga komponenter dit: kristalloscillator, resistorer och kondensatorer.


Figur 9 Lödda och urkopplade modulära komponenter

Ett en kasserad optisk mus användes som hölje för prototyp 2. Eltejp och smältlim användes för sammanfogning.


Figur 10 Prototyp 2 med hölje, framsida med display | Figur 11 Prototyp 2 med hölje, baksida med batteri

Efter sammanställning av prototyp 2, plockades delarna ut ur höljet, och en ytterligare anslutning löddes på kopplingsplattan, för programmering av mikroprocessorn via AVR pocket programmer.


Figur 12 Placering av fastlödda komponenter på kopplingsplatta


Figur 13 Komponenter lödda på kopplingsplatta, baksida

Prototyp 2 används som bas för den färdigställda produkten.

Kopplingsschema för prototyp 2 kan ses i rapportens bilagor.

### 2.7 Slutgiltig produkt

Text

### 2.8 Stegräknarens funktion

Vid stegräknarens start kalibreras den genom att hämta 20 stycken värden för acceleration från MPU-9250-enheten. Stegräknaren bör ligga stilla under kalibreringen. Medelvärdet av de 20 värdena sätts till att vara stegräknarens värde för när den är passiv. Detta värde benämns som idle-värde.

Meddelandet "Calibrating.." visas på stegräknarens display under kalibreringen. När kalibreringen är färdig visas meddelandet "Idle.." på displayen, och stegräknaren kan börja användas.

Under användning hämtas accelerationsdata kontinuerligt från MPU-9250-enheten. Skillnaden mellan detta värde och idle-värdet beräknas som ett absolutvärde. Om skillnaden mellan dessa två värden överskrider ett visst satt tröskelvärde, så anses det att ett steg har tagits.

Vid varje taget steg uppdateras stegräknarens display med det totala antalet tagna steg.

Stegräknarens display sätts automatiskt i sömnläge om inget steg har tagits på ca 30 sekunder. Displayen vaknar automatiskt när ett steg tas.

### 2.9 Projektets kod

Utförligare kommentering av koden finns i källkodsfilen main.c.

3

2.9.1 Egeninkluderade standardbibliotek
Bibliotek | Beskrivning
<avr/io.h> | Diverse I/O definitioner för mikrokontrollern.
<util/delay.h> | För funktionen _delay_ms() som pauserar programmet i angiver antal millisekunder.
<avr/interrupt.h> | Används för funktionen sei(), som aktiverar interrupt på mikrokontrollern. Behövs för kommunikation med MPU-9250.
<math.h> | Diverse matematikfunktioner och macron. Används för funktionen fabs(), som ger absolutvärdet av ett tal.
<stdio.h> | För funktionen sprintf(), som skriver en formaterad textsträng till en char-array. Används för att skriva ut stegräkning till display.

2.9.2 Inkluderade icke-standardbibliotek
Flera av dessa bibliotek har egna inkluderingar av olika standardbibliotek.
Bibliotek | Beskrivning
"i2chw/i2cmaster.h" I2C master library using hardware TWI interface Skapat av Peter Fleury | I 2C-funktionalitet för AVR-enheter. För kommunikation mellan mikrokontroller och enheter anslutna till dess I 2C-portar SDA/SCL.
"mpu6050/mpu6050.h" MPU6050 lib 0x02 Skapat av Davide Gironi | 2C. Viss egen För accelerometer-enheten, via I kod har skrivits genom att bryta ut kod från detta bibliotek.
"u8g/u8g.h" Universal 8bit Graphics Library Skapat av olikraus | Funktionsbibliotek till AVR för diverse displayer.

3
För länk, se kapitel 1.4.1

2.9.3 Macron definierade i main.c
Macron som är definierade i main.c
Namn | Värde | Beskrivning
X | 0x3B | Address för accelerometerdata i X-riktning i MPU-9250
Y | 0x3D | Address för accelerometerdata i Y-riktning i MPU-9250
Z | 0x3F | Address för accelerometerdata i Z-riktning i MPU-9250
STEP_ACC_TRIGGER | 2.3 | Tröskelvärde för acceleration, att bestämma om ett steg har tagits.
SET_IDLE_LOOP | 20 | Antal värden som ska hämtas från accelerometern för att bestämma “idle”-värde. Det värde som accelerometern ger när den anses ligga stilla.
DISPLAY_LINE_HEIGHT | 16 | Pixelhöjd för en rad på displayen. Används vid utskrift av text.
DISPLAY_MIDDLE | (DISPLAY_LINE_HEIGHT * 2 + 2) | Ungefärligt pixelvärde för utskrift på displayens mitt.
DISPLAY_SLEEP_DELAY | 3000 | När värdet i variabeln displaySleepTimer når detta värdet sätts displayen i sömnläge.

Macrot F_CPU behövs vara angivet för standardbiblioteket delay.h, detta sätts i kodprojektets egenskaper till F_CPU=16000000, i programmet Atmel Studio.


Figur 14 Kodprojektets egenskaper – Defined symbols

2.9.4 Macron från andra bibliotek
Macron som används i main.c, vilka är definierade i andra bibliotek.
Namn | Värde | Från bibliotek | Beskrivning
MPU6050_ADDR | (0x68 <<1) | mpu6050.h | I²C-address för MPU-9250
MPU6050_AGAIN | 16384.0 | mpu6050.h | Värde för att omvandla ”rå” accelerationsdata från MPU-9250 till g-krafter.
I2C_WRITE | 0 | i2cmaster.h | Datariktning för I²C - för att skriva till en enhet.
I2C_READ | 1 | i2cmaster.h | Datariktning för I²C - för att läsa från en enhet

2.9.5 Variabler
Variabler i källkoden, sätts i main.c
Namn | Beskrivning
uint16_t steps | Håller stegräkning.
double accIdle | Värde som sätts vid programmets uppstart, håller det värde som accelerometern ger när den ligger helt stilla.
double accCombined | Sammansatt accelerationsvärde från X- Y- och Z-riktning.
double accX, accY, accZ | Värden för acceleration i X- Y- och Z-riktning.
int displaySleeping | Håller displayens sömnläge, sätts till 1 om displayen är i sömnläge, annars 0.
int displaySleepTimer | Används som timer för displayens sömnläge. Ökar med 1 för varje varv i programmets huvudloop.
u8g_t u8g | Struct för biblioteket Universal 8bit Graphics Library, för display.

2.9.6 Funktioner
Egenskrivna funktioner i källkoden
Namn | Beskrivning
double getAcc(int addr); | Hämtar accelerationsdata från MPU och ger värdet i retur. Som argument tar funktionen adressen till det register som ska läsas. Dessa adresser är definierade som macron X, Y och Z.
void drawSteps(uint16_t steps); | Skriver ut aktuellt antal steg till displayens mitt, som "Steps: x"
void drawString(char * string, int line); | Skriver ut en text till displayen. Texten ges som argument till funktionen, i form av en pekare till en char-sträng. Line är den rad på displayen där texten ska visas.
void setAccIdle(); | Sätter ett värde till den globala variabeln accIdle. Funktionen körs endast en gång vid varje uppstart av programmet.
double getAccXYZ(void); | Använder sig av funktionen getAcc() för att hämta accelerationsdata från X-, Y- och Z-riktningen. Det adderade värdet ges i retur.
void toggleDisplaySleep(void); | Sätter displayen i sömnläge, eller väcker displayen.
u8g_t u8g | Struct för biblioteket Universal 8bit Graphics Library, för display.

2.9.7 Main-funktionen
I detta kapitel beskrivs grundläggande vad som händer i programmets kod

Interrupt-funktionen aktiveras för MCU-enheten, detta behövs för att MPU-enheten ska fungera korrekt. Sedan initieras MPU-9250-enheten, med funktion från mpu6050.h

Displayen initieras och teckensnitt bestäms, funktioner från u8g.h

Texten ”STEPCOUNTER” visas på displayens mitt i en sekund.

Idle-värde för accelerometern sätts.

Programmets huvud-loop startar.

Ett kombinerat accelerationsvärde för X- Y- och Z-riktningar hämtas

Om skillnaden mellan det hämtade värdet och idle-värdet överskrider tröskelvärdet för att trigga ett steg, skriv ut antalet steg till displayen. Om displayen är i sömnläge, väck den.


Sätt display i sömnläge om timer har nått värde


Slut på huvud-loop.

## 3 Diskussion och slutsats

I denna del utförs diskussioner och tankegångar angående projektets genomförande och resultat

CAD / 3D-utskrift av hölje
Initialt planerades att konstruera ett eget hölje med hjälp av en 3D-skrivare. Vilket hade gett en anpassad form för stegräknaren. På grund av tidsbrist valdes en redan befintlig produkt att användas som hölje.


Figur 15 Rendering av CAD-modell för MCU och sockel

Byte av batterityp
Batteriet av typ 18650 tar upp en mycket stor del av stegräknarens volym. Ett eventuellt byte till ett volymmässigt mindre batteri, exempelvis av typen CR2032, skulle reducera båda volym och vikt. Det är dock oklart om detta batteri kan användas för drivning av produkten.


Figur 16 Batteri av typen CR2032

Fler I²C-moduler
Stegräknaren har stöd för inkoppling av en tredje enhet. I projektets gång gjordes tester med WiFimoduler av typen ESP8266, för att kunna kommunicera med stegräknaren trådlöst. Dock lyckades testerna och WiFi-stöd valdes att läggas ned.

En annan möjlig enhet skulle kunna vara en blåtand-modul.

Användning av färdigskrivna kodbibliotek
Flertalet redan färdiga bibliotek användes för att kommunicera med enheter som är kopplade till MCU-n. En framtida övning skulle kunna vara att försöka skriva egna funktioner för I

2C-
kommunikation.

Bättre detektion av steg
Stegräknaren anses i nuläget ej vara speciellt ackurat. Vid promenad detekteras oftast enbart steg på det ben där stegräknaren är placerad i byxfickan. Vid löpning, då större kraft utsöndras vid fotnedslag, detekteras båda benens steg.

Koden skulle kunna förbättras för att göra stegräknaren bättre.

Hastighet- och distans-mätning
Om stegräknaren hade tillgång till steglängden på den person som använder enheten, skull sträcka kunna mätas.

Även hastighet skulle kunna mätas, om stegräknaren hade tillgång till tid, t.ex. med en RTC-modul.

## 4 Bilagor

### 4.1 Kopplingsschema för prototyp 1


### 4.2 Kopplingsschema för prototyp 2


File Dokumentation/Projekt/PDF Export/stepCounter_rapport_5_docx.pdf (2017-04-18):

# Stegräknare

## Projekt: Pedometer med AVR

Kurs

## Programmering av inbyggda system

2017-04-18

# Dennis Bunne

## LinkedIn (https://www.linkedin.com/in/dennis-bunne-259a9783/)

# Johan Kämpe

## LinkedIn (https://www.linkedin.com/in/johankampe/)

# Simon Karlsson

## LinkedIn (https://www.linkedin.com/in/simon-karlsson-54509aa9/)

## Mjukvaruutvecklare Inbyggda System

MÖLK Utbildning AB (http://dev.molk.com/)

Stegräknare | Programmering av inbyggda system | 2017-04-19

## Sammanfattning

Skriv när klar

## Innehållsförteckning

## Figurförteckning

## 1 Inledning

### 1.1 Syfte

Syftet med projektet är att tillverka en bärbar, batteridriven stegräknare. Stegräknaren ska ha modulära enheter, det vill säga att dessa går att ta bort eller byta ut. En modulär enhet kan vara en display, blåtandsmodul eller accelerometer.

En display används för att visa antal tagna steg. Stegen ska avläsas med hjälp av en accelerometer, eller alternativt med en vibrationssensor.

### 1.2 Noteringar och information

Projektet utfördes på under perioden mars till april, 2017.

I rapporten hänvisas själva stegräknaren ofta till som projektet eller produkten.

I rapporten hänvisas MPU-9250-enheten, som används för att mäta acceleration, ofta som MPU-enheten, eller MPU-n.

### 1.3 Bakgrund

1.3.1 Definitioner av begrepp och förkortningar
Term | Förklaring
Acceleration | Förändring av hastighet per tidsenhet. Kan vara positiv (hastighetsökning) eller negativ (minskad hastighet).
Arduino UNO | Utvecklingskort.
Atmega328p | En mikrokontroller (MCU) med 28 anslutningar, från tillverkaren Atmel
AVR | Familj av Mikrokontrollers som tillverkas av företaget Atmel.
Bibliotek | En samling av kod-funktioner och/eller definitioner.
Breadboard | Kopplingsplatta, används för att ansluta enheter till varandra.
C Det programmeringsspråk som används i projektet.
DIL | Dual in-line. Standard för mikrochip med två rader av ben.
Git | Ett versionshanteringssystem
GitHub | Molnlagring för Git-projekt
I²C | Ett sätt att koppla samman enheter, via två ledare: SCL och SDA.
IDE | Integrated Development Environment. Ett datorprogram eller en programsvit som vanligtvis innehåller en texteditor, kompilator och debugger. För att underlätta vid programmering.
ISP | In-system programming, programmering av redan installerade eller inbyggda system.
LED | Light Emitting Diode, lysdiod.
Lib | Se Bibliotek.
Library | Se Bibliotek.
MCU | Microcontroller Unit, se Mikrokontroller.
Mikrokontroller | En liten enchippsdator med CPU, arbetsminne och programminne.
Mikroprocessor | SKRIV
MPU | Microprocessor Unit, Se mikroprocessor
MPU-6050 | Mikroprocessor med sensor för gyro och acceleration i tre riktningar vardera.
MPU-9250 | Mikroprocessor med sensor för gyro, acceleration och kompass i tre riktningar vardera.
Pull up-reistor | Används i logiska kretsar för att se till att en ingång håller sig hög när den inte har någon anslutning.
Reistans | Värdet på ett motstånd / resistor. Anges i Ohm (Ω).
Resistor | Motstånd i elektriska kretsar.
SCL | Se I²C.
SDA | Se I²C.
Serial Monitor | Funktion i Arduinos IDE, för att kommunicera med inkopplad Arduino-enhet. Används ofta för debugging.
Standardbibliotek | Kodbibliotek som alltid är tillgängliga för ett specifikt programspråk. Exempelvis stdio.h för programspråket C.
Stegräknare | En enhet som mäter hur många steg en människa tar
TWI | Se I²C.
Utvecklingsmiljö | Se IDE.
Interrupt | SKRIV

SORTERA+FYLLPÅ

1.3.2 Stegräknare
En stegräknare är en vanligtvis portabel enhet. Som mäter hur många steg en människa tar. Den kan användas vid exempelvis löpning, promenad, eller för att se hur många steg en person tar under en dag.

Stegräknare kan också kallas pedometer.

1.3.3 I²C
I²C, Inter-Integrated Circuit, är ett sätt att koppla enheter till moderkort, inbyggda system, mobiltelefoner eller andra enheter.

Kommunikation sker via två ledare, SDA (Serial Data Line, datasignal) och SCL (Serial Clock, klocksignal). Flera I²C-enheter kan anslutas till samma SDA- och SCL-ledare.

På en mikrokontroller av typen Atmega328p, är anslutningar 27 och 28, SDA och SCL, respektive.


Figur 1 I

2C-ansluting på Atmega328

I²C kallas även TWI, Two Wire Interface, eller IIC.

1.3.4 Pull up-resistorer
Pull up-resistorer används i logiska kretsar för att se till att en ingång håller sig hög när den inte har någon anslutning.

Utan pull up kan ingången anta vilket läge som helst, hög eller låg. I projektet används pull up-resistorer för I²C-anslutningarna.

Resistorer som används ska vara av hög resistans.

1.3.5 MPU-9250
Enheten som används i projektet för att mäta acceleration kallas MPU-9250 IMU Breakout och är tillverkad av Sparkfun. På enheten finns en MPU-9250.


Figur 2 MPU-9250, framsida | Figur 3 MPU-9250, baksida med anslutningsbeteckningar

De anslutningar som används i projektet är VDD och GND för drivning, samt SDA och SCL för I²Ckommunikation.

Länk till tillverkarens produktsida finns i kapitel 1.4.4

1.3.6 X-Y-Z-riktning
X, Y och Z används inom projektet för att beskriva riktningar i en tredimensionell miljö. MPU-9250-enheten har sensorer för acceleration i dessa tre riktningar.

När enheten förs åt ett visst håll mäts rörelsens acceleration i denna riktning.


Figur 4 Riktningar i X- Y och Z-led

### 1.4 Länkar

1.4.1 GitHub
Länkar till projektets GitHub-sida

GitHub-sida för projektet
https://github.com/GoblinDynamiteer/stepCounter

GitHub-sida, huvudkod
https://github.com/GoblinDynamiteer/stepCounter/blob/master/Kod/Huvudkod/stepCounter/mpu_conntest/main.c (https://github.com/GoblinDynamiteer/stepCounter/blob/master/Kod/Huvudkod/stepCounter/mpu_conntest/main.c)

GitHub-sida, kod för prototyp 1 https://github.com/GoblinDynamiteer/stepCounter/blob/master/Kod/Testkod/Arduino/stepCounterPrototype/stepCounterPrototype.ino (https://github.com/GoblinDynamiteer/stepCounter/blob/master/Kod/Testkod/Arduino/stepCounterPrototype/stepCounterPrototype.ino)

1.4.2 Använda funktionsbibliotek
Länkar till bibliotek som har använts i projektets kod

MPU 6050 library
http://davidegironi.blogspot.se/2013/02/avr-atmega-mpu6050-gyroscope-and.html#.WOtTeojyhPY

U8glib
https://github.com/olikraus/u8glib

I2C master library
http://homepage.hispeed.ch/peterfleury/avr-software.html#libs

1.4.3 Datablad
Lista!!

1.4.4 Andra länkar
MPU-6050 Accelerometer + Gyro Kodexempel
http://playground.arduino.cc/Main/MPU-6050

SparkFun IMU Breakout - MPU-9250 Produktbeskrivning
https://www.sparkfun.com/products/13762

## 2 Genomförande och resultat

### 2.1 Använd programvara

Programnamn | Beskrivning
Atmel Studio 7.0 | IDE för att skriva kod och kompilera till Atmel MCU.
Atom | Texteditor, för att skriva och analysera kod.
Git | Versionshanteringsverktyg
GitKraken | Grafiskt gränssnitt (GUI) för Git
Fritzing | Program för att skapa kretsscheman
Microsoft Word | Dokumentering och rapportskrivning
Google Docs | rapportskrivning
AVRDUDE, AVR Downloader/UploaDEr | Program för att ladda upp kompilerad kod till MCU.
AVRDUDESS | Grafiskt gränssnitt (GUI) för AVRDUDE
Autodesk Fusion 360 | CAD-program för att konstruera ett hölje till stegräknaren.

### 2.2 Använd hårdvara

Komponent | Beskrivning
Atmel ATMega328-PU DIP-28N 8-bit MCU | Mikrokontroller.
SparkFun MPU-9250 | Enhet som mäter acceleration i X, Y och Z-riktning. Innehåller även gyroskop, temperatur och kompass-funktionalitet.
Micro OLED Display SSD1306 128x64 | Display med upplösning 128x64 pixlar.
AVR pocket programmer | Enhet för att programmera Atmega-MCU via en dators USB-port.
DIL-hållare 28-pin 0.3" | Sockel för Atmega-MCU
Resistor 4,7kΩ, 2 st. | Pull up-resistorer för I²C-kanaler.
Kristalloscillator 16 MHz | Kopplas till MCU för att öka klockfrekvensen från 1 MHz till 16 MHz
Kondensator 22pF, 2 st. | Används för inkoppling av kristalloscillator.
Litiumbatteri 18650 | Strömförsörjning.
Batterihållare för litiumbatteri 18650
Grovekontakter med 4-stift | För modularisering av I²C-komponenter.
Kopplingsplatta 60x40 mm | För sammanlödning av komponenter.
Arduino UNO | Prototyping

### 2.3 Avgränsningar

SKRIV/EL EV. TA BORT!!!!!

### 2.4 Metod

2.4.1 Skrivning av källkod, kompilering och uppladdning till mikrokontroller
Programmets källkod skrevs i utvecklingsmiljön Atmel Studio, som ett GCC C Executable Projectprojekt. Källkoden är skriven i programspråket C.

All egenskriven kod finns i projektets källkodsfil main.c.

Vid kompilering av koden skapas en fil med filändelsen hex i Atmel Studio-projektets Debugunderkatalog. Denna fil laddas upp till mikrokontrollern med datorprogrammet AVRDUDE och programmeringsenheten AVR pocket programmer.

Programmering utförs via ISP, följande anslutningar på mikrokontrollerns används.


Figur 5 Inkoppling av programmeraren till mikrokontrollern

Programmeringsenheten kan även användas som strömkälla.

2.4.2 Studie av datablad
Tidigt i projektet samlades datablad in för införskaffad hårdvara. Databladen studerades och relevant information noterades för att kunna användas vid framtagning av prototyp.

I synnerlighet studerades datablad för:

- MPU-9250
- Atmega328p
- OLED Display

2.4.3 Studie av funktionsbibliotek
Tidigt i projektet letades diverse färdiga kodbibliotek upp, för projektets hårdvara. Koden i dessa bibliotek studerades, eller användes för att undersöka funktionen hos olika komponenter.

Exempel på bibliotek som studerades eller användes i projektets utveckling:

Bibliotek | Beskrivning och syfte
Wire.h | I 2C-bibliotek för Arduino-enheter. För att funktionstesta I²C-enheter med Arduino UNO. Användes även i koden för prototyp 1.
twitest.c | I 2C-test/demo för AVR-enheter.
mpu6050.h | MPU-6050 (Accelerometer, mm.) för AVR-enheter.
i2cmaster.h | I 2C-bibliotek för AVR-enheter.
ssd1306.c | Kod som använt sig av i2cmaster.h för att skriva ut text till display.

Koden studerades med bland annat texteditorn Atom och i utvecklingsmiljön Atmel Studio.

I Atmel Studio finns möjligheten att automatiskt gå till den fil där ett makro, en funktion eller en variabel är definierad. I bilden nedan utförs detta på funktionen fabs();

Figur 6 Gå till en implementation av ett makro, variabel eller funktion.

### 2.5 Prototyp 1

Projektets första prototyp, kallad prototyp 1, byggdes för att säkerställa att en stegräknare kunde konstrueras med en MPU-9250. MPU-enheten kopplades direkt till en Arduino UNO-enhet via en breadboard.


Figur 7 Uppkoppling av MPU-9250 till Arduino UNO

Koden för prototyp 1 baserades på kod skapad av JohnChi ¹
, som skriver ut värden från MPU-6050-enheter till Arduino-utvecklingsmiljöns Serial Monitor. Koden skrevs om så att endast värden för acceleration hämtades, dessa användes för stegräkning.

Funktionsbiblioteket wire.h används för att ansluta MPU-n via I²C till Arduino-enheten. Portarna A4 och A5 används för SDA och SCL, respektive. En resistor med resistansvärdet 560 Ohm används för att ta ner spänningsmatningen till MPU-n från 5V till ca 3V. Enligt tillverkarens hemsida²
ska enheten
drivas med 2.4 – 3.6 V.

En bärbar dator användes för strömförsörjning och för att avläsa Serial Monitor. Avläsning av steg gjordes genom att placera prototypen i en byxficka och promenera runt.


Figur 8 Utskrift av stegräkning till Serial Monitor

En vibrationssensor testades också för att avläsa steg. Även om den kunde användas för avläsning, valdes den att inte användas, då MPU-enheten ansågs vara mer pålitlig.

Prototyp 1 färdigställdes 2017-03-21

Kopplingsschema för prototyp 1 kan ses i rapportens bilagor.

1
Se länk i kapitel 1.4.4
2
Se länk i kapitel 1.4.4

### 2.6 Prototyp 2

Vid byggnation av prototyp 2 användes en Atmega328p MCU.

En breadboard användes för samtliga inkopplingar innan sammanlödning av enheter påbörjades.

Initialt anslöts MPU-9250-enheten till mikrokontrollerns I

2C-anslutningar, med pull up-resistorer på båda kanaler. För att kunna indikera att MPU-n fungerade korrekt användes en blå LED. Lysdioden sattes att lysa när accelerationsdata från MPU-n översteg ett visst värde.

När displayen anslöts och kunde användas för att visa diverse data från MCU-n, blev lysdioden överflödig och användes inte längre.

En kristalloscillator på 16 MHz kopplades MCU-enhetens anslutningar 9 och 10. Dessa anslutningar används för inkoppling av externa kristalloscillatorer. Kristalloscillatorn användes för att öka klockfrekvensen på MCU-n. Enheten upplevdes också som stabilare.

När uppkopplingen på breadboard ansågs vara fungerande löddes MCU-n fast via en sockel på en kopplingsplatta. Tre stycken kontakter löddes till MCU-ns I²C-kanaler. Dessa kontakter går att använda för att koppla in olika enheter med I²C-stöd.

På displayen och MPU-enheten löddes kontakter fast, för anslutning till kontakterna på kopplingsplattan.

På kopplingsplattan löddes även övriga komponenter dit: kristalloscillator, resistorer och kondensatorer.


Figur 9 Lödda och urkopplade modulära komponenter

Ett en kasserad optisk mus användes som hölje för prototyp 2. Eltejp och smältlim användes för sammanfogning.


Figur 10 Prototyp 2 med hölje, framsida med display | Figur 11 Prototyp 2 med hölje, baksida med batteri

Efter sammanställning av prototyp 2, plockades delarna ut ur höljet, och en ytterligare anslutning löddes på kopplingsplattan, för programmering av mikroprocessorn via AVR pocket programmer.


Figur 12 Placering av fastlödda komponenter på kopplingsplatta


Figur 13 Komponenter lödda på kopplingsplatta, baksida

Prototyp 2 används som bas för den färdigställda produkten.

Kopplingsschema för prototyp 2 kan ses i rapportens bilagor.

### 2.7 Slutgiltig produkt

Text

### 2.8 Stegräknarens funktion

Vid stegräknarens start kalibreras den genom att hämta 20 stycken värden för acceleration från MPU-9250-enheten. Stegräknaren bör ligga stilla under kalibreringen. Medelvärdet av de 20 värdena sätts till att vara stegräknarens värde för när den är passiv. Detta värde benämns som idle-värde.

Meddelandet "Calibrating.." visas på stegräknarens display under kalibreringen. När kalibreringen är färdig visas meddelandet "Idle.." på displayen, och stegräknaren kan börja användas.

Under användning hämtas accelerationsdata kontinuerligt från MPU-9250-enheten. Skillnaden mellan detta värde och idle-värdet beräknas som ett absolutvärde. Om skillnaden mellan dessa två värden överskrider ett visst satt tröskelvärde, så anses det att ett steg har tagits.

Vid varje taget steg uppdateras stegräknarens display med det totala antalet tagna steg.

Stegräknarens display sätts automatiskt i sömnläge om inget steg har tagits på ca 30 sekunder. Displayen vaknar automatiskt när ett steg tas.

### 2.9 Projektets kod

Utförligare kommentering av koden finns i källkodsfilen main.c.

3

2.9.1 Egeninkluderade standardbibliotek
Bibliotek | Beskrivning
<avr/io.h> | Diverse I/O definitioner för mikrokontrollern.
<util/delay.h> | För funktionen _delay_ms() som pauserar programmet i angiver antal millisekunder.
<avr/interrupt.h> | Används för funktionen sei(), som aktiverar interrupt på mikrokontrollern. Behövs för kommunikation med MPU-9250.
<math.h> | Diverse matematikfunktioner och macron. Används för funktionen fabs(), som ger absolutvärdet av ett tal.
<stdio.h> | För funktionen sprintf(), som skriver en formaterad textsträng till en char-array. Används för att skriva ut stegräkning till display.

2.9.2 Inkluderade icke-standardbibliotek
Flera av dessa bibliotek har egna inkluderingar av olika standardbibliotek.
Bibliotek | Beskrivning
"i2chw/i2cmaster.h" I2C master library using hardware TWI interface Skapat av Peter Fleury | I 2C-funktionalitet för AVR-enheter. För kommunikation mellan mikrokontroller och enheter anslutna till dess I 2C-portar SDA/SCL.
"mpu6050/mpu6050.h" MPU6050 lib 0x02 Skapat av Davide Gironi | 2C. Viss egen För accelerometer-enheten, via I kod har skrivits genom att bryta ut kod från detta bibliotek.
"u8g/u8g.h" Universal 8bit Graphics Library Skapat av olikraus | Funktionsbibliotek till AVR för diverse displayer.

3
För länk, se kapitel 1.4.1

2.9.3 Macron definierade i main.c
Macron som är definierade i main.c
Namn | Värde | Beskrivning
X | 0x3B | Address för accelerometerdata i X-riktning i MPU-9250
Y | 0x3D | Address för accelerometerdata i Y-riktning i MPU-9250
Z | 0x3F | Address för accelerometerdata i Z-riktning i MPU-9250
STEP_ACC_TRIGGER | 2.3 | Tröskelvärde för acceleration, att bestämma om ett steg har tagits.
SET_IDLE_LOOP | 20 | Antal värden som ska hämtas från accelerometern för att bestämma “idle”-värde. Det värde som accelerometern ger när den anses ligga stilla.
DISPLAY_LINE_HEIGHT | 16 | Pixelhöjd för en rad på displayen. Används vid utskrift av text.
DISPLAY_MIDDLE | (DISPLAY_LINE_HEIGHT * 2 + 2) | Ungefärligt pixelvärde för utskrift på displayens mitt.
DISPLAY_SLEEP_DELAY | 3000 | När värdet i variabeln displaySleepTimer når detta värdet sätts displayen i sömnläge.

Macrot F_CPU behövs vara angivet för standardbiblioteket delay.h, detta sätts i kodprojektets egenskaper till F_CPU=16000000, i programmet Atmel Studio.


Figur 14 Kodprojektets egenskaper – Defined symbols

2.9.4 Macron från andra bibliotek
Macron som används i main.c, vilka är definierade i andra bibliotek.
Namn | Värde | Från bibliotek | Beskrivning
MPU6050_ADDR | (0x68 <<1) | mpu6050.h | I²C-address för MPU-9250
MPU6050_AGAIN | 16384.0 | mpu6050.h | Värde för att omvandla ”rå” accelerationsdata från MPU-9250 till g-krafter.
I2C_WRITE | 0 | i2cmaster.h | Datariktning för I²C - för att skriva till en enhet.
I2C_READ | 1 | i2cmaster.h | Datariktning för I²C - för att läsa från en enhet

2.9.5 Variabler
Variabler i källkoden, sätts i main.c
Namn | Beskrivning
uint16_t steps | Håller stegräkning.
double accIdle | Värde som sätts vid programmets uppstart, håller det värde som accelerometern ger när den ligger helt stilla.
double accCombined | Sammansatt accelerationsvärde från X- Y- och Z-riktning.
double accX, accY, accZ | Värden för acceleration i X- Y- och Z-riktning.
int displaySleeping | Håller displayens sömnläge, sätts till 1 om displayen är i sömnläge, annars 0.
int displaySleepTimer | Används som timer för displayens sömnläge. Ökar med 1 för varje varv i programmets huvudloop.
u8g_t u8g | Struct för biblioteket Universal 8bit Graphics Library, för display.

2.9.6 Funktioner
Egenskrivna funktioner i källkoden
Namn | Beskrivning
double getAcc(int addr); | Hämtar accelerationsdata från MPU och ger värdet i retur. Som argument tar funktionen adressen till det register som ska läsas. Dessa adresser är definierade som macron X, Y och Z.
void drawSteps(uint16_t steps); | Skriver ut aktuellt antal steg till displayens mitt, som "Steps: x"
void drawString(char * string, int line); | Skriver ut en text till displayen. Texten ges som argument till funktionen, i form av en pekare till en char-sträng. Line är den rad på displayen där texten ska visas.
void setAccIdle(); | Sätter ett värde till den globala variabeln accIdle. Funktionen körs endast en gång vid varje uppstart av programmet.
double getAccXYZ(void); | Använder sig av funktionen getAcc() för att hämta accelerationsdata från X-, Y- och Z-riktningen. Det adderade värdet ges i retur.
void toggleDisplaySleep(void); | Sätter displayen i sömnläge, eller väcker displayen.
u8g_t u8g | Struct för biblioteket Universal 8bit Graphics Library, för display.

2.9.7 Main-funktionen
I detta kapitel beskrivs grundläggande vad som händer i programmets kod

Interrupt-funktionen aktiveras för MCU-enheten, detta behövs för att MPU-enheten ska fungera korrekt. Sedan initieras MPU-9250-enheten, med funktion från mpu6050.h

Displayen initieras och teckensnitt bestäms, funktioner från u8g.h

Texten ”STEPCOUNTER” visas på displayens mitt i en sekund.

Idle-värde för accelerometern sätts.

Programmets huvud-loop startar.

Ett kombinerat accelerationsvärde för X- Y- och Z-riktningar hämtas

Om skillnaden mellan det hämtade värdet och idle-värdet överskrider tröskelvärdet för att trigga ett steg, skriv ut antalet steg till displayen. Om displayen är i sömnläge, väck den.


Sätt display i sömnläge om timer har nått värde


Slut loop.

## 3 Diskussion och slutsats

I denna del utförs diskussioner och tankegångar angående projektets genomförande och resultat

## 4 Bilagor

### 4.1 Kopplingsschema för prototyp 1


### 4.2 Kopplingsschema för prototyp 2


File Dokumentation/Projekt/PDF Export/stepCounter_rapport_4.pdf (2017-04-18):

# Stegräknare

Programmering av inbyggda system Mjukvaruutvecklare inbyggda system 2016

EJ FÄRDIG RAPPORT

Dennis Bunne
Simon Karlsson
Johan Kämpe

Stegräknare | 2017-04-10

# Sammanfattning

Skrivs när rapport är klar.

# Innehållsförteckning

Sammanfattning | 2
Innehållsförteckning | 3
1 Inledning | 4
1.1 Syfte | 4
1.2 Bakgrund | 4
1.2.1 Stegräknare | 4
1.2.2 I²C | 4
1.2.3 X-Y-Z | 4
2 Genomförande och resultat | 5
2.1 Använd programvara | 5
2.2 Komponentlista | 6
2.3 Utveckling av stegräknaren | 7
2.3.1 Prototyp 1 | 7
2.3.2 Prototyp 2 | 9
2.4 Stegräknarens funktion | 12
2.5 Kod | 13
2.5.1 Använda icke-standardbibliotek | 13
2.5.2 Globala variabler | 13
2.5.3 Definitioner / macron | 14
2.5.4 Funktioner | 14
3 Referenser | 15
4 Slutsats | 15

# 1 Inledning

## 1.1 Syfte

Syftet med projektet är att tillverka en bärbar, batteridriven stegräknare. Stegräknaren ska vara modulär. Det vill säga, att det ska gå att ansluta och ta bort enheter, display, WiFi-modul m.m.

Initialt används en display för att visa antal steg. Stegen ska avläsas med hjälp av
en accelerometer, eller alternativt med en vibrations sensor.

Stegräknaren kan senare utökas med hastighetsmätare, tidräkning, ESP-modul eller bluetooth-modul för att skicka data m.m, om funktionen med stegräkning fungerar korrekt.

## 1.2 Bakgrund

### 1.2.1 Stegräknare

En stegräknare är en, vanligtvis portabel, enhet som mäter hur många steg en människa tar. Den kan användas vid exempelvis löpning eller promenad. Eller för att se hur många steg en person tar under en dag. Stegräknare kan också kallas pedometer.

### 1.2.2 I²C

I²C, Inter-Integrated Circuit, är ett sätt att koppla enheter till moderkort, inbyggda system, mobiltelefoner eller andra enheter. Kommunikation sker via två ledare, SDA (Serial Data Line, datasignal) och SCL (Serial Clock, klocksignal). Flera I²C-enheter kan anslutas till samma SDA-och SCL-ledare.

### 1.2.3 X-Y-Z

X, Y och Z används inom projektet för att beskriva riktningar i en tredimensionell miljö. MPU-9250-enheten har sensorer för acceleration i dessa tre riktningar. När enheten förs åt ett visst håll mäts rörelsens acceleration i denna riktning.

X- Y- och Z-riktningar.


# 2 Genomförande och resultat
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

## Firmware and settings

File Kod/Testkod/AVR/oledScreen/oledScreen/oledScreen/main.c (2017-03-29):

#include <avr/io.h>
#include <string.h>
#include <avr/interrupt.h>
#include <avr/pgmspace.h>
#define F_CPU 1000000UL

#include <util/delay.h>
#include "i2chw/i2cmaster.h"
#include "myfont/myFont.h"

//#define DevSSD1306  0xA2      // device address of EEPROM 24C02, see datasheet
#define DevSSD1306  0x78      // device address of SSD1306 OLED, uses 8-bit address (0x3c)!!!

// the memory buffer for the LCD

static uint8_t buffer[(128 * 64) / 8] = {
    0xAA, 0x55, 0xAA, 0x55, 0xAA, 0x55, 0xAA, 0x55, 0xAA, 0x55, 0xAA, 0x55, 0xAA, 0x55, 0xAA, 0x55,
    0xAA, 0x55, 0xAA, 0x55, 0xAA, 0x55, 0xAA, 0x55, 0xAA, 0x55, 0xAA, 0x55, 0xAA, 0x55, 0xAA, 0x55,
    0xAA, 0x55, 0xAA, 0x55, 0xAA, 0x55, 0xAA, 0x55, 0xAA, 0x55, 0xAA, 0x55, 0xAA, 0x55, 0xAA, 0x55,
    0xAA, 0x55, 0xAA, 0x55, 0xAA, 0x55, 0xAA, 0x55, 0xAA, 0x55, 0xAA, 0x55, 0xAA, 0x55, 0xAA, 0x55,
    0xAA, 0x55, 0xAA, 0x55, 0xAA, 0x55, 0xAA, 0x55, 0xAA, 0x55, 0xAA, 0x55, 0xAA, 0x55, 0xAA, 0x55,
    0xAA, 0x55, 0xAA, 0x55, 0xAA, 0x55, 0xAA, 0x55, 0xAA, 0x55, 0xAA, 0x55, 0xAA, 0x55, 0xAA, 0x55,
    0xAA, 0x55, 0xAA, 0x55, 0xAA, 0x55, 0xAA, 0x55, 0xAA, 0x55, 0xAA, 0x55, 0xAA, 0x55, 0xAA, 0x55,
    0xAA, 0x55, 0xAA, 0x55, 0xAA, 0x55, 0xAA, 0x55, 0xAA, 0x55, 0xAA, 0x55, 0xAA, 0x55, 0xAA, 0x55,
    0xAA, 0x55, 0xAA, 0x55, 0xAA, 0x55, 0xAA, 0x55, 0xAA, 0x55, 0xAA, 0x55, 0xAA, 0x55, 0xAA, 0x55,
    0xAA, 0x55, 0xAA, 0x55, 0xAA, 0x55, 0xAA, 0x55, 0xAA, 0x55, 0xAA, 0x55, 0xAA, 0x55, 0xAA, 0x55,
    0xAA, 0x55, 0xAA, 0x55, 0xAA, 0x55, 0xAA, 0x55, 0xAA, 0x55, 0xAA, 0x55, 0xAA, 0x55, 0xAA, 0x55,
    0xAA, 0x55, 0xAA, 0x55, 0xAA, 0x55, 0xAA, 0x55, 0xAA, 0x55, 0xAA, 0x55, 0xAA, 0x55, 0xAA, 0x55,
    0xAA, 0x55, 0xAA, 0x55, 0xAA, 0x55, 0xAA, 0x55, 0xAA, 0x55, 0xAA, 0x55, 0xAA, 0x55, 0xAA, 0x55,
    0xAA, 0x55, 0xAA, 0x55, 0xAA, 0x55, 0xAA, 0x55, 0xAA, 0x55, 0xAA, 0x55, 0xAA, 0x55, 0xAA, 0x55,
    0xAA, 0x55, 0xAA, 0x55, 0xAA, 0x55, 0xAA, 0x55, 0xAA, 0x55, 0xAA, 0x55, 0xAA, 0x55, 0xAA, 0x55,
    0xAA, 0x55, 0xAA, 0x55, 0xAA, 0x55, 0xAA, 0x55, 0xAA, 0x55, 0xAA, 0x55, 0xAA, 0x55, 0xAA, 0x55,
    0xAA, 0x55, 0xAA, 0x55, 0xAA, 0x55, 0xAA, 0x55, 0xAA, 0x55, 0xAA, 0x55, 0xAA, 0x55, 0xAA, 0x55,
    0xAA, 0x55, 0xAA, 0x55, 0xAA, 0x55, 0xAA, 0x55, 0xAA, 0x55, 0xAA, 0x55, 0xAA, 0x55, 0xAA, 0x55,
    0xAA, 0x55, 0xAA, 0x55, 0xAA, 0x55, 0xAA, 0x55, 0xAA, 0x55, 0xAA, 0x55, 0xAA, 0x55, 0xAA, 0x55,
    0xAA, 0x55, 0xAA, 0x55, 0xAA, 0x55, 0xAA, 0x55, 0xAA, 0x55, 0xAA, 0x55, 0xAA, 0x55, 0xAA, 0x55,
    0xAA, 0x55, 0xAA, 0x55, 0xAA, 0x55, 0xAA, 0x55, 0xAA, 0x55, 0xAA, 0x55, 0xAA, 0x55, 0xAA, 0x55,
    0xAA, 0x55, 0xAA, 0x55, 0xAA, 0x55, 0xAA, 0x55, 0xAA, 0x55, 0xAA, 0x55, 0xAA, 0x55, 0xAA, 0x55,
    0xAA, 0x55, 0xAA, 0x55, 0xAA, 0x55, 0xAA, 0x55, 0xAA, 0x55, 0xAA, 0x55, 0xAA, 0x55, 0xAA, 0x55,
    0xAA, 0x55, 0xAA, 0x55, 0xAA, 0x55, 0xAA, 0x55, 0xAA, 0x55, 0xAA, 0x55, 0xAA, 0x55, 0xAA, 0x55,
    0xAA, 0x55, 0xAA, 0x55, 0xAA, 0x55, 0xAA, 0x55, 0xAA, 0x55, 0xAA, 0x55, 0xAA, 0x55, 0xAA, 0x55,
    0xAA, 0x55, 0xAA, 0x55, 0xAA, 0x55, 0xAA, 0x55, 0xAA, 0x55, 0xAA, 0x55, 0xAA, 0x55, 0xAA, 0x55,
    0xAA, 0x55, 0xAA, 0x55, 0xAA, 0x55, 0xAA, 0x55, 0xAA, 0x55, 0xAA, 0x55, 0xAA, 0x55, 0xAA, 0x55,
    0xAA, 0x55, 0xAA, 0x55, 0xAA, 0x55, 0xAA, 0x55, 0xAA, 0x55, 0xAA, 0x55, 0xAA, 0x55, 0xAA, 0x55,
    0xAA, 0x55, 0xAA, 0x55, 0xAA, 0x55, 0xAA, 0x55, 0xAA, 0x55, 0xAA, 0x55, 0xAA, 0x55, 0xAA, 0x55,
    0xAA, 0x55, 0xAA, 0x55, 0xAA, 0x55, 0xAA, 0x55, 0xAA, 0x55, 0xAA, 0x55, 0xAA, 0x55, 0xAA, 0x55,
    0xAA, 0x55, 0xAA, 0x55, 0xAA, 0x55, 0xAA, 0x55, 0xAA, 0x55, 0xAA, 0x55, 0xAA, 0x55, 0xAA, 0x55,
    0xAA, 0x55, 0xAA, 0x55, 0xAA, 0x55, 0xAA, 0x55, 0xAA, 0x55, 0xAA, 0x55, 0xAA, 0x55, 0xAA, 0x55,
    0xAA, 0x55, 0xAA, 0x55, 0xAA, 0x55, 0xAA, 0x55, 0xAA, 0x55, 0xAA, 0x55, 0xAA, 0x55, 0xAA, 0x55,
    0xAA, 0x55, 0xAA, 0x55, 0xAA, 0x55, 0xAA, 0x55, 0xAA, 0x55, 0xAA, 0x55, 0xAA, 0x55, 0xAA, 0x55,
    0xAA, 0x55, 0xAA, 0x55, 0xAA, 0x55, 0xAA, 0x55, 0xAA, 0x55, 0xAA, 0x55, 0xAA, 0x55, 0xAA, 0x55,
    0xAA, 0x55, 0xAA, 0x55, 0xAA, 0x55, 0xAA, 0x55, 0xAA, 0x55, 0xAA, 0x55, 0xAA, 0x55, 0xAA, 0x55,
    0xAA, 0x55, 0xAA, 0x55, 0xAA, 0x55, 0xAA, 0x55, 0xAA, 0x55, 0xAA, 0x55, 0xAA, 0x55, 0xAA, 0x55,
    0xAA, 0x55, 0xAA, 0x55, 0xAA, 0x55, 0xAA, 0x55, 0xAA, 0x55, 0xAA, 0x55, 0xAA, 0x55, 0xAA, 0x55,
    0xAA, 0x55, 0xAA, 0x55, 0xAA, 0x55, 0xAA, 0x55, 0xAA, 0x55, 0xAA, 0x55, 0xAA, 0x55, 0xAA, 0x55,
    0xAA, 0x55, 0xAA, 0x55, 0xAA, 0x55, 0xAA, 0x55, 0xAA, 0x55, 0xAA, 0x55, 0xAA, 0x55, 0xAA, 0x55,
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
};

void lcd_draw_char(unsigned char column, unsigned char page, unsigned char letter, uint8_t *buff);
void drawPixel(int16_t x, int16_t y);
void clearBuffer(uint8_t *buff);
void drawBuffer(uint8_t column_address, uint8_t page_address, uint8_t *buff);
void lcd_draw_string(uint8_t column, uint8_t page, char *string, uint8_t *buff);


int main(void)
{
    unsigned char ret;

    DDRB  = 0xff;                              // use all pins on port B for output
    PORTB = 0x00;                              // (LED's low & off)

    i2c_init();                                // init I2C interface

    /* write 0x75 to eeprom address 0x05 (Byte Write) */
    ret = i2c_start(DevSSD1306+I2C_WRITE);       // set device address and write mode
    if ( ret ) {
        /* failed to issue start condition, possibly no device found */
        i2c_stop();
        PORTB=0xff;                            // activate all 8 LED to show error */
    }
    else {
    /* issuing start condition ok, device accessible */
    // Init sequence for 128x64 OLED module
    i2c_write(0xAE);                    // Display Off

    i2c_write(0x00 | 0x0);            // low col = 0
    i2c_write(0x10 | 0x0);           // hi col = 0
    i2c_write(0x40 | 0x0);            // line #0

    i2c_write(0x81);                   // Set Contrast 0x81
    i2c_write(0xCF);
                                        // flips display
    i2c_write(0xA1);                    // Segremap - 0xA1
    i2c_write(0xC8);                    // COMSCAN DEC 0xC8 C0
    i2c_write(0xA6);                    // Normal Display 0xA6 (Invert A7)

    i2c_write(0xA4);                // DISPLAY ALL ON RESUME - 0xA4
    i2c_write(0xA8);                    // Set Multiplex 0xA8
    i2c_write(0x3F);                    // 1/64 Duty Cycle

    i2c_write(0xD3);                    // Set Display Offset 0xD3
    i2c_write(0x0);                     // no offset

    i2c_write(0xD5);                    // Set Display Clk Div 0xD5
    i2c_write(0x80);                    // Recommneded resistor ratio 0x80

    i2c_write(0xD9);                  // Set Precharge 0xd9
    i2c_write(0xF1);

    i2c_write(0xDA);                    // Set COM Pins0xDA
    i2c_write(0x12);

    i2c_write(0xDB);                 // Set VCOM Detect - 0xDB
    i2c_write(0x40);

    i2c_write(0x20);                    // Set Memory Addressing Mode
    i2c_write(0x00);                    // 0x00 - Horizontal

    i2c_write(0x40 | 0x0);              // Set start line at line 0 - 0x40

    i2c_write(0x8D);                    // Charge Pump -0x8D
    i2c_write(0x14);


    i2c_write(0xA4);              //--turn on all pixels - A5. Regular mode A4
    i2c_write(0xAF);                //--turn on oled panel - AF
    //drawBuffer(0,0,buffer);
    //_delay_ms(1000);
    clearBuffer(buffer);
    ////lcd_draw_char(10, 2, 'B', buffer);
    lcd_draw_string(50, 5, "JOHAN!", buffer);
    //lcd_draw_string(10, 7, "Elegant Circuits", buffer);
    drawBuffer(0,0, buffer);
    i2c_stop();
    }
    for(;;){
    }
}

void drawPixel(int16_t x, int16_t y){//, int16_t color){
//void drawPixel(int16_t x, int16_t y, int16_t color){
    buffer[x+(y/8)*128] |= (1 << (y & 7));
}

void clearBuffer(uint8_t *buff){
    memset(buff, 0, ((128 * 64)/8));
}

void drawBuffer(uint8_t column_address, uint8_t page_address, uint8_t *buff){
    i2c_write(0x21);        // column address
    i2c_write(0);           // column start address (0 = reset)
    i2c_write(127);         // column end addres (127 = reset)

    i2c_write(0x22);        // page address
    i2c_write(0);           // page start address (0 = reset);
    i2c_write(7);           // page end address

    uint8_t twbrbackup = TWBR;
    TWBR = 12;

    for (uint16_t i=0; i<((128*64)/8); i++){
        unsigned char ret = i2c_start(DevSSD1306+I2C_WRITE);   // set device address and write mode
        if ( ret ) {
            /* failed to issue start condition, possibly no device found */
            i2c_stop();
            PORTB=0xff;                            // activate all 8 LED to show error */
        }
        else {
            i2c_write(0x40);                        // set display RAM display start line register
            for (uint8_t x=0; x<16; x++){
                i2c_write(buff[i]);
                i++;
            }
            i--;
            i2c_stop();
            TWBR = twbrbackup;
        }
    }
}

void lcd_draw_char(unsigned char column, unsigned char page, unsigned char letter, uint8_t *buff){
    uint8_t ascii_offset = 32;
    for(uint8_t i=0; i<5; i++){
        buff[i+((page*128)+column)] = Ascii_1[letter-ascii_offset][i];
    }
}
void lcd_draw_string(uint8_t column, uint8_t page, char *string, uint8_t *buff){
    uint8_t i = 0;
    while(string[0] != 0){
        lcd_draw_char(column+(5*i), page, (string[0]), buff);
        string++;
        i++;
    }
}

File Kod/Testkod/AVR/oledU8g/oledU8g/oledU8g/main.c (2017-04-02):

/*

  main.c 
  
  Hello World for ATMEGA Controller

  Universal 8bit Graphics Library
  
  Copyright (c) 2012, olikraus@gmail.com
  All rights reserved.

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
  THIS SOFTWARE IS PROVIDED BY THE COPYRIGHT HOLDERS AND 
  CONTRIBUTORS "AS IS" AND ANY EXPRESS OR IMPLIED WARRANTIES, 
  INCLUDING, BUT NOT LIMITED TO, THE IMPLIED WARRANTIES OF 
  MERCHANTABILITY AND FITNESS FOR A PARTICULAR PURPOSE ARE 
  DISCLAIMED. IN NO EVENT SHALL THE COPYRIGHT HOLDER OR 
  CONTRIBUTORS BE LIABLE FOR ANY DIRECT, INDIRECT, INCIDENTAL, 
  SPECIAL, EXEMPLARY, OR CONSEQUENTIAL DAMAGES (INCLUDING, BUT 
  NOT LIMITED TO, PROCUREMENT OF SUBSTITUTE GOODS OR SERVICES; 
  LOSS OF USE, DATA, OR PROFITS; OR BUSINESS INTERRUPTION) HOWEVER 
  CAUSED AND ON ANY THEORY OF LIABILITY, WHETHER IN CONTRACT, 
  STRICT LIABILITY, OR TORT (INCLUDING NEGLIGENCE OR OTHERWISE) 
  ARISING IN ANY WAY OUT OF THE USE OF THIS SOFTWARE, EVEN IF 
  ADVISED OF THE POSSIBILITY OF SUCH DAMAGE.  
  
*/

#include "u8g/u8g.h"

//u8g_dev_ssd1306_64x48_2x_i2c

#if defined(__AVR__)
#include <avr/interrupt.h>
#include <avr/io.h>
#include <util/delay.h>
#endif


/* 
  Software SPI:
  uint8_t u8g_InitSPI(u8g_t *u8g, u8g_dev_t *dev, uint8_t sck, uint8_t mosi, uint8_t cs, uint8_t a0, uint8_t reset); 

  Hardware SPI:
  uint8_t u8g_InitHWSPI(u8g_t *u8g, u8g_dev_t *dev, uint8_t cs, uint8_t a0, uint8_t reset);

  Parallel Interface:
  uint8_t u8g_Init8Bit(u8g_t *u8g, u8g_dev_t *dev, uint8_t d0, uint8_t d1, uint8_t d2, uint8_t d3, uint8_t d4, uint8_t d5, uint8_t d6, uint8_t d7, 
    uint8_t en, uint8_t cs1, uint8_t cs2, uint8_t di, uint8_t rw, uint8_t reset);

  Visit 
    http://code.google.com/p/u8glib/wiki/device 
  for a list of valid devices (second argument of the constructor).

  The following examples will use the dogm132 device: u8g_dev_st7565_dogm132_sw_spi

  Note: The device must match the setup: For example, do not use a sw_spi device with u8g_InitHWSPI().
*/

u8g_t u8g;

void u8g_setup(void)
{  
  /*
    Test Envionment 1, ATMEGA and DOGM132 
    CS: PORTB, Bit 2
    A0: PORTB, Bit 1
    SCK: PORTB, Bit 5
    MOSI: PORTB, Bit 3
  */
  //u8g_InitSPI(&u8g, &u8g_dev_st7565_dogm132_sw_spi, PN(1, 5), PN(1, 3), PN(1, 2), PN(1, 1), U8G_PIN_NONE);

  /*
    Test Envionment 2, ATMEGA and Seeedstudio 96x96 OLED via I2C
    SCL: Port C, Bit 5
    SDA: Port C, Bit 4
  */
  
  /* activate pull-up, set ports to output, init U8glib */  
  //u8g_SetPinInput(PN(2,5)); u8g_SetPinLevel(PN(2,5), 1); u8g_SetPinOutput(PN(2,5));
  //u8g_SetPinInput(PN(2,4)); u8g_SetPinLevel(PN(2,4), 1); u8g_SetPinOutput(PN(2,4));
  //u8g_InitI2C(&u8g, &u8g_dev_ssd1327_96x96_gr_i2c, U8G_I2C_OPT_NONE);
  u8g_InitI2C(&u8g, &u8g_dev_ssd1306_128x64_i2c, U8G_I2C_OPT_NONE);
  

  /*
    Test Envionment 3, ATMEGA and NHD 192x32 ST7920 special SPI
    R/W, MOSI, Red: 	Port C, Bit 5
    RS, CS, Yellow: 	Port C, Bit 4
    EN, SCK, Green:	Port C, Bit 3
    Arguments for u8g_InitSPI are: SCK, MOSI, CS, A0, Reset
      A0 and Reset are not used.
  */
  // u8g_InitSPI(&u8g, &u8g_dev_st7920_192x32_sw_spi, PN(2, 3), PN(2, 5), PN(2, 4), U8G_PIN_NONE, U8G_PIN_NONE);
  // u8g_InitHWSPI(&u8g, &u8g_dev_st7920_192x32_hw_spi, PN(2, 4), U8G_PIN_NONE, U8G_PIN_NONE);

  
}

void sys_init(void)
{
#if defined(__AVR__)
  /* select minimal prescaler (max system speed) */
  CLKPR = 0x80;
  CLKPR = 0x00;
#endif
}

void drawSteps(int steps){
	char counterString[6] = "\0";
	itoa(steps, counterString, 10);
	u8g_FirstPage(&u8g);
	do{
		u8g_DrawStr(&u8g, 2, 16, counterString);
	}while(u8g_NextPage(&u8g));
}


int main(void){
	int counter = 0;
	sys_init();
	u8g_setup();
	u8g_SetFont(&u8g, u8g_font_fub14);
	while(counter < 1001){
		if(!(++counter % 10)){
			drawSteps(counter);
		}
	}
}

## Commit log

2017-03-20 Kopplingsschema för MPU-9250.
    [Kopplingsschema_MPU.fzz]
2017-03-20 Vibration sensor test
2017-03-20 Kopplingsschema vibrations sensor
    [Kopplingsschema_MEAS.fzz]
2017-03-20 Updated with 5V->3V
2017-03-20 Kopplingschema mpu 5V - 2.9V + test kod mpu attiny
    [Kopplingsschema_MPU_5V-2.9V.fzz]
2017-03-21 Changed stepdelay to use arduino millis()
2017-03-21 Kopplingsschema med oled
    [Kopplingsschema_MPU_OLED.fzz]
2017-03-21 i2c 2x devices test
2017-03-21 ic2 2x devices
2017-03-21 I2C library
2017-03-22 Added Arduino UNO I2C Info
2017-03-22 Wire library detailed reference link
2017-03-22 LED strip test with Arduino UNO
    Testing LED-strip to be used with I2C
2017-03-22 MPU Test with LED Atmel Studio Project
    [atmega8_mpu6050_sample.sch]
2017-03-22 Checklista och inköpslista
    [inkopslista.xlsx]
2017-03-22 OLED Display Schematics
2017-03-22 Light up LED 1sec if triggered by MPU Acc
2017-03-23 Fritzing schematics
2017-03-23 Added pullup resistor
2017-03-23 Kopplingsschema Prototyp
    [Kopplingschema_Uppvisningsprototyp.fzz]
2017-03-23 Uppdaterat kopplingsschema
    [Kopplingschema_Uppvisningsprototyp.fzz]
2017-03-25 Renamed folder
    [inkopslista.xlsx]
2017-03-25 Moved folder
    [Kopplingschema_Uppvisningsprototyp.fzz, Kopplingsschema_MEAS.fzz, Kopplingsschema_MPU.fzz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]
2017-03-25 Moved and renamed files
    [MEAS.fzz, MPU.fzz, MPU_5V-2.9V.fzz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]
2017-03-25 Moved files
    [inkopslista.xlsx]
2017-03-25 Added accelerometer
2017-03-25 Added magnetometer
2017-03-25 Sparkfun schematics
2017-03-25 Grove connectors data sheets
2017-03-25 Component physical dimension data
    For CAD
2017-03-25 AD0 pin info
2017-03-28 Förslag för stegvisning med LED
2017-04-02 Atmega328p Fusion360 CAD model
    [atmega328p v3.f3d]
2017-04-02 Render of CAD
2017-04-02 IC Socket dimensions image
2017-04-02 Socket CAD model render
2017-04-02 Grove connector female angle CAD export
    [grove_female_angle v4.f3d]
2017-04-02 Print acc data to display
2017-04-03 Offset/calibration tests
2017-04-05 Tested MPU for hardware failure
    [mpu_6050_data.ino]
2017-04-06 Photos of built prototype
2017-04-10 Kopplingsschema Prototyp 1
    [Prototyp_1.fzz]
2017-04-10 uppdaterat kopplingsschema prototyp 1
    [MPU.fzz]
2017-04-13 Inventor CAD Project
2017-04-13 Atmega Mold CAD Part
    [atmega_mold.ipt]
2017-04-13 Atmega Pin CAD Part
    [atmega_pin.ipt]
2017-04-13 Atmega MCU CAD Assembly
    [atmega.iam]
2017-04-13 Atmega CAD Parameters export
2017-04-13 Cuts for pins
    [atmega_mold.ipt]
2017-04-13 Atmega MCU CAD Assembly complete
    [atmega.iam, atmega_mold.ipt, atmega_pin-end.ipt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]
2017-04-13 Removed obsolete CAD files
    Switched CAD enviroment from Fusion 360 to Inventor 2018
    [atmega328p v3.f3d, grove_female_angle v4.f3d]
2017-04-13 Socket 28pin CAD Assembly
    [socket.iam, socket.ipt, socket_pin.ipt]
2017-04-13 Assembly for housing init
    [stepCounterHousing.iam]
2017-04-20 Display sleep timer fix
    [main.c]
